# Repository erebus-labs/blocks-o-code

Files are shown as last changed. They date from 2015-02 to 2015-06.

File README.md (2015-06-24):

blocks-o-code
=============

#A Block of Code
+ *Title:* Physical manipulators for developing and implementing short programing routines 
+ *Project Short Name:* A Block of Code (ABC)
+ *Sponsors:* 
  + [Dr. Mike Borowczak](https://www.linkedin.com/in/mborowczak) @ [Erebus Labs](http://www.erebuslabs.com)
  + [Dr. Andrea Burrows] (http://uwyo.academia.edu/AndreaBurrows) @ [University of Wyoming] (http://www.uwyo.edu/seced/faculty-staff/andrea-burrows.html)
+ *Senior Design Team:* 
  + Jacob Mickiewicz 
  + Tyler Hart
  + Daniel Frister
  + Greg Stromire
  + Nathan Bryant
+ *PSU Academic Advisor:* [Roy Kravitz](http://www.pdx.edu/directory/name/roy_kravitz) 
+ *Targeted Users:* Infants to High School aged children, parents and their educators

##About A Block of Code

Blocks of Code are connectable “blocks” that mimic a simple-grammar programming language. 

The fundamental grammar contain 4 types of blocks:
+ Value Blocks
  + numbers (ints/doubles) – stringing these blocks together forms longer numbers [0,1,2,3,4,5]; [6,7,8,9,.]
  + variables
+ Operator Blocks
  + simple binary operators (*,/,-,+,%?): 
  + equivalence operators (<,>,==, !=,<=,>=)
+ Control Blocks (start and end)
  + if structures
  + while structures
  + explicit encapsulation ( )
+ Output Blocks

##Background

Algorithms, logical constructs and the foundations of programming are generally limited to computer-based instances. No physical manipulators exist that expose children to programming as they do for number and alphabet systems, mechanics, art, etc.  Build a prototype for building blocks that can be attached through internal magnets, these magnets perform two actions 
1. physical connection and 
2. logical circuit connections.

##Current Feature List
- [x] Open Source Hardware Design & Board (can use “closed source” components: ASICs, uC, etc.)
- [x] Must Have a Multi-Chip solution – e.g. no single SoC;
- [x] Fundamental grammar functioning; assignment; binary operators; 
- [x] Open Software Repository (github)
- [x] Multi-function blocks – e.g. 6 (or 4) binary operators on a single block; depending on connections/which side “faces up” operation changes 
- [x] Separate “power” blocks

##Wish List
- [ ] Hardware cost <$3 per unit (average cost for a set 20 = $60)
- [ ] Unexposed Connectors (e.g. Magnetic  + Inductive coupling between blocks?)
- [ ] Power: Ultra Low power operation
- [ ] Power
  - [ ] Built in power source / power pack
  - [ ] Built in power source w/inductance recharge
- [ ] Computer GUI/Phone App:
  - [ ] simulate a set of blocks (pre build) 
  - [ ] take a picture of a set of blocks and execute code (they don't even have to be REAL blocks - could be paper!)

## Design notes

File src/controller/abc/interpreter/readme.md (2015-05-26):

# A Block of Code Emulator
```
usage:
    abc                  Start interactive mode
    abc /path/to/file    Run file
    abc -h               Display this help
```

Alternatively, do a full install and use a hashbang on the first line of
your script:

```
#! /usr/local/bin/abc

<your code goes here>
```

Then make your script executable with `chmod +x /path/to/your/script`. It
will be interpreted just like any other script.

## Building
Building relies on `bison` (>3.0 for '%precendence' directive)  and `xxd`
AND `flex` (and of course `make` and `gcc`, along with gnu `libc`. If
you've ever used a Makefile on your machine, you probably already have
these.

Just run `make` to build, then `sudo make install` to install. The default
path is `/usr/local/bin/abc`

### OSX Specific
Default `bison` version = 2.5 < 3.0. This will require manual update, or
installation through favorite add on package management tool (port, brew,
etc). The following assumes the use of Brew, which installs to
`/usr/local/opt/bison/lib`

```
brew tap homebrew/dupes && brew install bison
```

## Syntax
#### Blocks
* ~~**Line Start** - has an LED indicating if the statements on the line produce
an error, could also provide power.~~

* **Variable** - a list of 8 named variables (`count`, `sum`, `a`, `b`, `c`,
`x`, `y`, and `z`), selectable by pressing a button on the block to cycle
through values, with an LED showing which is currently selected.

* **Number Selection** - a small LCD screen shows a value that can go from 0.0
to 9.9 decimal, then from 10 to 99 integer by rotating an adjacent knob.

* **Operator** - a list of 6 operators (`+`, `-`, `*`, `/`, `^`, and `%`) and
their 6 compound assignment counterparts (`+=`, `-=`, `*=`, `/=`, `^=`, and
`%=`) selectable by pressing a button on the block to cycle through values, with
an LED showing which is currently selected.

* **Integer Constant** - a constant integer block for common use numbers (`1`,
`2`, `5`, and `10`).

* **IF** - starts an if-statement, must be followed by a conditional statement,
some statements, and END IF.

* **END IF** - ends the statement list for an if-statement.

* **Condition** - a list of 6 comparison operators (`==`, `!=`, `>`, `<`, `≥`,
and `≤`), selectable by pressing a button on the block to cycle through values,
with an LED showing which is currently selected.

* **WHILE** - starts a while-statement, must be followed by a conditional
statement, some statements, and END WHILE.

* **END WHILE** - ends the statement list for an while-statement.

* **Actuators** - syntactically similar to functions: take parameters
(right-adjacent blocks) and perform a task. Shown in picture:

  * `say(number)` - ~~takes a number as a parameter, uses speech synthesis to
say the number through the on-block speaker.~~ Prints to stdout.

  * ~~`blink(integer)` - takes a positive integer as a parameter, blinks the
larger on-block LED that number of times~~

* ~~**Output** - larger LCD screen can show `stdout`-type print statements,
errors and hints, or other messages after pressing the `GO` button.~~

**Total Blocks**: 35 - could remove the 8 Line Start blocks to get to 27 total blocks.

#### Connection Indicators
Blocks have connection established LEDs indicating power and/or data connection.
Some only have left and right side connections available (operators, constants,
etc) while others have left, right, top, bottom connections available
(variables, control flow) which helps guide students to start lines with the
correct type of block. This prevents lines such as:

```
+ 5 * 9 = x
```
Also, while the following is valid in some programming languages:
```
3 + y
```
the resultant value is ignored, and this layout can help prevent such
unnecessary statements.

#### Terminators
There are no semicolons or terminating whitespace (but there are curly braces to
help with proper nesting). Statements can be determined by the block with the
right connector open (o).

#### Immediate Feedback
More verbose error checking for the software implementation is a TODO item - *Tylo*

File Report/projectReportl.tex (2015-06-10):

\documentclass[12pt,a4paper]{article} 
\usepackage[latin1]{inputenc}
\usepackage{pdfpages}
\usepackage{graphicx}
\usepackage{float}
\usepackage{amsmath} 
\usepackage{amsfonts} 
\usepackage{amssymb}
\usepackage{color}
\usepackage{multicol}
\usepackage{multirow}
\usepackage{makeidx} 
\usepackage[english]{babel} 
\usepackage[hidelinks]{hyperref} 
\usepackage{array}
\usepackage{blindtext}
\usepackage{setspace}
\usepackage{parskip}
\usepackage{pstricks}
\usepackage{textcomp}
\linespread{1.1}
\begin{document}
\definecolor{PSU}{RGB}{75,125,50}
\begin{titlepage}
\begin{center}

% leave tilde after graphic, it designates par format, needed for formating
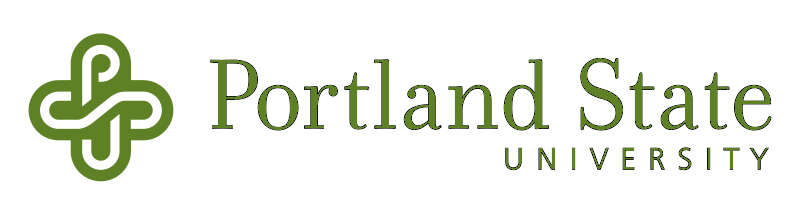
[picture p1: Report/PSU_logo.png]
~\\[.5cm]

\textsc{\LARGE \color{PSU} Maseeh College of Engineering}\\[1.5cm]

\textsc{\Large Project Summary \& Report}\\[0.5cm]

\vspace{1cm}
% Title

{ \huge \bfseries\color{PSU} A Block of Code\\[0.4cm] }
  \large Senior Capstone Project

% \hrule
\vspace{2.5cm}
% Team Members
 \begin{multicols}{2}

\begin{flushleft}
\noindent
 \large
\emph{\color{PSU}Team Members:}\\
Nathan \textsc{Bryant}\\
Daniel \textsc{Frister}\\
Tyler  \textsc{Hart}\\
Jacob   \textsc{Micikiewicz}\\
Greg    \textsc{Stromire}\\
\end{flushleft}

 \begin{flushleft}
  \large
 \emph{\color{PSU}Erebus Labs:} \\
 Dr. Mike  \textsc{Borowczak}\\
 \emph{\color{PSU}University of Wyoming}\\
 DR. Andrea \textsc{Burrows}\\
 \emph{\color{PSU}PSU Advisor:}\\
 Roy \textsc{Kravitz}
 \end{flushleft}

 \end{multicols}`
\vfill

% Bottom of the page
{\large \today}

\end{center}
\end{titlepage}
 \tableofcontents
 \vfill

\section{Abstract}
We prototyped a low-cost, tactile teaching aide capable of helping a wide range of K-12 students explore the concepts of computer programming. Using a set of physically manipulatable blocks, students can perform basic programming operations and interact with the programs they create. Verification of valid code structures provide immediate feedback for rapid learning and control of simple and fun outputs connected to the system guide students toward a goal for their projects. 

Each of our blocks is a 4-layer PCB, enclosed in an acrylic box, with an ATtiny461a microcontroller and 3 LEDs to indicate power, status, and errors. A 1M$\Omega$ potentiometer, with an attached acrylic wheel, is connected to the microcontroller\textquotesingle s ADC to act as a selector for a block\textquotesingle s particular function, or token. Each block communicates over a limited SPI bus to two adjacent blocks to determine topology, and communicates back to a main processor over a TWI global bus. Our main processor board is a BeagleBone Black with a common Debian distribution running a Python-based lexer, Bison-based parser, and C-based interpreter to run our simplified grammar. The results are supplied to an output pipeline to drive modular components such as an LCD screen or an RGB LED, as well as send feedback directly to the blocks via their onboard LEDs. 

The end product is a set of blocks that introduce computer programming to students for whom traditional teaching methods are ineffective, or would otherwise have no exposure, and encourages all students to pursue education in STEM.

\section{Introduction}
\subsection{Motivation}
Introducing students to programming and computer science is vital in our increasingly connected world. Yet the tools and educational methods to familiarize young minds to STEM subjects have not kept pace with the technologies themselves. The typical CS learning experience in front of a computer screen only engages a select few students with a compatible learning style, and often schools struggle to afford the necessary resources and computer labs. Our goal was to create an interactive learning tool that can engage a wider range of students for presenting computer science concepts.
\subsection{Proposal}
The package will be a set of twenty to thirty cubes at around two inches across on a side. The set will function as its own interface device, where the topological arrangement of the elements (blocks) will determine the program. The individual blocks must be identifiable as belonging to a specific programming-construct group, such as a simplified programming grammar. At a minimum these groups must include; numbers, variables, operators, and controls.

Additionally, where necessary, a block should be capable of indicating what value or function it has been assigned. Blocks should be easy to connect, allowing users to experiment with layouts, and also provide area-specific error feedback and thereby increasing understanding and limiting confusion.

Finally, the set should be open-source and sufficiently accessible, both by cost and teaching use, as to promote universal access and encourage development and expansion by the general public.

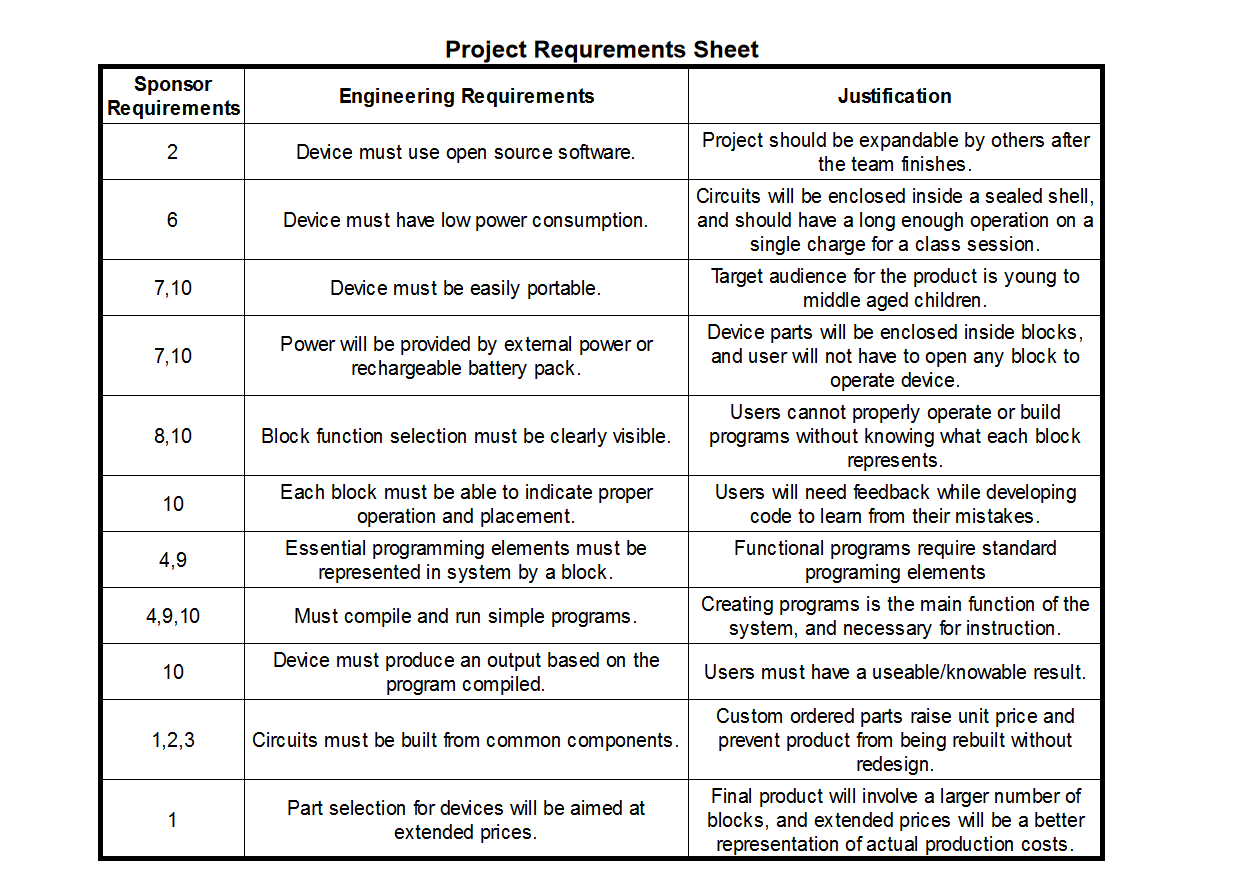
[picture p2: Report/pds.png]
\\
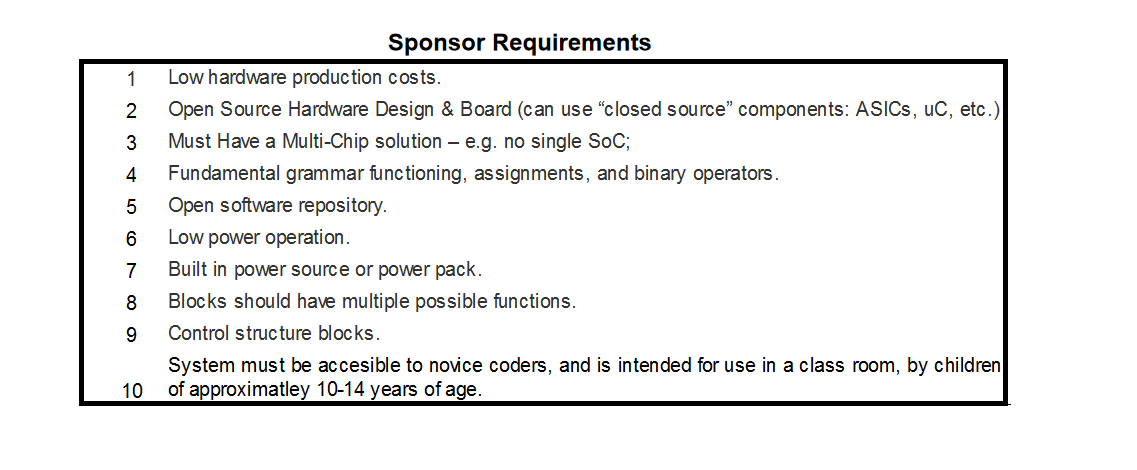
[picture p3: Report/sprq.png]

\section{Project Planning}
We identified three main elements for our system design: Physical Construction, Block Communication, and Program Interpretation. This enabled us to research and develop each subsystem in parallel with regular inter-group updates to stay unified on task. We also set several early milestones to ensure successful integration and to allow for multiple, iterative design revisions.

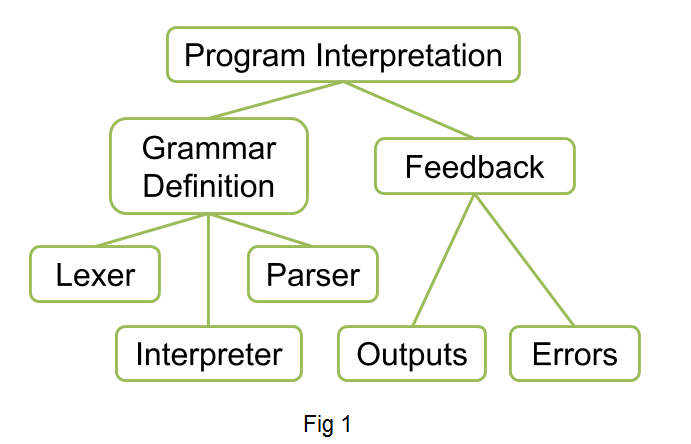
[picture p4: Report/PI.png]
\\
\newpage
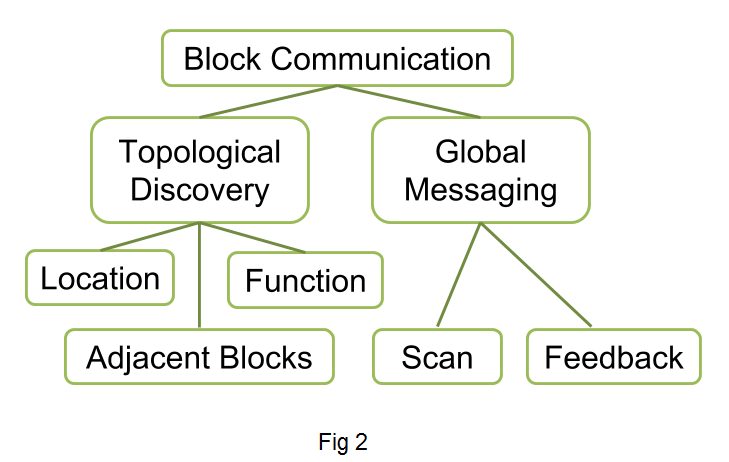
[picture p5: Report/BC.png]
\\

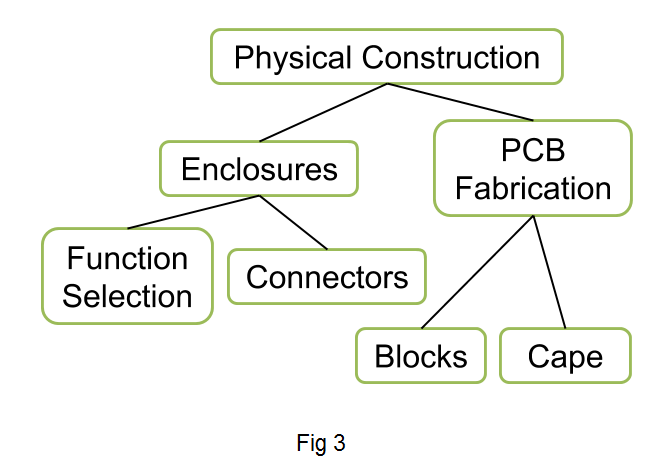
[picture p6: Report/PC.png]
\\

With these divisions the work was scheduled based on skill, interest and load leveling.

\includepdf[pages={1-}]{shed.pdf}
\section{Methods and Tools}
We utilized several methods and tools during all phases of the project, and some were used only for specific phases. We each used a mix of Windows, Macintosh, and Linux workstations throughout the project. We also used the AVR Toolchains (CrossPack, avr-gcc, avrdude) and the AVRISP MKII programmer in development, manufacturing, and testing. The BeagleBone Black was another major part of our full project cycle.

For our development phase, we utilized EagleCAD to design and layout prototype PCBs. We then moved to DesignSpark to allow us to develop 4-layer boards and reduce the surface area for a cheaper design. We employed an Arduino Uno and associated IDE to develop the TWI bus, initially with the smaller but compatible ATtiny85. We also used an Intronix Logicport 34-Channel Logic Analyzer to inspect communications, albeit much later in the process than necessary. We used a 3D printer to prototype a potential selector wheel.

During our manufacturing phase, we used the Portland State University Laboratory for Interconnected Devices to assemble both revisions of our prototype. We used their Torch T200N Reflow Oven to solder our second revision surface mount components. And we used their Full Spectrum Professional Series CO2 20x12 Laser to cut acrylic enclosures and selector wheels. We also used a handful of other Portland State tools such as soldering irons and a dremel. 

To test our final boards, we used a microscope to inspect solder connections and then a general purpose multimeter to verify conductivity and isolation. We then used an Arduino Uno\textquotesingle s regulated 3.3V output to supply power to a single and then a subset of blocks to confirm connectivity. We also wrote several scripts and test programs to explore the bounds and verify functionality of our set using an Arduino, a BeagleBone Black, and the blocks themselves.
\section{Implementation}
Our first development goal was a set of blocks that could identify their topology and return their token to a main processor. Though a \textquotesingle smart-mat\textquotesingle design was considered, we decided it would be too dimensionally restrictive. We chose AVR microcontrollers and DB-9 connectors for their ease and cost. We utilized a localized SPI communication to establish location and a global TWI bus to report the block\textquotesingle s assigned value. We then selected a Linux-based single board computer to harness existing language parsing and interpretation tools. The BeagleBone Black provided this at reduced power.

Our second set of development goals aimed to the increase block-set capability, provide portability, and expand the available output options:
\begin{itemize}
	\item User-selectable subset of functions rather than a single, hard-coded token
	\item BeagleBone Controller Cape for power distribution and control of a global reset
	\item Additional modes of output connected to the Controller Cape to support student engagement in learning programming concepts
	
\end{itemize}
Each block is controlled by an ATtiny461 microcontroller, connected to two neighbors on a local bus based on SPI, and connected to all other blocks and the BeagleBone Black on a global bus using TWI. Both of these busses, as well as power and ground, are brought onto the block via a standard DB-9 connector. The token selector wheel is mounted on a 1M$\Omega$ potentiometer which feeds into the ADC on the microcontroller.

The local bus is started from the BeagleBone and initiates a handshake with the block connected below it. When the handshake completes, a vector is passed indicating the x- and y-coordinates of the sending block. The receiving block increments the vector based on whether the sending block is signaling from the above or the left line of the receiving block, and then stores and sends the incremented vector to the next block. The received vector is then translated into the TWI address on the global bus. The BeagleBone Black is able to query each block which responds with information on its adjacent blocks, its wheel category, and its current ADC value. The BeagleBone Black lexer uses this response data to construct a topology of the current block arrangement. It then passes this information to a parser and interpreter to generate the appropriate output such as driving a LCD screen.
\subsection{Block}
    The primary function of each block is to report back to the main processor board its own user-selected function as well as its adjacent blocks. This allows the main processor to collect the tokens and topological information necessary for constructing the user-generated program. A block progresses linearly through a series of states as outlined in the state diagram, Fig 4, on the following page.
  \subsubsection{Adjacent Blocks}  
  First, the block will execute an initialization sequence that includes outputting to and reading from its adjacency lines. In typical usage, the blocks are built in a top-down orientation. A pair of slave-select pins, connected to the right and bottom connectors, are designated temporarily as inputs with their internal pull-up resistors enabled. Another pair of slave-select pins, connected to the left and top connectors, are designated temporarily as outputs and immediately pulled low. 
  
  For an example, consider the top block in Fig 5. If the block reads its adjacency pins and finds that its h\_out line (horizontal output) is HIGH, then it has no block connected to its right (again, in a top-down orientation). If it reads its v\_in is LOW, then a block is present below it. These values are stored and supplied to the main processor board in a global bus response (see TWI Commands).
  
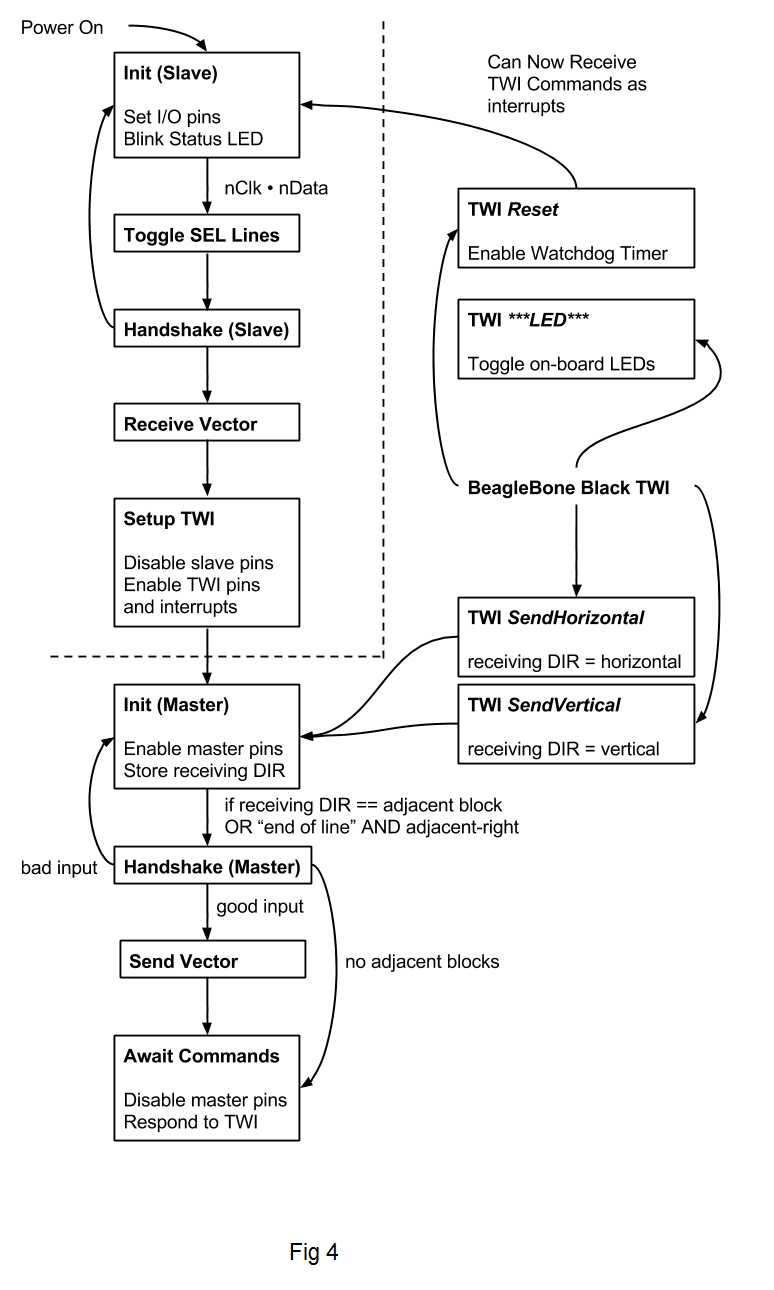
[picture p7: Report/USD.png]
    \\
    
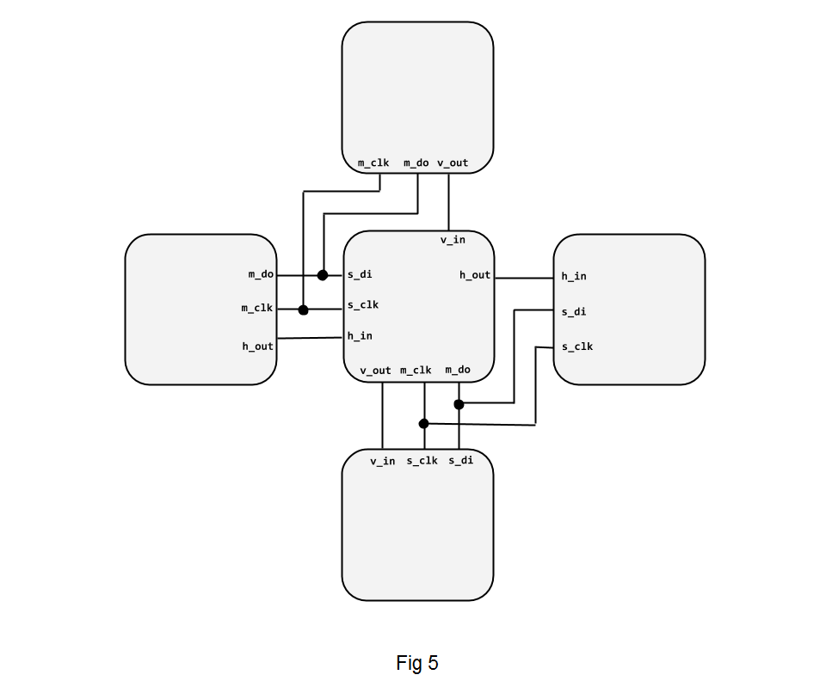
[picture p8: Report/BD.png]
 
 \subsubsection{Handshake}
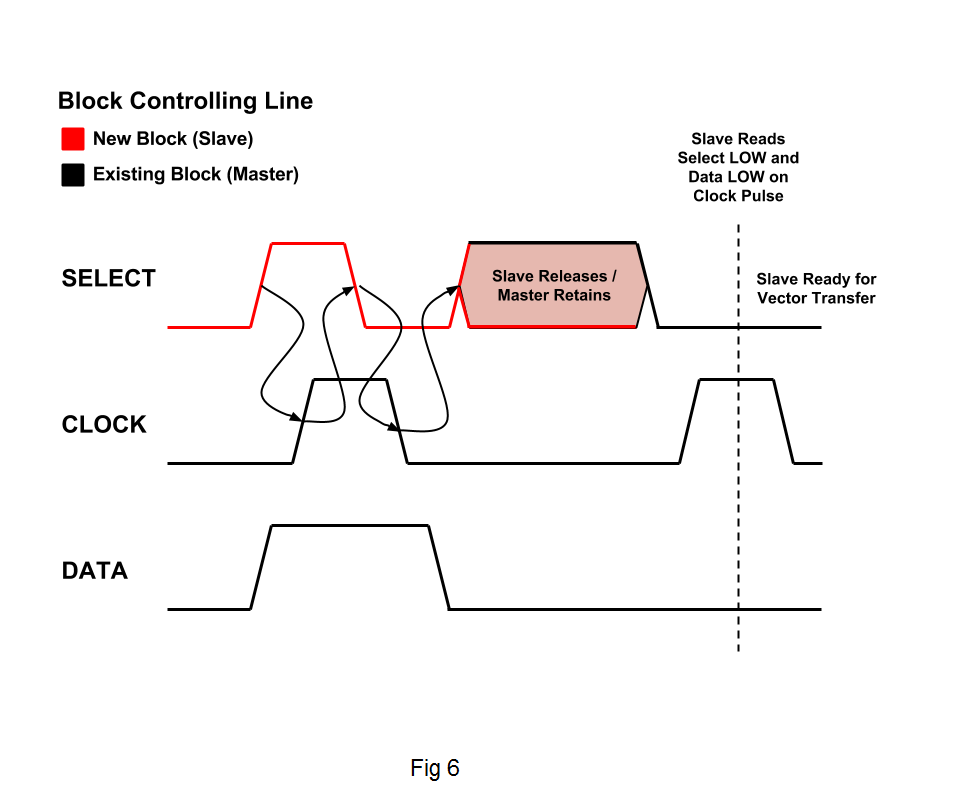
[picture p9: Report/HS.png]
 \newpage 
 After the block is powered on and has executed its initialization sequence, including determining adjacent blocks, it prepares for a custom handshake to initiate a SPI transmission. Shown above is this handshake, where the just-powered-on block is considered the slave, and another block or the BeagleBone Black is considered the master. 
 
 \begin{enumerate}
 	\item First, the block will wait for the shared clock and data lines to go LOW. This will signal the block to start toggling its own select lines (v\_in and h\_in). 
 	\item The master will then respond to the toggle that it sees (either horizontally or vertically) by bringing clock and data HIGH. 
 	\item This triggers the select line LOW again and the clock and data lines again follow. 
 	\item Next, the slave block brings its select line HIGH yet again but then releases control of it by switching the pin to an input and enable its internal pull-up resistor. 
 	\item The master waits a short delay after seeing that rising edge then it changes its corresponding select line from an input to an output and pulls the line LOW. 
 	\item A final clock pulse acts as a verification of the completed sequence before both blocks are prepared for a traditional SPI transmission.
 \end{enumerate}
 
 It is possible that an adjacent block could see the same clock and data lines go LOW and in fact complete almost the entire sequence. But the corresponding select line would not be held low on that final clock pulse and thus that block would recognize that the sequence was not meant for it, and reset its state. The same is true for any other sequence of edges that doesn't follow here -- it would be considered bad input and cause a reset to initial handshake state.
 \subsubsection{SPI Transmission}
 Once a block has completed its handshake, it is prepared to receive data over a three-wire SPI protocol. This means there is no MISO signal involved. After the data is received, the block is able to continue to send the data to adjacent blocks as necessary. It will continue the direction it was originally sent (e.g. if received from above, send below; if received from the left, send right). 

 It will also recognize when it is considered the \textquotesingle end of the line\textquotesingle  , which is considered the block with x-coordinate of 0 and no blocks connected below it. In this special case, it will then send to the right if there is a block present. 
 Finally, a block will send in the vertical or horizontal directions on command from the global TWI bus (see TWI Commands). 

 Below is a screen capture from a logic analyzer showing 3 different SPI transmissions (in this example, blocks are implemented in a bottom-up orientation). The first transmission is to the current block which is acting as a slave and receiving data. The handshake begins at about the -200ms mark and completes roughly at -135ms mark. The actual transfer is shortly after that. The second handshake begins immediately and two lines do in fact follow the sequence, but only one has its line low when a second clock pulse \textquotesingle confirms\textquotesingle  the exchange. Finally, a TWI command is issued at about the -10ms mark to complete that last SPI transmission.\\
 
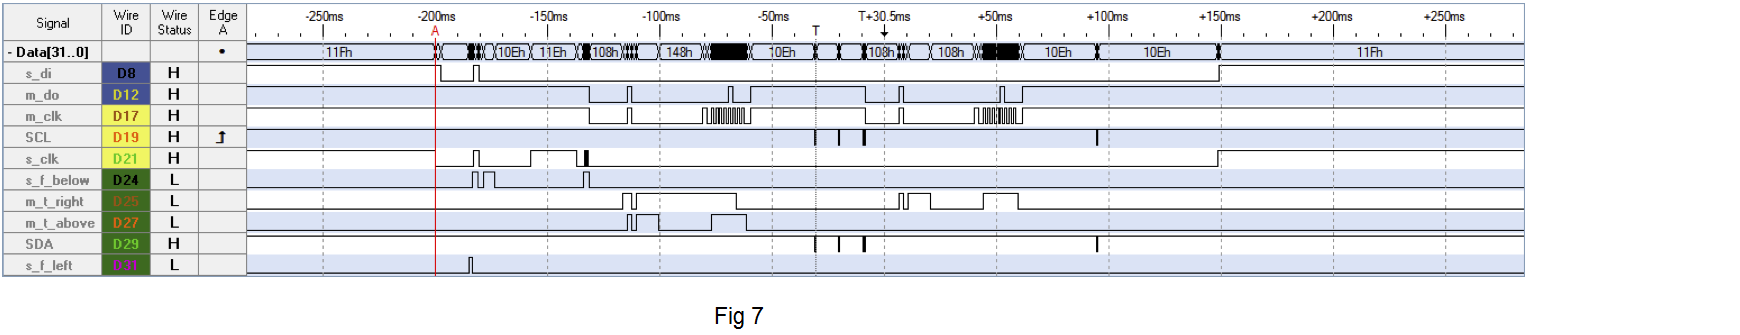
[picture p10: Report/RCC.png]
 
  The data transferred is an encoded vector indicated the sending-block\textquotesingle s coordinates in the xy-plane of the user-program\textquotesingle s topology: the first 3 bits are the x-coordinate, and the next 4 bits are the y-coordinate. The receiving block will add 1 to the x- or y-coordinate it received, depending on from which direction it was sent. If an overflow will occur (e.g. if the block receives a x-coordinate of 7 from the left, it would increment to 8 which would overflow beyond the allotted 3 bits), then the process is aborted and an error indicating LED will blink to indicate the error condition. Otherwise, this encoded and incremented vector becomes the address of this block for a Two-Wire Interface global bus.
  
  \subsubsection{TWI Commands}
  The TWI interface allows targeted commands to trigger a handful of actions. The BeagleBone Black issues a TWI read request indicating an address (block) and a register (command). These numbers act as virtual registers on the block and are captured to issue tasks in a work queue. Below is a table of all the implemented actions. 
  
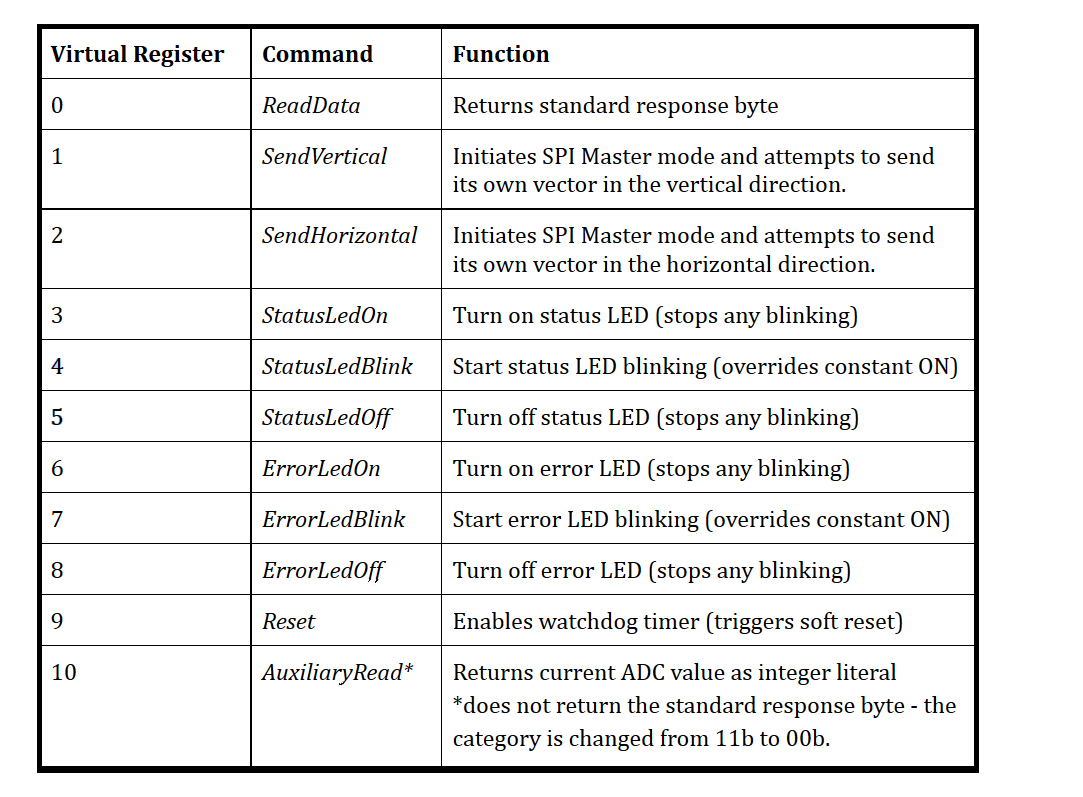
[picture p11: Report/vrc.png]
  
  Each command (except for number 10) returns a response byte that shows the current status of the addressed block. This byte is described below:
    
    
    \newpage
    The most significant two bits are flags indicating if the current block has adjacent blocks connected in the vertical and horizontal directions respectively. The next two bits identify the category (or wheel) that is used for this block. And finally, the remaining four bits are the most significant 4 bits from the ADC read from the potentiometer. This indicates the user-selected token and, combined with the category identifier, indicates the exact token to be used in the parser. 
    
    \subsection{Processor Board}
    \subsubsection{Lexer}
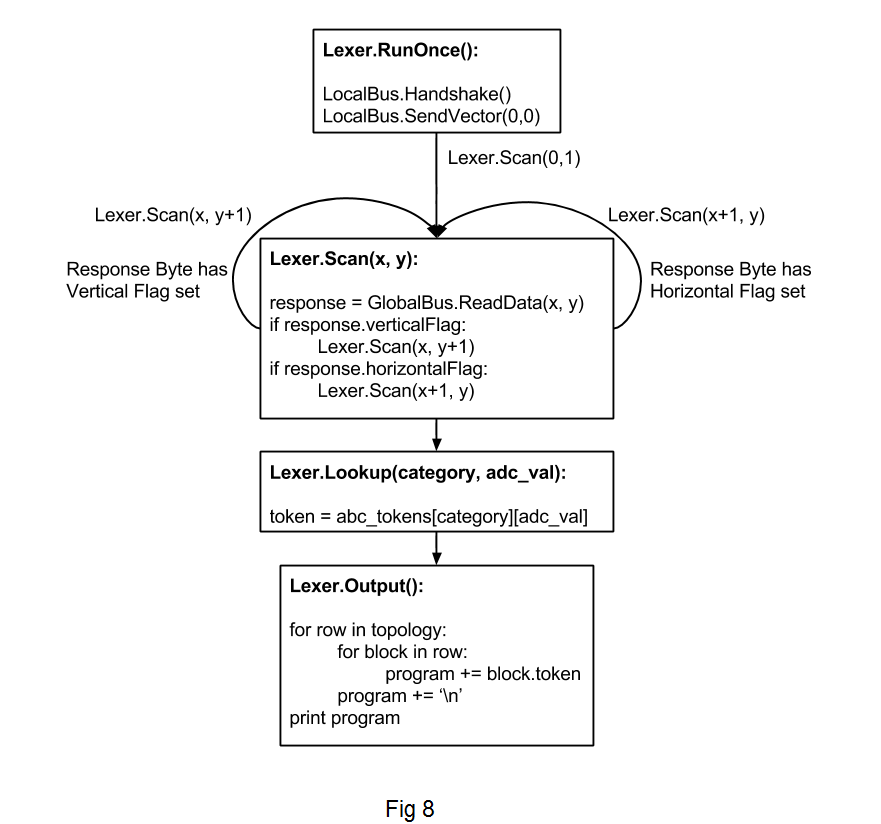
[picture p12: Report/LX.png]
    
    The lexer on the BeagleBone Black utilizes both the local SPI-based bus as well as the global TWI-based bus. The BeagleBone Black initiates a standard handshake, as described above, and sends its own coordinate of (0, 0) to the connected block. This starts a chain of sending vectors to the \textquotesingle end of the line.\textquotesingle   The lexer then uses the TWI to query the first block with a ReadData command, and recursively traverses the topology according to the vertical and horizontal adjacency flags in the response byte. 

    For each block response it receives with the vertical flag set, it queries the next vertical address until it receives a response without that flag set. It then sends a SendHorizontal command to the next block with a x-coordinate of zero and a horizontal adjacency flag set. The lexer queries that row until it gets to the end and then sends the next SendHorizontal command as necessary. This collects all the blocks (including their categories and ADC values). Each block\textquotesingle s ADC value and category is used as keys to a master token lookup table, shown in the table on the following page.     The lexer then prints a string constructed from the mapped tokens to stdout which is captured by the parser / interpreter.

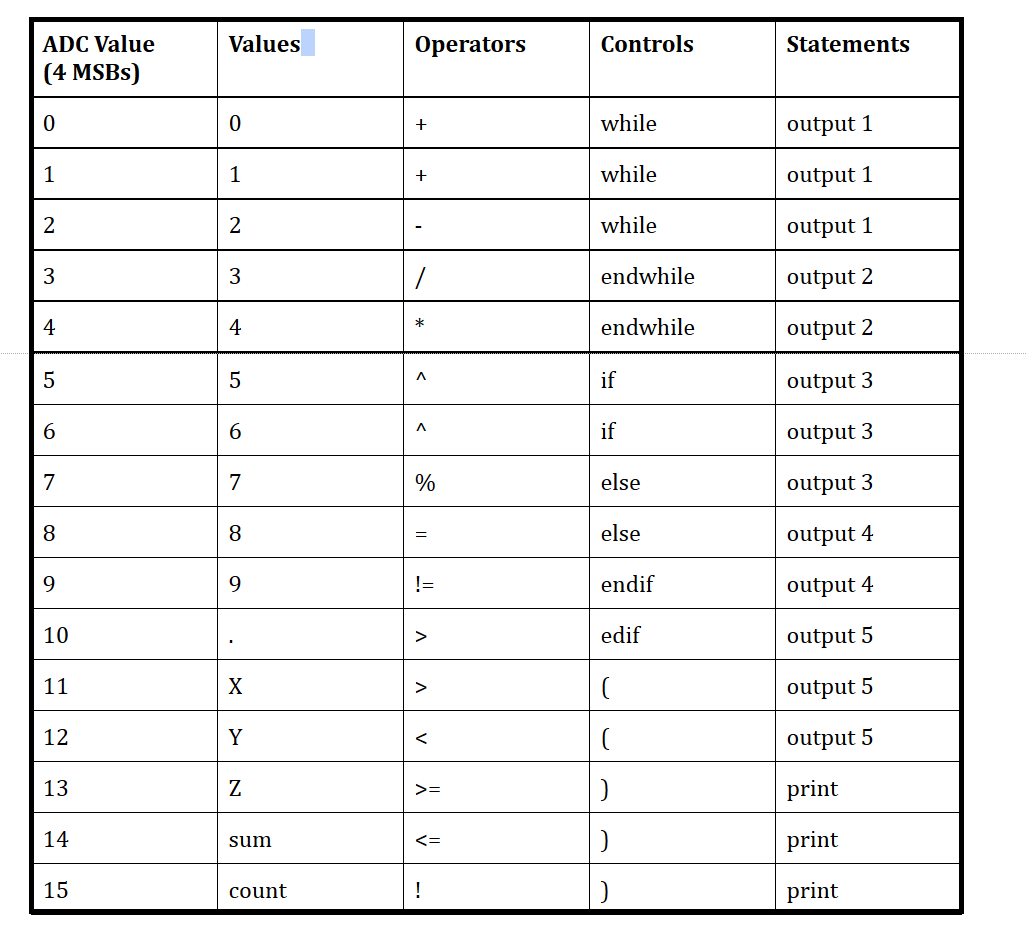
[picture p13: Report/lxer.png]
     
     \newpage
   \subsubsection{Parser}
   The parser is implemented using GNU Flex and Bison. Bison is used to allow rapid changes to grammar rules once physical manipulators are tested to give feedback to drive iterative redesign of the language. Flex is used to tokenize literals from the input stream and ease case-insensitivity of the language\textquotesingle s keywords.

   \textit{\textbf{Tokens}}
   
   Tokens patterns are expressed as regular expressions and are available in the appendix. Non-tokenized patterns that are in the source code are omitted for brevity. These patterns are used for ignoring certain patterns or implementing parser control patterns.
     
      \textit{\textbf{Grammar}}
      
      The Bison based parser builds an abstract syntax tree whose structure can be modeled with a 1-to-1 mapping with the grammar rules. The grammar rules are provided in the appendix.
      \subsubsection{Interpreter}
      The interpreter receives the root node from the parser, which is a STATEMENT\_LIST and descends it directly. The interpreter follows each node in the list and evaluates each node, discarding any return values and performing each node\textquotesingle s side effects.
      
      Each operand in the statement in the statement list is recursively evaluated as expressions, until a terminator is reached. Terminators are type NUM and VAR.
      \subsubsection{Output Pipeline}
      
       Outputs from the interpreter are put on stdout in the form: \begin{verbatim}
       #OUTPUT(CHANNEL, VAL)
       \end{verbatim} The orchestration script pipes the output of the interpreter through a pipeline of output modules.
       
       The output modules are written in Python and read from their stdin. They echo everything they read from their stdin to their stdout except for their corresponding \#OUTPUT control codes. When the output module reads an output control code, it performs an action.
       
       The following outputs modules were written. Of the output modules written, the LCD Text module and LCD RGB Backlight module were demonstrated.
       
      \textit{\textbf{LCD Text}}
      
      An LCD attached to the control board is updated with the value given to the corresponding output block when the output statement is executed.
      
      \textit{\textbf{LCD RGB Backlight}}
      
      The LCD attached to the control board has an RBG LED used as a backlight which is updated with the value given to the corresponding output block when the output statement is executed. The modulo 7 of the value given is truncated to an integer which indexes a color in the following list: [red, orange, yellow, green, blue, indigo, violet].
      
      \textit{\textbf{Piezo Buzzer}}
      
      A piezo buzzer attached to the control board is buzzed a number of times corresponding to the value given to the output block when the output statement is executed. The number of beeps is ceiling 5.
      
      \textit{\textbf{Relay}}
      
      A relay attached to the control board is closed for a number of time units corresponding to the value given to the output block when the output statement is executed. A time unit is about a half of a second and is ceiling 5.
      
      \textit{\textbf{ Stdout}}
      
      The value given to the output block when the output statement is executed is printed to stdout in an informative way. 
      
      \section{Experiments and Testing}
      Testing of the equipment is broken down into two sections. The first section is hardware tests related to the construction of the blocks and cape. For our hardware test plans we implemented four different test plans. The first hardware test is the connectivity of an individual block. After this is complete the second hardware test is connecting a set of blocks together without connecting power. Connectivity is checked across the global busses to ensure that end to end connections exist throughout the block configuration. The third and fourth hardware tests are connectivity checks on the programmer header and output breakout cape.
      
      The second set of tests were to ensure that the software was loaded correctly and functioning as intended. Software test number one is a simple power on test of an individual block to ensure that it goes to the awaiting address state while not connected to the controller. Following this test a block is connected individually to the controller board to verify that it receives its address and indicates this on the status LED. Once these two tests were complete the final software test is connecting a syntactically correct line of code to ensure the controller and outputs are functioning as intended. 
      
      The detailed test plans are attached at the end of the document. 
     
     \section{Results}
     52 blocks, 3 programming headers, and 2 capes were made. These can control 4 different outputs with a Turing-complete grammar. Multiple functions are available on each block using 4 different selector wheels. A complete block set includes: 30 blocks with selectable functions, a Controller Cape for BeagleBone Black which supplies power and reset line to networked blocks as well as provides 4 default output components, and a programmer breakout for block updates. It is an open source project, both hardware and software, so all relevant documents, designs, and source code is available in a repository for the public to fork and merge. 
     The project requirements were all met: \textit{see Appendix I for Project Requirements Checklist}
     
     \section{Conclusions}
     \subsection{Lessons Learned}
     Throughout the project there were many areas that could be improved, but two of the design methods stood out when reviewing the project. The first of these is the tasking of multiple individuals or teams to develop ideas in parallel. Starting from the concept generation phase, ideas were developed and evaluated by one individual with only some discussion at group meetings, and often older ideas would be reevaluated with each potential roadblock that appeared. This showed that our group would have benefited from developing multiple ideas until it was clear one would be used in the final revision.  The second design method that was apparent after many of the revisions was that we repeatedly expanded our hardware capabilities to meet new needs. It would have been more efficient for the design process had a more complex set of equipment been selected that allowed the design to be finalized, and at that point trim down the hardware to only contain features required.
     
     In addition to improving the team\textquotesingle s design process, our project would have run more smoothly if we had allocated equipment earlier rather than later. Testing equipment was requested after discovering it was required, and some time was lost that could have been saved with some planning.
     \subsection{Future Work}	
     Based on the original project goals and initial concept generation, we propose several additions and refinements that may help the project serve its purpose. The first is reducing the cost-per-block. As the intention is to provide a tool for classroom use, keeping the cost-per-set low will make the project more economically accessible. The largest expense per block is the four connectors and the PCB itself. For reducing connector cost a pin increase to fifteen combined with an increased volume per order will reduce the cost significantly due to the fifteen pin version of the DB connector being a much more common part. The size of the wheels and blocks are limited by the size of the circuit board inside currently, so reducing circuit board size is not an easy modification, but changing the number of boards ordered per batch without a rush on the shipment will lower this expense as well.
     
     The second area of improvement for the blocks is the physical strength of each block of code. During our testing of the BlockBoard v2.2 circuit the stress on one of our connectors broke the solder joint on a support post. While this was partly due to the stiffness of the brand new connectors, we took additional steps to add reinforcement to the blocks before the demonstration. To reduce stress on the connector posts and make the blocks themselves more rigid an expanding glue was added on the seam between the connector and the printed circuit board. To prevent this in future versions a right angle DB connector that more closely mates to the circuit board could be used, as with our DB male connectors a slight gap existed between the housing and the circuit board that allowed the connector to rock back and forth when the connection was made.
     
     The third future goal is to improve the functionality of the block sets. The first method of expanding the set\textquotesingle s capabilities is to introduce input blocks to accompany the function select wheel. These blocks could quantize environmental characteristics such as ambient light and temperature to demonstrate programming interaction with the physical world for a more engaging learning experience. The second method of expanding the block set would be to allow for user defined functions. The method of implementation would be to add a user(\#) function to the output wheel, and instructing the controller to assign the current configuration of code to that function when it is received. This would allow programs that are not constrained to a limited number of blocks or wheel types, but rather to the memory of the controller. 
     
  \section{Appendix I: Project Checklist} 
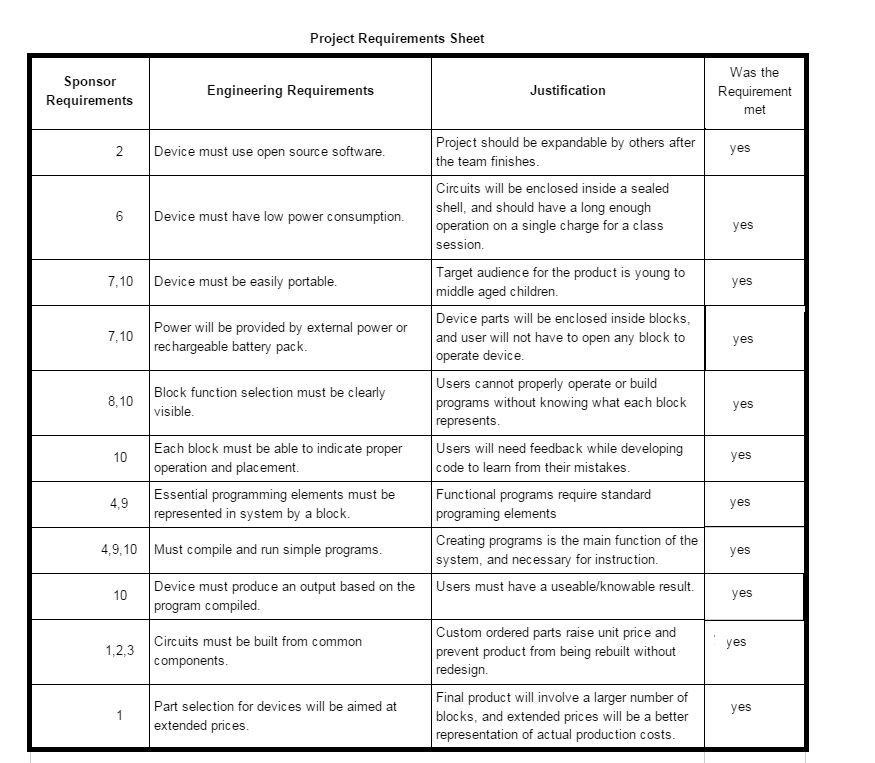
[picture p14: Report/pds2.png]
  
  \section{Appendix II: Token Patterns}
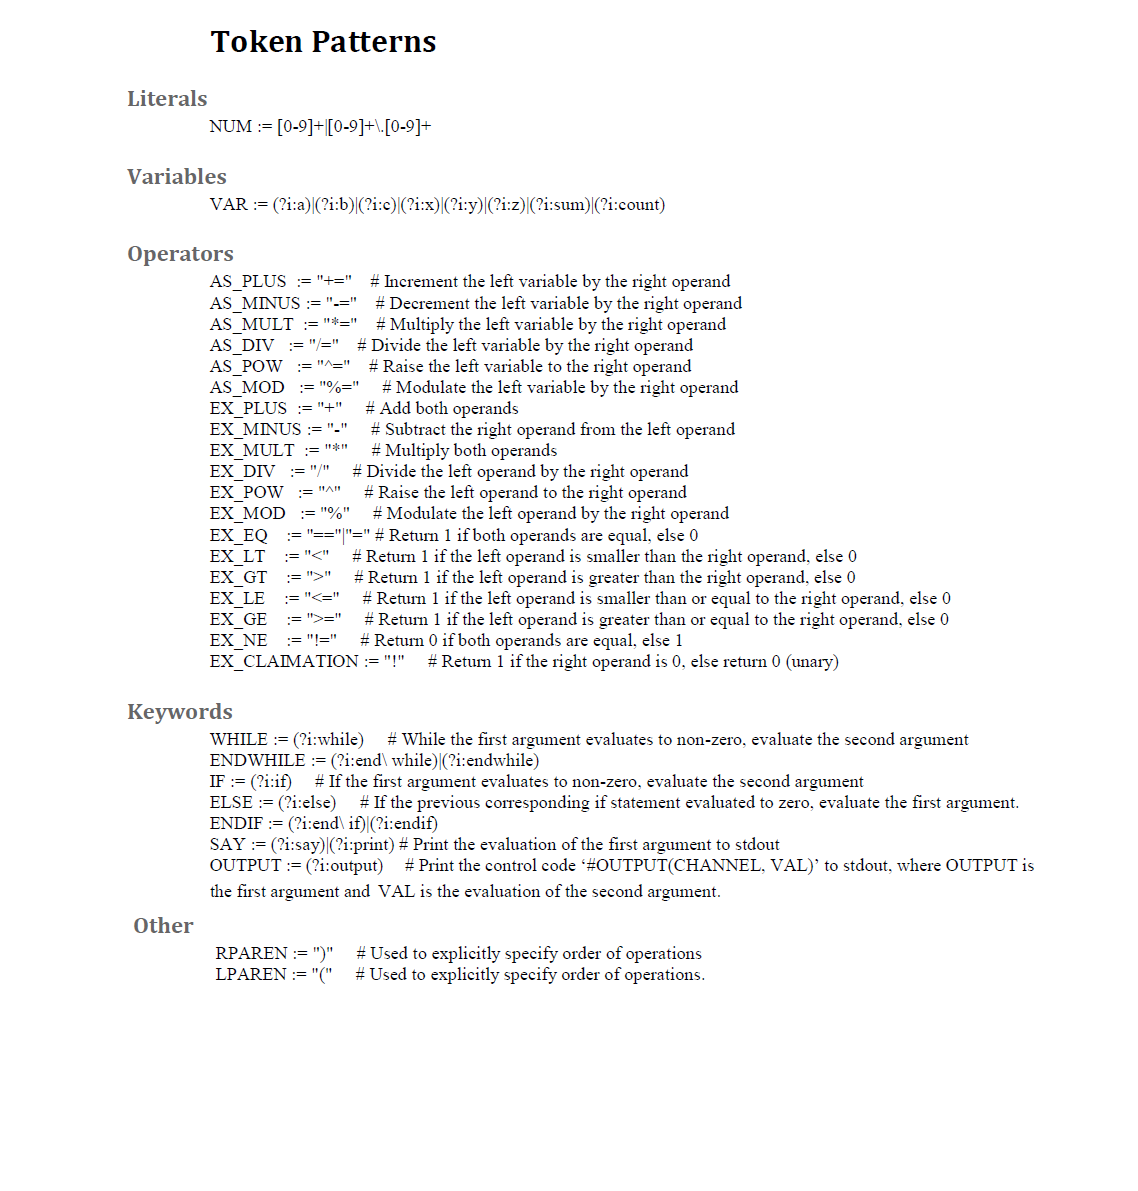
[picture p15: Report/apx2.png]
  
    \section{Appendix III Grammar Rules}
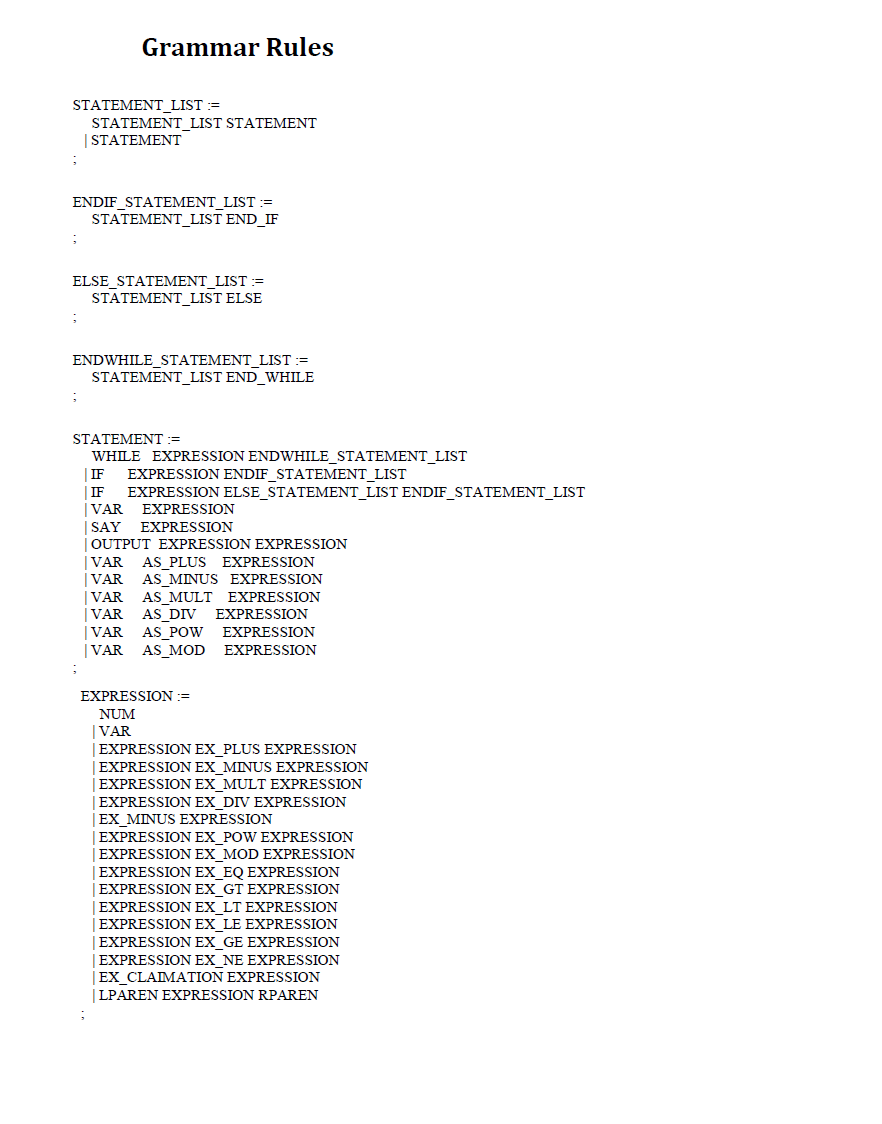
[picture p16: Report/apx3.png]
    
\section{Appendix IV: Test Plans}
\includepdf{HWtest1.pdf}
\includepdf{HWtest2.pdf}    
\includepdf{HWtest3.pdf}
\includepdf{SWtest1.pdf} 
\includepdf{SWtest2.pdf}  
\includepdf{SWtest3.pdf}  
\includepdf{SWtest4.pdf} 
\includepdf{SWtest5.pdf}       
\end{document}

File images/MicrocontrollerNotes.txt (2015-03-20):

Some notes on this diagram:
* Once a microcontroller has determined its address, it will enable its I2C port and attach itself to the shared bus. This allows the main processor SBC to regularly poll the bus for the correct devices.
* This diagram assumes that the main processor “block” is oriented at the bottom-left of the code blocks and the “program” will be built up from this origin, i.e. each block receives its position vector either from below or from the left. 
* This implementation allows us to utilize existing, supported, documented I2C drivers for both the microcontroller in a hardware-supported and interrupt-driven slave-mode and the SBC in master-mode.
* If the block is disconnected and reconnected it should return to the beginning state. This is now noted at the top by Reset.
* In a 2x2 example, the block at (1, 1) would get vect signals both from the left and from below. It could simply use the first one it receives and ignore the other, or it could use the second to confirm the correct position as they should generate the same coordinate value.
* Each microcontroller generates its own address from its position vector. A possible implementation is that the x-coordinate is the most significant 3 bits of the address, followed by the y-coordinate as the next 4 bits of the address, and the final bit (LSB) is the I2C R/W bit, per spec. For example, the block at position (2, 1) would have the address of: [010 0001 x]. This resolves to dimension limitations of 8 blocks long and 16 blocks tall, or a max 16 lines of code that are max 8 blocks wide. This is further limited by I2C reserved addresses. Other implementations could improve upon this.
* Once the block knows its function and its position, it is immediately available for I2C addressing from the SBC. Since the I2C communication will be interrupt-driven, the block can resume setting up after it services a message if it was received before it completed initialization. Possible commands could include:
   * Return this block's function code
   * Toggle this block's error LED
   * Reset this block
   * Etc.

Some pitfalls and mitigations for this implementation:

* Blocks may get stuck in different states. Reset triggers and watchdog timers can help alleviate some issues.
* The algorithm on its own does not determine end of line or completed search, the main processor block must poll regularly for block identities. This can lead to:
   * Stale function values
   * Wasted processing on both ends of the bus
Possible optimizations can be made by limiting poll to likely addresses (blocks starting at 0, etc)

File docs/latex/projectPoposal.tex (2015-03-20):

\input{start.tex}
\usepackage{pstricks}
\linespread{1.1}
\begin{document}
\definecolor{PSU}{RGB}{75,125,50}
\begin{titlepage}
\begin{center}

% leave tilde after graphic, it designates par format, needed for formating
~\\[.5cm]

\textsc{\LARGE \color{PSU} Maseeh College of Engineering}\\[1.5cm]

\textsc{\Large Project Proposal}\\[0.5cm]
\textsc{\Large Submission 1.0}\\[0.5cm]
\vspace{1cm}
% Title

{ \huge \bfseries\color{PSU} A Block of Code\\[0.4cm] }
  \large Senior Capstone Project

% \hrule
\vspace{2.5cm}
% Team Members
 \begin{multicols}{2}

\begin{flushleft}
\noindent
 \large
\emph{\color{PSU}Team Members:}\\
Nathan \textsc{Bryant}\\
Daniel \textsc{Frister}\\
Tyler  \textsc{Hart}\\
Jacob   \textsc{Micikiewicz}\\
Greg    \textsc{Stromire}\\
\end{flushleft}

 \begin{flushleft}
  \large
 \emph{\color{PSU}Erebus Labs:} \\
 Dr. Mike  \textsc{Borowczak}\\
 \emph{\color{PSU}University of Wyoming}\\
 DR. Andrea \textsc{Burrows}\\
 \emph{\color{PSU}PSU Advisor:}\\
 Roy \textsc{Kravitz}
 \end{flushleft}

 \end{multicols}`
\vfill

% Bottom of the page
{\large \today}

\end{center}
\end{titlepage}
 \tableofcontents
 \vfill

\section{Needs Statement}
Today's world is one of interconnected technologies, at the heart of which are devices like computers and micro-controllers. As the technological complexity of our world increases we will find our society increasingly reliant on the men and women who know how to operate and control these devices.

However as of today no universally accessible curriculum includes a focus on the knowledge and skills needed to program these machines. We have need of any system that can help children learn and understand these concepts. Additionally,  the long term effectiveness of any system will depend on both its ease of use and its accessibility across a large range of communities, especially those under financial duress.

\section{Objective}
The primary goal of this project is to create a low cost tactile teaching aid capable of helping a wide range of K-12 students learn the basics of computer programming. Our proposed teaching aid is a set of blocks that will allow students to  perform basic programming operations and assignments through the arrangement of the blocks. Verification of valid code structures will provide feedback for learning, and control of simple outputs connected to the system can give students a goal for their projects.
\newpage

\includepdf[pages={1}]{abcPDS.pdf}
\section{Background}

Currently there are limited methods of teaching  younger groups of students about computer programming, and those that do exist often rely heavily on access to computers. This project is meant to produce a learning aid that will function in a classroom setting, doing away with the need to have computers present for learning about programming.
The use of a visual-tactile system to teach new skills to children has a long and well established history dating at least as far back as Froebel, who believed that freedom to play and experiment, was essential to real learning.

 In terms of this project the system can be thought of as a, Froebel \textit{Spielgaben}, or a subject specific learning module. The purpose of which, is to allow students of any age to be introduced to coding, using a familiar process that promotes creativity. Allowing the module to be untethered, separate from a computer, will also allow the teaching of programming without the other distractions available on a PC, and give students that have trouble with abstraction a set of objects to focus on.

\section{Marketing Requirements}

The final package will be a set of between twenty to thirty blocks typically two or less inches across a side. The set will function as it's own interface device, where the topographical arrangement of elements (blocks) will determine the \textit{program}. The individual blocks must be identifiable as belonging to a specific programming construct-group. At a minimum these groups must include; numbers, variables, operators, and controls.

Additionally , if possible, a block should be capable of indicating what  value or function has been  assigned to it. Blocks should be easy to assemble,  allowing users to experiment with layouts, but provide area specific error feedback, thereby increasing understanding and limiting confusion.

Finally, the set should be open source and be sufficiently accessible, both by cost and teaching use, as to promote universal access and encourage development and expansion by others.

\section{Current Proposed Solutions }
  The current solutions we propose below are subject to change, as feasibility and effectiveness will become more clear as prototyping commences. Each level of description is limited to an overview of the specific proposed method. Each subsection is intended to create enough familiarity with the method described so that we can address associated \textit{Risk Management} in section 6.

\subsection{System Overview and User Interface}
 Our product will consist of identical \textit{blocks}, each with enough digital circuitry to accomplish the following;
  \begin{enumerate} 
  \item Electrically connect with each neighboring block,up to 4 blocks. \item Connect to a global buss, carrying system power and ground.
  \item Communicate over the global bus. 
  \item Obtain or store an objective value (its token ID) for the block
  \item Control a single LED.	 
  \end{enumerate}
   The block-to-block metal nets will form a mesh grid (local communication), while the  global bus will use an I2C(or similar) protocol. We will address this network as a \textit{matrix} for the rest of this document.
  \begin{figure}[H]
   \centering
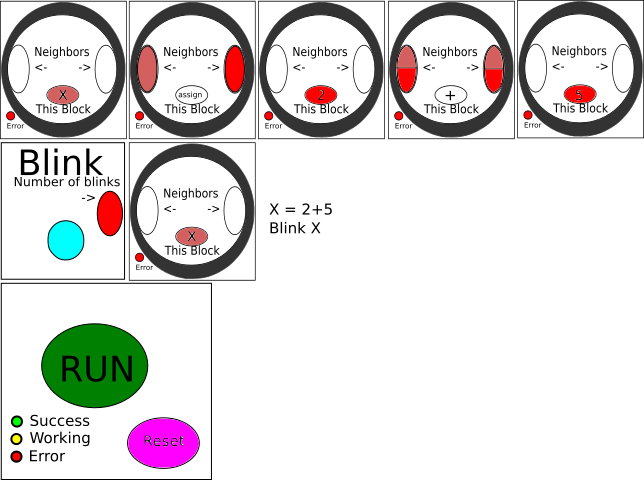
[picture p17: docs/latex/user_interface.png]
    
    \caption{Visual aid for section 5.1}
   \end{figure}

\vspace{.5cm}
The  \textit{\textbf{RUN}} block, or control block (see figure 1), has buttons to  force a reset or to attempt a run/ compile.  It also has LED indicators for relaying current status. It connects to the bottom most left most of the other blocks. \begin{verbatim}
<Note: the bottom is one possible configuration being considered> 
\end{verbatim}

Each programming block connects to its neighbors to form a program. The lines of  code are read from left to right, and lines are read one at a time from top to bottom. On each programming block a tunable wheel allows the user to select the meaning or \textit{value} of the block  in its \textbf{\textit{This Block}} window.  Users are given hints for which blocks ought to be placed to the left and right of the current block. Hints appear in the \textbf{\textit{Neighbors}} windows, and an LED will indicate error locality at the block whose sequence/ syntax is invalid when the program is run. 

Output blocks will have some way of acting on the world, such as a controllable light source, or a small speaker for sound. The interface to control  output is a separately connected  special \textit{output} block (not shown), which may be connected to the run/ control block.

  \subsection{Blocks And Communication: Software}
    Each block stores its own associated data. Each block stores a \textit{position vector}, which represents where on the matrix the block is located, and stores a \textit{unique ID}, which allows the block to be uniquely addressed on the global bus. Upon initialization, the position vector of each block is unknown.

    \subsubsection{Determining Location}
      The process for each block to identify its position vector is as follows:
      \begin{enumerate}
        \item First the positions of each block in column 1 are discovered:
        \begin{enumerate}
          \item The processing block passes a \begin{verbatim}<0,0>\end{verbatim} vector to its northern neighbor via the local mesh grid.
          \item Until the end of the column is reached, whenever a block receives a vector from its southern neighbor, each block increments the y component of its position vector, emits a message on the global bus containing \begin{verbatim}[position vector, unique ID]\end{verbatim}then passes its position vector to its northern neighbor.\\
          $**note$; \textit{the unique ID is generated and assigned by I2C }
          \item The last block on the column increments the y component of its position vector, then emits a message on the global bus containing \begin{verbatim}[position vector, unique ID, END_OF_DIMENSION]\end{verbatim}
        \end{enumerate}
        
      \item The processing block collects this info in its own local copy of the matrix.
      \item To identify each block in each row:
        \begin{enumerate}
          \item The processing block iterates over each Column 1 entry in its local-cache. Using the emitted Unique IDs for each entry, the processing block sends a \begin{verbatim}BEGIN_RASTER\end{verbatim}message to each Column 1 block via the global bus.
          \item When each Column 1 block receives a \begin{verbatim}BEGIN_RASTER\end{verbatim}message on the global bus, it passes its Position Vector to its eastern neighbor via the local bus.
          \item Until the end of the line is reached, whenever a block receives a vector from its western neighbor, each block increments the x component of its position vector, emits a message on the global bus containing \begin{verbatim}[position vector, unique ID]\end{verbatim}then passes its position vector to its eastern neighbor.
          \item The last block on the line increments the x component of its position vector, then emits a message on the global bus containing \begin{verbatim}[position vector, unique ID, END_OF_DIMENSION]\end{verbatim}
        \end{enumerate}
      \item Using the messages passed on the global bus, the processing block is able to fill in its local-cache with all of the Unique IDs of the blocks in the network.
      \end{enumerate}
       \begin{figure}[H]
         \centering
          
          \caption{Flow chart for sections 5.2 through 5.3}
         \end{figure}
  \subsection{Language, Parsing, Processing}
    After filling in its local-cache, the processing block can interpret the language in a traditional manner using a Lexer, Parser, and AST-Interpreter. This all happens in software.
    \subsubsection{Lexing}
      The processor is coded with an alterable lookup table containing the token associated with each Unique ID. The lexer does a raster scan on the processors local-cache matrix, and for each Unique ID it encounters, looks up the lexical value of the ID in the lookup table. The lexer hands this token, the value found (\textit{see section 5.1 item 1 and section 5.4}) to the Parser.
    \subsubsection{Parsing}
      The parser is a traditional LR parser that constructs an abstract syntax tree from the lexical tokens handed to it by the lexer. It passes the root of the abstract syntax tree to the interpreter.
    \subsubsection{Interpretation}
      The interpreter descends the abstract syntax tree \textit{\textbf{(AST)}}, performing the actions associated with each node.
 \begin{figure}[H]
   \centering
 
    \caption{Flow chart for 5.3.3}
   \end{figure}
\subsection{ Visual Feedback}
Currently the scheme for allowing the user to set the  block token (see 5.3.1) to be handed to the parser involves a system of selectable visual cues on the top face of the block. A potentiometer will be attached to a coded wheel that sits under the top face of the block, with a radius such that just the edge of the wheel may be manipulated by the user through a cut out on the side face of the block (see figure 4 below).

 \begin{figure}[H]
   \centering
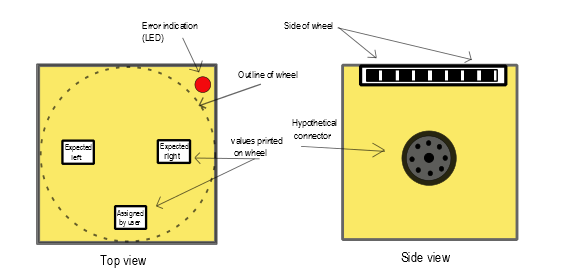
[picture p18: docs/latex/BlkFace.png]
 
    \caption{Wheel Encoder Diagrams for section 5.4}
   \end{figure}

\subsubsection{I/O}
User interface by rotating the wheel to select the desired value (token), this corresponds to a number processed via Grey Code or ADC which is then sent to the lexer for lookup.

When the interpreter has finished compiling the program image, if any errors exist, the control unit identifies which unique ID holds the token that caused it and sends out on the bus;
\begin{verbatim}
[unique ID]
FLASH_LED
\end{verbatim}

\subsection{Micro-controller}

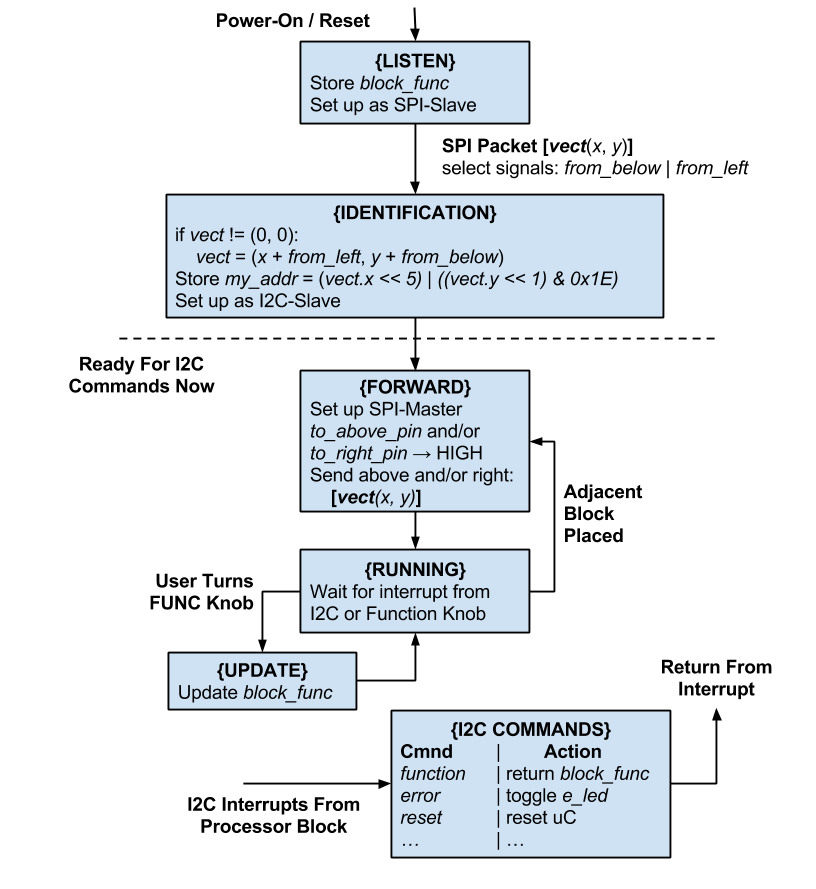
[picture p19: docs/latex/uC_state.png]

Once a micro-controller has determined its address, it will enable its I2C port and attach itself to the shared bus. This allows the main processor SBC to regularly poll the bus for the correct devices.
\begin{verbatim}
<Note: I2C is one possible protocol being considered>
\end{verbatim}
The diagram on the previous page assumes that the main processor \textbf{block} is oriented at the bottom-left of the code blocks and the \textbf{program} will be built up from this origin, i.e. each block receives its position vector either from below or from the left. 

This implementation allows us to utilize existing, supported, documented I2C drivers for both the micro controller in a hardware-supported and interrupt-driven slave-mode and the SBC in master-mode.

If the block is disconnected and reconnected it should return to the beginning state. This is now noted at the top by Reset.

In a 2x2 example, the block at (1, 1) would get vector signals both from the left and from below. It could simply use the first one it receives and ignore the other, or it could use the second to confirm the correct position as they should generate the same coordinate value.

Each micro-controller generates its own address from its position vector. A possible implementation is that the x-coordinate is the most significant 3 bits of the address, followed by the y-coordinate as the next 4 bits of the address, and the final bit (LSB) is the I2C R/W bit, per spec. For example, the block at position (2, 1) would have the address of: [010 0001 x]. This resolves to dimension limitations of 8 blocks long and 16 blocks tall, or a max 16 lines of code that are max 8 blocks wide. This is further limited by I2C reserved addresses. Other implementations could improve upon this.

Once the block knows its function and its position, it is immediately available for I2C addressing from the SBC. Since the I2C communication will be interrupt-driven, the block can resume setting up after it services a message if it was received before it completed initialization. Possible commands could include:
\begin{verbatim}
* Return this block's function code
* Toggle this block's error LED
* Reset this block
* Etc.
\end{verbatim}
   
\subsection{Physical Connections}
Blocks will be interlocked using small outward pegs with corresponding recessed cavities. These protrusions on the blocks will contain the electrical connectors, and serve as a physical guide to ensure the pin connections line up during product use. A combination of varying the connector types, the protrusion shapes, and magnets can be used to hold blocks firmly together and  will ensure that only the correct face of one block can be mated to a second block.\\
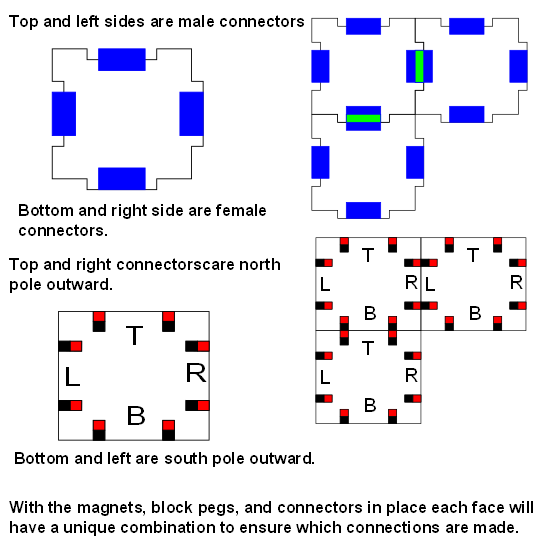
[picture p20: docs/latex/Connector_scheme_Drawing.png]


  \section{Risk Management}
  Identifying potential risks associated with our current proposed solutions, can help by allowing a certain amount of mitigating action to be built in to the design process. This section follows the same layout as section 5, with 6.1 being directly related to 5.1 and so on.
  \subsection{User Interface}
  In any scheme designed to be easy to use there is the danger of being easy only for the designers. What we think of as intuitive is not certain to be easy to understand for students or teachers. 
  The more complex our manuals or instructions are, the clearer it can be how to use the blocks.
  
   There is however,  a limit to how much time a  user is willing invest in reading instruction before they can use the blocks effectively . If there is not enough or too much user targeted documentation, learning to use the blocks could be frustrating.
  \begin{enumerate}
   \item \textit{Mitigation:} Both risks can be reduced by testing, and seeking feedback, which invites a trade off of time and resources spent on testing versus spent on designs and implementations. 
  \end{enumerate} 

  \subsection{Software}
    Possible pitfalls for the current proposed solution are discussed in this section, and likely mitigation techniques are discussed for each pitfall.
    \begin{enumerate}

      \item Varying path lengths on each bus may result in bit drift and/or clock skew.
      \begin{enumerate}
        \item \textit{Mitigation:} Throughput on buses is not likely to be a significant factor in system performance (whereas interpreter performance is), so slower baud rates are a cheap solution.
      \end{enumerate}

%   WE DO NOT CURRENTLY ADDRESS 2 DIMENSIONAL SCANNING IN OUR PAPER, WE ONLY INTRODUCE RASTER SCANNING TECHNIQUE
%      \item Propagation of position vectoring commands along two dimensions could result in long wait times for global bus arbitration, resulting in timeouts.
%      \begin{enumerate}
%        \item
%      \end{enumerate}

      \item A user can write an infinite loop
      \begin{enumerate}
        \item \textit{Mitigation:}User programs will run in their own process which will be killed whenever blocks are rearranged (then the new program will start in a new process).
      \end{enumerate}

      \item Manufacturing uncertainties: Connectors do not align; enclosures are not square. Magnetic interference.
      \begin{enumerate}
        \item \textit{Mitigation:} Expose connectors for proof-of-concept revisions to demonstrate functionality.
      \end{enumerate}

      \item Communication algorithm was inherently flawed.
      \begin{enumerate}
        \item \textit{Mitigation:} We plan to release our first revision at the halfway mark before "product launch". Reimplementing the Location-Vectoring algorithm using a tray as a fixed-grid reader of Unique IDs would be trivial from a design perspective.
      \end{enumerate}

    \end{enumerate}
   \stepcounter{subsection}
   \subsection{Visual Feedback}
   In general there is a proportional relationship between the level of detail relayed to the user and complexity. The current proposal involves several moving pieces which each represent a risk of mechanical failure. Additionally there is a hardware to software interface at each point that posses additional risks. By contrast limiting the feedback system runs the risk of making the program controls too difficult.  
  \begin{enumerate}
    \item \textit{Mitigation:} Use of an ID \textit{ stub} in software will help simplify testing and allow for bugs to be narrowed to either HW or SW.
      \item \textit{Mitigation:} We will remain willing to limit the number of selectable states to reduce complexity as needed.
        \item \textit{Mitigation:} First run/ prototypes may also have to use a simple dial without the encoded wheel as proof of concept.
  \end{enumerate} 
  \vfill
   \subsection{Micro-controller}
   
   Blocks may get stuck in different states. 
   \begin{enumerate}
     \item \textit{Mitigation:} Reset triggers and watchdog timers can help alleviate some issues.
   \end{enumerate} 
   Additionally the algorithm on its own does not determine end of line or completed search, the main processor block must poll regularly for block identities. This can lead to:
      \begin{verbatim}
       * Stale function values
       * Wasted processing on both ends of the bus
      \end{verbatim}
     \begin{enumerate}
      \item[2.] \textit{Mitigation:} Possible optimizations can be made by limiting poll to likely addresses (blocks starting at 0, etc)
     \end{enumerate}
  
    \subsection{Physical Connections}
    The interlocking of the blocks adds the possibility that blocks can only be inserted easily on faces that have no adjacent blocks already connected. This would mean that if the interlocking sections of blocks are tight tolerance, rows will have to be constructed prior to being connected to other rows.
    
    Additionally adding a magnetic connection to hold the blocks together makes assembly of the block more difficult. Having unique locations for each connector/interlock pair means that an incorrectly oriented magnetic internal to the device could prevent a good connection.
    \begin{enumerate}
     \item \textit{Mitigation:} Determining the tolerance between blocks will aid in the selection of an appropriate connector.
      \item \textit{Mitigation:} Use male/ female type connectors only for first pass, avoiding magnets. 
    \end{enumerate} 

\subsection{General Cautions and Considerations}
\subsubsection{Fetching Block Tokens}
When the token is selected on a block by the user(\textit{see 5.3 and 5.4}) it must be fetched by the lexer. Several solutions exist and are proposed below. The solution chosen is dependent on metrics obtained during prototyping. The following factors will be weighed when determining which block-fetch technique will be used:
\begin{enumerate}
    \item \textit{Required communication transactions.} Some techniques include the block token in messages already required by the location-finding algorithm, while some introduce additional messages.
    \item \textit{Token-Fetch-to-Parse Latency.} The amount of time it takes from reading the user-selected token to passing the token to the lexer is variable from technique-to-technique. This latency is a component of the overall system opacity time, eg. the time when user-changes to selected block tokens don't effect program execution. Opacity time should be reduced where possible.
    \item \textit{Determinism.} Some techniques use parallel execution which could lead to certain token-fetches to arrive at indeterminate times. This can make debugging during testing phases more difficult.
    \item \textit{Complexity.} The complexity of the algorithm chosen and the complexity of implementing the algorithm are to be considered. Algorithmic complexity makes later expansion more difficult, while implementation complexity increases development time.
\end{enumerate}

The following block-token-fetching techniques will be considered, and their consideration of the above factors are included:
\begin{enumerate}
    \item \textit{Reading and sending block-tokens during location-scanning time.} Least amount of communication, most token-fetch-to-parse latency, deterministic, least complexity.
    \item \textit{Fetch during lex time.} Adds a message transaction for each block, minimum token-fetch-to-parse latency, deterministic, slightly more complex.
    \item \textit{Regular polling in asynchronus thread from lexing.} Increases the amount of messages by indeterminate amount, indeterminate token-fetch-to-parse latency, non-deterministic, complex implementation but least complex algorithmically.
\end{enumerate}
\subsubsection{Open Sourcing }
To stay on track with developing an open source platform, we want to reduce actions that might lead to complications.
  
  \begin{enumerate}
 \item \textit{Mitigation:} avoid dependence on non-generic components
\item \textit{Mitigation:} avoid, where possible, proprietary technologies.
\item \textit{Mitigation:}always check licensing
  \end{enumerate}
 
\end{document}{

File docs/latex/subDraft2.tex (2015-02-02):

\input{start.tex}
\linespread{1.1}
\begin{document} 
\definecolor{PSU}{RGB}{75,125,50} 
\begin{titlepage} 
\begin{center} 
 
% leave tilde after graphic, it designates par format, needed for formating 
~\\[.5cm] 
 
\textsc{\LARGE \color{PSU} Maseeh College of Engineering}\\[1.5cm] 
 
\textsc{\Large Prject Proposal}\\[0.5cm]
\textsc{\Large Submission Draft \#2}\\[0.5cm]
\vspace{1cm} 
% Title 
 
{ \huge \bfseries\color{PSU} A Block of Code\\[0.4cm] } 
  \large Senior Capstone Project
 
% \hrule  
\vspace{2.5cm} 
% Team Members 
 \begin{multicols}{2}
    
\begin{flushleft}
\noindent 
 \large 
\emph{\color{PSU}Team Members:}\\ 
Nathan \textsc{Bryant}\\ 
Daniel \textsc{Frister}\\
Tyler  \textsc{Hart}\\
Jacob   \textsc{Micikiewicz}\\
Greg    \textsc{Stromire}\\
\end{flushleft} 

 \begin{flushleft}
  \large 
 \emph{\color{PSU}Erebus Labs:} \\ 
 Dr. Mike  \textsc{Borowczak}\\ 
 \emph{\color{PSU}University of Wyoming}\\
 DR. Andrea \textsc{Burrows}\\ 
 \emph{\color{PSU}PSU Advisor:}\\ 
 Roy \textsc{Kravitz} 
 \end{flushleft}

 \end{multicols}` 
\vfill 
 
% Bottom of the page 
{\large \today} 
 
\end{center} 
\end{titlepage} 
 \tableofcontents

\section{Needs Statement}
The skills involved in programming encompass a large cross disciplinary curriculum. Learning to write code is easy, however imparting the knowledge and intuition necessary to be  skilled programmer is no mean feat. Under the current educational system economics weigh heavily on a schools ability to provide their student opportunities that are not officially budgeted. Worse still the economic divide is growing to encompass access to technology. There needs to be a low cost method of teaching advanced coding skills in school were access to a computer may be limited at best.  
\section{Objective}
Creating a tactile learning tool to instruct primary school students in the basics of computer programming is the primary goal of this venture. This tool will allow students to arrange blocks to perform basic operations and assignments. Verification of valid code structures will provide feedback for learning, and control of simple outputs connected to the system can give students a goal for their project.

\section{Background}

Currently there are is a limited selection of methods to teach younger groups of students about computer programming, and those that do exist rely on the use of software. This project is aimed to produce a learning aid that will function in a setting where there are not enough computers available for student to use. Basic functionality of the system should not require the presence of a computer.
The use of a visual-tactile system to teach new skills to children has a long and well established history. In terms of this project the system can be thought of as a, \textit{Spielgaben}, a subject specific learning module. The purpose of which is to allow students of any age to be introduced to the subject using a familiar process that promotes creativity. Allowing the module to be untethered, separate from a computer, will also allow the teaching of programming without the other distractions available on a PC, and give students that have trouble with abstraction a set of objects to focus on.

\section{Marketing Requirements}
The final package will be a set of between twenty to thirty blocks typically about two inches along the longest edge. The set will consist of a central processor block, a small number of dedicated output blocks, and the function and operation blocks used to implement the code. Power will be distributed through the network of connected blocks starting at a battery located near/with the processor, and all of the power and data connections for the system will be through contact pads on the edges of each block. These contact pads will be held in place during use by a coupling mechanism which holds adjacent blocks together. Error notifications will be available to indicate faults in the code at the individual block.

\section{Risk Management}
\subsection{Defining Risks}
 An assessment of project specific risks addressed by potential detriments, breaks risks down by project phase, and then by weight under each phase.

 \hspace{.35cm} \textbf{Risk types:}
 \begin{enumerate}
 \item \textbf{Scope}; risks of scope are those that caused the project to be delayed, too complex, or trivial. Frequently these are cause by poorly defined project specifications, attempting to do much, or becoming unnecessarily focused on specific details.
 \item \textbf{Conceptual}; risks belonging here are the products of some failure in understanding a problem or it's intended solution. One example could be  attempting to predict position by triangulation but forgetting to consider velocity. 
 \item \textbf{Physical}; risks of this type include problems that manifest physically, most commonly refereed to as \textit{bugs}(software bugs are included here. )
 \item \textbf{Incalculable}; risks of this nature include random and unforeseeable events. Shipment delays, inclement weather, and distributor component substitution are all examples of such risks.
 \end{enumerate}
 \subsection{Mitigating Risk}
\end{document}

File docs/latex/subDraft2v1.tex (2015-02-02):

\input{start.tex}
\linespread{1.1}
\begin{document} 
\definecolor{PSU}{RGB}{75,125,50} 
\begin{titlepage} 
\begin{center} 
 
% leave tilde after graphic, it designates par format, needed for formating 
~\\[.5cm] 
 
\textsc{\LARGE \color{PSU} Maseeh College of Engineering}\\[1.5cm] 
 
\textsc{\Large Prject Proposal}\\[0.5cm]
\textsc{\Large Submission Draft \#2.1}\\[0.5cm]
\vspace{1cm} 
% Title 
 
{ \huge \bfseries\color{PSU} A Block of Code\\[0.4cm] } 
  \large Senior Capstone Project
 
% \hrule  
\vspace{2.5cm} 
% Team Members 
 \begin{multicols}{2}
    
\begin{flushleft}
\noindent 
 \large 
\emph{\color{PSU}Team Members:}\\ 
Nathan \textsc{Bryant}\\ 
Daniel \textsc{Frister}\\
Tyler  \textsc{Hart}\\
Jacob   \textsc{Micikiewicz}\\
Greg    \textsc{Stromire}\\
\end{flushleft} 

 \begin{flushleft}
  \large 
 \emph{\color{PSU}Erebus Labs:} \\ 
 Dr. Mike  \textsc{Borowczak}\\ 
 \emph{\color{PSU}University of Wyoming}\\
 DR. Andrea \textsc{Burrows}\\ 
 \emph{\color{PSU}PSU Advisor:}\\ 
 Roy \textsc{Kravitz} 
 \end{flushleft}

 \end{multicols}` 
\vfill 
 
% Bottom of the page 
{\large \today} 
 
\end{center} 
\end{titlepage} 
 \tableofcontents

\section{Needs Statement}
Todays world is one of interconnected technologies, at the heart of which are devices like computers and micro-controllers. As the technological complexity of our world increases we will find our society more and more reliant on the men and women who know how to operate and control these devices.\\

However as of today no universally accessible curriculum includes a focus on the knowledge and skills needed to program these machines. We have need of any system that can help children learn and understand these concepts. Additionally  the long term effectiveness of any system will depend on both it's ease of use and it's accessibility across a large range communities, especially those under financial duress.
\newpage

\section{Objective}
Creating low cost tactile learning tool to instruct primary school students in the basics of computer programming is the primary goal of this venture. This tool will allow students to arrange blocks to perform basic operations and assignments. Verification of valid code structures will provide feedback for learning, and control of simple outputs connected to the system can give students a goal for their project.

\section{Background}

Currently there are limited methods of teaching  younger groups of students about computer programming, and those that do exist often rely heavily on access to computers. This project is aimed to produce a learning aid that will function in a classroom setting, doing away with the need have computers present for learning. 
The use of a visual-tactile system to teach new skills to children has a long and well established history dating at least as far back as Froebel.\\

 In terms of this project the system can be thought of as a, Froebel \textit{Spielgaben}, a subject specific learning module. The purpose of which is to allow students of any age to be introduced to the subject using a familiar process that promotes creativity. Allowing the module to be untethered, separate from a computer, will also allow the teaching of programming without the other distractions available on a PC, and give students that have trouble with abstraction a set of objects to focus on.

\section{Marketing Requirements}

The final package will be a set of between twenty to thirty blocks typically about two inches along the longest edge. The set will function as it's own interface device, where the topographical arrangement of elements (blocks) will determine the \textit{program}. The individual blocks must be identifiable as belonging to a specific programming construct-group. At a minimum these groups must include; numbers, variables, operators, and controls.\\

Additionally it should be included, if possible, on each block, what the current assigned value or function the block has been assigned to. Blocks should be easy to assemble,  allowing users to experiment with layouts, but provide area specific error feedback and thereby increasing understanding and limiting confusion. \\

Finally the set should open source and be sufficiently accessible, both by cost and teaching use, as to promote universal access and encourage development and expansion by others.

\section{Risk Management}
Identifying potential risks  at the beginning of a project can help by allowing a certain amount of mitigating action to be built in to the design process.
\subsection{Defining Risks} 
 
 \hspace{.35cm} \textbf{Risk types:}
 \begin{enumerate}
 \item \textbf{Scope}; risks of scope are those that caused the project to be delayed, too complex, or trivial. Frequently these are cause by poorly defined project specifications, attempting to do much, or becoming unnecessarily focused on specific details.
 \item \textbf{Conceptual}; risks belonging here are the products of some failure in understanding a problem or it's intended solution. One example could be  attempting to predict position by triangulation but forgetting to consider velocity. 
 \item \textbf{Physical}; risks of this type include problems that manifest physically, most commonly refereed to as \textit{bugs}(software bugs are included here. )
 \item \textbf{Incalculable}; risks of this nature include random and unforeseeable events. Shipment delays, inclement weather, and distributor component substitution are all examples of such risks.
 \end{enumerate}
 \subsection{Mitigating Risk}
  \hspace{.35cm} \textbf{Action by type:}
  \begin{enumerate}
  \item \textbf{Scope}; 
  \begin{enumerate}
  \item Over reaching and scope creep; 
  
  Controlling the scope size can usually implemented by instituting system of interdepartmental checks, and by setting project goals by stages. The later infers making the scope such that it satisfies only the minimum project specifications, while the former in this case infer double checks are done between team and advisor, or other available expert resources.
  
  In both cases the scope can be added to, but by building a semi-bureaucratic requirement into the process, the chances of adding unrealizable goals to the project have been reduced.
  \item Built in obsolescence;
  
  In contrast to point (a) is the risk defining the project so precisely as to reduce the final product's usability. Incorporating a mandatory review of tasks and goals at milestones can help. As in the above process, by conceiving each stage of the  project between milestones as a singular smaller project, the chances of including new and relevant additions to scope.
   \end{enumerate}
  \item \textbf{Conceptual};
  \begin{enumerate}
  \item Improperly defined problems; 
  
  The methods of limiting these types of risk are very closely related to those of controlling scope. By ensuring clarity of scope it then becomes easier to dissect the problem as it pertains to project.
  
  After dissection it is up to each team member to voice any concerns or confusions. To which as a group, providing an open, non-judgmental forum is imperative.
  \item Fallacious solution sets; 
  
  This type of risk usually, but not always, stems from having improperly defined problems, in which case have been addressed already. For the cases not covered, a solid system of review and collaboration combined with weekly meetings will reduce the likelihood of improperly framed proposed solutions being implemented.
  
  \end{enumerate} 
  \item \textbf{Physical};
  \begin{enumerate}
  \item Mechanical; 
  
  Mechanical failure can be difficult to foresee, however by always checking proposed designs for possible simplifications can help mitigate potential pitfalls. General mechanical design considerations should always consider; least number of [connections, moving parts, seams, joints]
  \item Electrical:
  
  As with mechanical, where checks should be ...
  \item Code based;
  
  Running out of time before class  feel free to comment on what should be here
  \end{enumerate}
  \item \textbf{Incalculable}; 
  \begin{enumerate}
  \item Components;
  
  While the entire section precludes prediction, there are certain actions that can limit damage done in event of component based problems. Problems may include, random device failure, shipping delays, distributor substitutions, and more.
  \begin{enumerate}
  \item avoid dependence on non generic components
  \item avoid, where possible, proprietary technologies.
  \item always check licensing 
  \item never order minimums
  \end{enumerate}
  \item Events;
  
  The most effective way to mitigate damages done by events like unforeseen weather or closure of services needed, is to have a flexible, organic schedule (see next).
  \item Scheduling;
  
  Designing a system of scheduling that allows for the most efficient use of available resources can greatly reduce strain on project time-lines. For this project we have implemented a generic \textit{by ticket} system, which allows team members to \textit{bid} on project tasks as dictated by their own constraints. This combined with ensuring that no individual task is longer than the time between meetings (1-week) will help ensure work flow. 
  \end{enumerate}
  \end{enumerate}
\end{document}

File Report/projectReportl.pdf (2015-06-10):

Maseeh College of Engineering

Project Summary & Report

# A Block of Code

### Senior Capstone Project

### Team Members: Nathan Bryant Daniel Frister Tyler Hart

Jacob Micikiewicz

Greg Stromire

### Erebus Labs: Dr. Mike Borowczak University of Wyoming DR. Andrea Burrows PSU Advisor:

Roy Kravitz

‘

### June 10, 2015

## Contents

1 Abstract | 2
2 Introduction | 2
3 Project Planning | 5
4 Methods and Tools | 11
5 Implementation | 12
6 Experiments and Testing | 24
7 Results | 24
8 Conclusions | 25
9 Appendix I: Project Checklist | 27
10 Appendix II: Token Patterns | 28
11 Appendix III Grammar Rules | 29
12 Appendix IV: Test Plans | 30

1

## 1 Abstract

We prototyped a low-cost, tactile teaching aide capable of helping a wide range of K-12 students explore the concepts of computer programming. Using a set of physically manipulatable blocks, students can perform basic programming operations and interact with the programs they create. Verification of valid code structures provide immediate feedback for rapid learning and control of simple and fun outputs connected to the system guide students toward a goal for their projects.

Each of our blocks is a 4-layer PCB, enclosed in an acrylic box, with an ATtiny461a microcontroller and 3 LEDs to indicate power, status, and errors. A 1MΩ potentiometer, with an attached acrylic wheel, is connected to the microcontroller's ADC to act as a selector for a block's particular function,

or token. Each block communicates over a limited SPI bus to two adjacent blocks to determine topology, and communicates back to a main processor over a TWI global bus. Our main processor board is a BeagleBone Black with a common Debian distribution running a Python-based lexer, Bisonbased parser, and C-based interpreter to run our simplified grammar. The results are supplied to an output pipeline to drive modular components such as an LCD screen or an RGB LED, as well as send feedback directly to the blocks via their onboard LEDs.

The end product is a set of blocks that introduce computer programming to students for whom traditional teaching methods are ineffective, or would otherwise have no exposure, and encourages all students to pursue education in STEM.

## 2 Introduction

### 2.1 Motivation

Introducing students to programming and computer science is vital in our increasingly connected world. Yet the tools and educational methods to familiarize young minds to STEM subjects have not kept pace with the technologies themselves. The typical CS learning experience in front of a

2

computer screen only engages a select few students with a compatible learning style, and often schools struggle to afford the necessary resources and computer labs. Our goal was to create an interactive learning tool that can engage a wider range of students for presenting computer science concepts.

### 2.2 Proposal

The package will be a set of twenty to thirty cubes at around two inches across on a side. The set will function as its own interface device, where the topological arrangement of the elements (blocks) will determine the program. The individual blocks must be identifiable as belonging to a specific programming-construct group, such as a simplified programming grammar. At a minimum these groups must include; numbers, variables, operators, and controls.

Additionally, where necessary, a block should be capable of indicating what value or function it has been assigned. Blocks should be easy to connect, allowing users to experiment with layouts, and also provide area-specific error feedback and thereby increasing understanding and limiting confusion.

Finally, the set should be open-source and sufficiently accessible, both by cost and teaching use, as to promote universal access and encourage development and expansion by the general public.

3

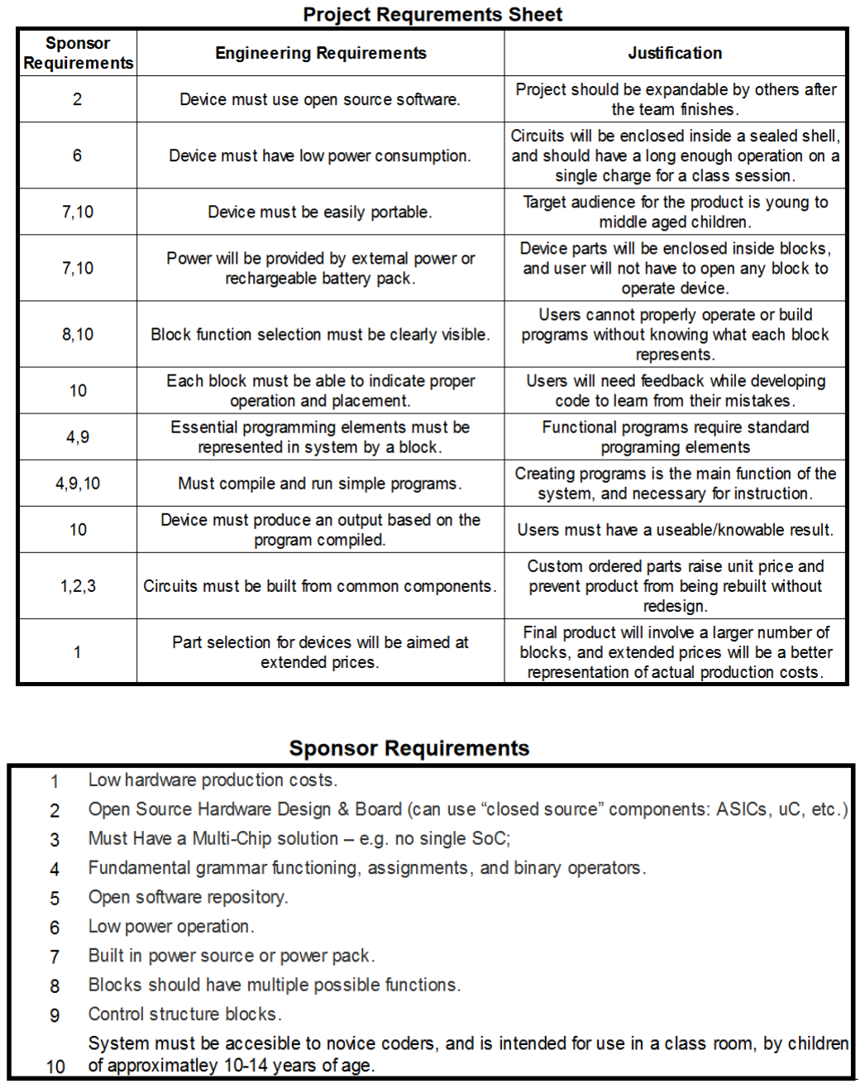
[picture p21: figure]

4

## 3 Project Planning

We identified three main elements for our system design: Physical Construction, Block Communication, and Program Interpretation. This enabled us to research and develop each subsystem in parallel with regular inter-group updates to stay unified on task. We also set several early milestones to ensure successful integration and to allow for multiple, iterative design revisions.

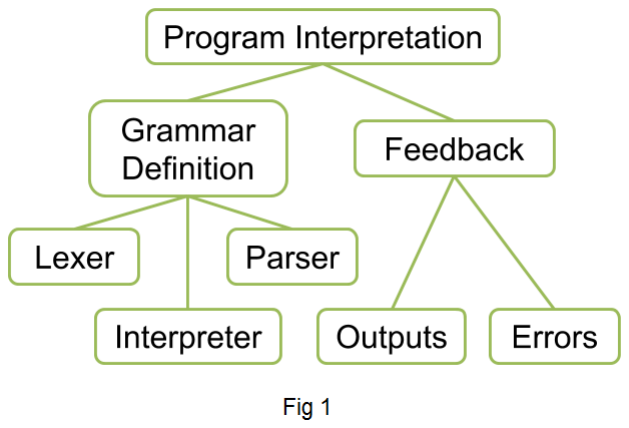
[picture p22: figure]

5

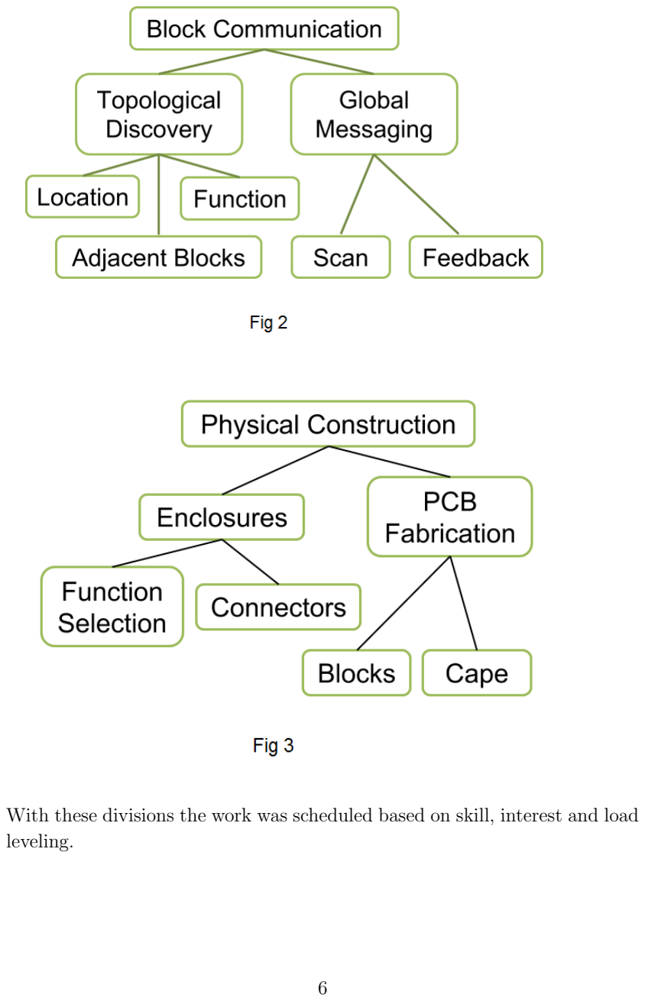
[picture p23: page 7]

With these divisions the work was scheduled based on skill, interest and load leveling.

6

ID | Task Name | Duration Start | | Finish | Predecessors
1 | A Block of Code | 211 daysFri 11/14/14 | | Fri 6/12/15 | | 11/14 | Nathan,Daniel,Greg,Jacob,Tyler | Nathan,Daniel,Greg,Jacob,Tyler | 2/3 2/9
2 | Capstones Assigned | 0 days | Fri 11/14/14 | Fri 11/14/14
3 | Complete Rev 1 | 125 daysWed 11/26/14 | | Mon 3/30/15
4 | Generate Concepts | 54 days | Wed 11/26/14 | Sun 1/18/15 | 2
5 | Meet with Advisor | 1 day | Wed 11/26/14 | Wed 11/26/14 | 2
6 | Document Ideas for 5 Design Areas | 18 days | Tue 12/23/14 | Fri 1/9/15 | 5
7 | Meet with Sponsors | 1 day | Fri 1/9/15 | Fri 1/9/15
8 | Decide on Design Direction | 9 days | Sat 1/10/15 | Sun 1/18/15 | 7
9 | Propose Project | 21 days | Mon 1/19/15 | Mon 2/9/15 | 8
10 | Create Proposal Draft | 5 days | Mon 1/19/15 | Fri 1/23/15
11 | Create Project Schedule Draft5 days | | Mon 1/19/15 | Fri 1/23/15
12 | Review Proposal with team | 4 days | Sat 1/24/15 | Tue 1/27/15 | 10
13 | Review Project Schedule with team | 4 days | Sat 1/24/15 | Tue 1/27/15 | 11
14 | Revise Proposal | 3 days | Wed 1/28/15 | Fri 1/30/15 | 12
15 | Revise Project Schedule | 3 days | Wed 1/28/15 | Fri 1/30/15 | 13
16 | Present Drafts to Advisor for Feedback | 0 days | Fri 1/30/15 | Fri 1/30/15 | 14,15
17 | Revise Drafts for Submission4 days | | Sat 1/31/15 | Tue 2/3/15 | 16
18 | Submit Docs to Sponsors | 0 days | Tue 2/3/15 | Tue 2/3/15 | 17
19 | Feedback from Sponsors | 0 days | Mon 2/9/15 | Mon 2/9/15 | 18
20 | Prototype 5 Design Areas | 28 days | Sat 1/31/15 | Fri 2/27/15
21 | Prototype Power | 28 days | Sat 1/31/15 | Fri 2/27/15
22 | Research Methods | 8 days | Sat 1/31/15 | Sat 2/7/15 | 16
23 | Research Best Practices | 8 days | Sun 2/8/15 | Sun 2/15/15 | 22
24 | Order Parts | 0 days | Sat 2/7/15 | Sat 2/7/15 | 22
25 | Receive Parts | 0 days | Sun 2/15/15 | Sun 2/15/15 | 23,24
26 | Assemble Proof of Concept6 days | | Mon 2/16/15 | Sat 2/21/15 | 25
27 | Test Proof of Concept | 6 days | Sun 2/22/15 | Fri 2/27/15 | 26
28 | Prototype Communication | 28 days | Sat 1/31/15 | Fri 2/27/15
29 | Research Methods | 8 days | Sat 1/31/15 | Sat 2/7/15 | 16

Nathan,Daniel,Greg,Jacob,Tyler

Nathan,Daniel,Greg,Jacob,Tyler

Daniel
Greg
Daniel,Greg,Jacob,Nathan,Tyle Daniel,Greg,Jacob,Nathan,Tyle

Daniel,Nathan
Greg
1/30

2/7
2/15
T | W | T | F | S | S | M | T | W | T | F | S | S | M | T | W
Nov 16, '14 | Dec 7, '14 | Dec 28, '14 | Jan 18, '15 | Feb 8, '15 | Mar 1, '15

Page 1

ID | Task Name | Duration Start | | Finish | Predecessors
30 | Research Best Practices | 8 days | Sun 2/8/15 | Sun 2/15/15 | 29
31 | Order Parts | 0 days | Sat 2/7/15 | Sat 2/7/15 | 29
32 | Receive Parts | 0 days | Sun 2/15/15 | Sun 2/15/15 | 30,31
33 | Assemble Proof of Concept6 days | | Mon 2/16/15 | Sat 2/21/15 | 32
34 | Test Proof of Concept | 6 days | Sun 2/22/15 | Fri 2/27/15 | 33
35 | Prototype Processing | 28 days | Sat 1/31/15 | Fri 2/27/15
36 | Research Methods | 8 days | Sat 1/31/15 | Sat 2/7/15 | 16
37 | Research Best Practices | 8 days | Sun 2/8/15 | Sun 2/15/15 | 36
38 | Order Parts | 0 days | Sat 2/7/15 | Sat 2/7/15 | 36
39 | Receive Parts | 0 days | Sun 2/15/15 | Sun 2/15/15 | 37,38
40 | Assemble Proof of Concept 6 days | | Mon 2/16/15 | Sat 2/21/15 | 39
41 | Test Proof of Concept | 6 days | Sun 2/22/15 | Fri 2/27/15 | 40
42 | Prototype Form Factor | 28 days | Sat 1/31/15 | Fri 2/27/15
43 | Research Methods | 8 days | Sat 1/31/15 | Sat 2/7/15 | 16
44 | Research Best Practices | 8 days | Sun 2/8/15 | Sun 2/15/15 | 43
45 | Order Parts | 0 days | Sat 2/7/15 | Sat 2/7/15 | 43
46 | Receive Parts | 0 days | Sun 2/15/15 | Sun 2/15/15 | 44,45
47 | Assemble Proof of Concept 6 days | | Mon 2/16/15 | Sat 2/21/15 | 46
48 | Test Proof of Concept | 6 days | Sun 2/22/15 | Fri 2/27/15 | 47
49 | Prototype UI/IO | 28 days | Sat 1/31/15 | Fri 2/27/15
50 | Research Methods | 8 days | Sat 1/31/15 | Sat 2/7/15 | 16
51 | Research Best Practices | 8 days | Sun 2/8/15 | Sun 2/15/15 | 50
52 | Order Parts | 0 days | Sat 2/7/15 | Sat 2/7/15 | 50
53 | Receive Parts | 0 days | Sun 2/15/15 | Sun 2/15/15 | 51,52
54 | Assemble Proof of Concept 6 days | | Mon 2/16/15 | Sat 2/21/15 | 53
55 | Test Proof of Concept | 6 days | Sun 2/22/15 | Fri 2/27/15 | 54
56 | Integrate Modular Prototypes for Full System
57 | Test Full System | 5 days | Sun 3/8/15 | Thu 3/12/15 | 56
58 | Record Video of Prototyped System Demonstration | 1 day | Fri 3/13/15 | Fri 3/13/15 | 57
8 days | Sat 2/28/15 | Sat 3/7/15 | 20,28,35,42,49

2/7
2/15

2/7
2/15

2/7
2/15

2/7
2/15

Daniel,Greg,Jacob,N

Daniel,Gr
Greg
M | W | F | S | T | T | S | M | W | F | S | T | T | S | M | W | F | S
Feb 8, '15 | Feb 15, '15 | Feb 22, '15 | Mar 1, '15 | Mar 8, '15 | Mar 15

Page 2

ID | Task Name | Duration Start | | Finish | Predecessors
59 | Present Demonstration to Advisor and Sponsors for | 0 days | Fri 3/13/15 | Fri 3/13/15 | 58
60 | [Break for Finals] | 9 days | Sat 3/14/15 | Sun 3/22/15 | 59
61 | Revise Designs based on Feedback 4 days | | Mon 3/23/15 | Thu 3/26/15 | 60
62 | Test Revisions | 4 days | Fri 3/27/15 | Mon 3/30/15 | 61
63 | Rev 1 Complete | 0 days | Mon 3/30/15 | Mon 3/30/15 | 62
64 | Complete Rev 2 | 69 days | Tue 3/31/15 | Sun 6/7/15 | 63
65 | Brainstorm Additional Features5 days | | Tue 3/31/15 | Sat 4/4/15 | 63
66 | Prototype Additional Features | 6 days | Sun 4/5/15 | Fri 4/10/15 | 65
67 | Complete Board Designs | 37 days | Sat 4/11/15 | Sun 5/17/15
68 | Complete ERC Error-Free Schematics | 16 days | Sat 4/11/15 | Sun 4/26/15
69 | Research and Select Parts 4 days | | Sat 4/11/15 | Tue 4/14/15 | 66
70 | Design Schematics | 4 days | Wed 4/15/15 | Sat 4/18/15 | 69
71 | Review Schematics Internal to Group | 4 days | Sun 4/19/15 | Wed 4/22/15 | 70
72 | Send Schematics to Third Party for Review | 4 days | Sun 4/19/15 | Wed 4/22/15 | 70
73 | Revise Schematic | 4 days | Thu 4/23/15 | Sun 4/26/15 | 71,72
74 | Complete DRC Error-Free Layout 12 days | | Mon 4/27/15 | Fri 5/8/15
75 | Layout Boards | 4 days | Mon 4/27/15 | Thu 4/30/15 | 68
76 | Review Layouts Internally to Group | 4 days | Fri 5/1/15 | Mon 5/4/15 | 75
77 | Send Layouts to Third Party for Review | 4 days | Fri 5/1/15 | Mon 5/4/15 | 75
78 | Revise Layouts | 4 days | Tue 5/5/15 | Fri 5/8/15 | 76,77
79 | Print Small Run of Boards in PSU LID | 2 days | Sat 5/9/15 | Sun 5/10/15 | 78
80 | Assemble Small-Run Boards | 2 days | Mon 5/11/15 | Tue 5/12/15 | 79
81 | Test Small-Run Boards | 2 days | Wed 5/13/15 | Thu 5/14/15 | 80
82 | Print and Assemble Remaining Boards | 3 days | Fri 5/15/15 | Sun 5/17/15 | 81
83 | Complete Code | 37 days | Sat 4/11/15 | Sun 5/17/15 | 66
84 | Code Block Identification | 6 days | Sat 4/11/15 | Thu 4/16/15

Page 3

3/13

Daniel,Greg,Jacob,Nathan,Tyler Daniel,Greg,Jacob,Nathan,Tyler Daniel,Greg,Jacob,Nathan,Tyler
3/30

Daniel,Greg,Jacob,Nathan,T Daniel,Greg,Jac

F | S | T | T | S | M | W | F | S | T | T | S | M | W | F | S | T | T
Mar 15, '15 | Mar 22, '15 | Mar 29, '15 | Apr 5, '15 | Apr 12, '15

ID | Task Name | Duration Start | | Finish | Predecessors
85 | Code Program Execution | 6 days | Fri 4/17/15 | Wed 4/22/15 | 84
86 | Code Error Detection | 6 days | Thu 4/23/15 | Tue 4/28/15 | 85
87 | Code Block Communication | 6 days | Wed 4/29/15 | Mon 5/4/15 | 86
88 | Test Full Code System | 7 days | Tue 5/5/15 | Mon 5/11/15 | 87
89 | Revise System Components | 6 days | Tue 5/12/15 | Sun 5/17/15 | 88
90 | Complete Enclosures | 9 days | Sat 5/9/15 | Sun 5/17/15
91 | Design Enclosures | 2 days | Sat 5/9/15 | Sun 5/10/15 | 66,74
92 | Print and Assemble Small-Run of Enclosures | 2 days | Mon 5/11/15 | Tue 5/12/15 | 91
93 | Revise Enclosure Design | 2 days | Wed 5/13/15 | Thu 5/14/15 | 92
94 | Print and Assemble Remaining Enclosures | 3 days | Fri 5/15/15 | Sun 5/17/15 | 93
95 | Consider Specialized Output Block Designs | 4 days | Wed 5/13/15 | Sat 5/16/15 | 92
96 | Integrate Modular Prototypes for Full System
97 | Test Full System | 5 days | Mon 5/25/15 | Fri 5/29/15 | 96
98 | Record Video of Prototyped System Demonstration | 1 day | Sat 5/30/15 | Sat 5/30/15 | 97
99 | Present Demonstration to Advisor and Sponsors for | 0 days | Sat 5/30/15 | Sat 5/30/15 | 98
100 | Revise Designs based on Tests and Feedback | 4 days | Sun 5/31/15 | Wed 6/3/15 | 98
101 | Test Revisions | 4 days | Thu 6/4/15 | Sun 6/7/15 | 100
102 | Rev 2 Complete | 0 days | Sun 6/7/15 | Sun 6/7/15 | 101
103 | Create Presentation | 14 days | Sat 5/30/15 | Fri 6/12/15
104 | Design Poster | 4 days | Sat 5/30/15 | Tue 6/2/15 | 97
105 | Send Poster off for Print | 1 day | Wed 6/3/15 | Wed 6/3/15 | 104
106 | Create Presentation Slides | 4 days | Sat 5/30/15 | Tue 6/2/15 | 97
107 | Write "Curriculum" | 4 days | Sun 5/31/15 | Wed 6/3/15 | 98
108 | Present | 5 days | Mon 6/8/15 | Fri 6/12/15 | 102
7 days | Mon 5/18/15 | Sun 5/24/15 | 67,83,90
T | S | M | W | F | S | T | T | S | M | W | F | S | T | T | S | M | W
Apr 19, '15 | Apr 26, '15 | May 3, '15 | May 10, '15 | May 17, '15

Page 4

## 4 Methods and Tools

We utilized several methods and tools during all phases of the project, and some were used only for specific phases. We each used a mix of Windows, Macintosh, and Linux workstations throughout the project. We also used the AVR Toolchains (CrossPack, avr-gcc, avrdude) and the AVRISP MKII programmer in development, manufacturing, and testing. The BeagleBone Black was another major part of our full project cycle.

For our development phase, we utilized EagleCAD to design and layout prototype PCBs. We then moved to DesignSpark to allow us to develop 4-layer boards and reduce the surface area for a cheaper design. We employed an Arduino Uno and associated IDE to develop the TWI bus, initially with the smaller but compatible ATtiny85. We also used an Intronix Logicport 34-Channel Logic Analyzer to inspect communications, albeit much later in the process than necessary. We used a 3D printer to prototype a potential selector wheel.

During our manufacturing phase, we used the Portland State University Laboratory for Interconnected Devices to assemble both revisions of our prototype. We used their Torch T200N Reflow Oven to solder our second revision surface mount components. And we used their Full Spectrum Professional Series CO2 20x12 Laser to cut acrylic enclosures and selector wheels. We also used a handful of other Portland State tools such as soldering irons and a dremel.

To test our final boards, we used a microscope to inspect solder connections and then a general purpose multimeter to verify conductivity and isolation. We then used an Arduino Uno's regulated 3.3V output to supply power

to a single and then a subset of blocks to confirm connectivity. We also wrote several scripts and test programs to explore the bounds and verify functionality of our set using an Arduino, a BeagleBone Black, and the blocks themselves.

11

## 5 Implementation

Our first development goal was a set of blocks that could identify their topology and return their token to a main processor. Though a 'smart-mat'design

was considered, we decided it would be too dimensionally restrictive. We chose AVR microcontrollers and DB-9 connectors for their ease and cost. We utilized a localized SPI communication to establish location and a global TWI bus to report the block's assigned value. We then selected a Linux-based

single board computer to harness existing language parsing and interpretation tools. The BeagleBone Black provided this at reduced power.

Our second set of development goals aimed to the increase block-set capability, provide portability, and expand the available output options:

- User-selectable subset of functions rather than a single, hard-coded

token

- BeagleBone Controller Cape for power distribution and control of a

global reset

- Additional modes of output connected to the Controller Cape to sup-

port student engagement in learning programming concepts

Each block is controlled by an ATtiny461 microcontroller, connected to two neighbors on a local bus based on SPI, and connected to all other blocks and the BeagleBone Black on a global bus using TWI. Both of these busses, as well as power and ground, are brought onto the block via a standard DB-9 connector. The token selector wheel is mounted on a 1MΩ potentiometer which feeds into the ADC on the microcontroller.

The local bus is started from the BeagleBone and initiates a handshake with the block connected below it. When the handshake completes, a vector is passed indicating the x- and y-coordinates of the sending block. The receiving block increments the vector based on whether the sending block is signaling from the above or the left line of the receiving block, and then stores and sends the incremented vector to the next block. The received vector is then translated into the TWI address on the global bus. The BeagleBone Black is able to query each block which responds with information on its adjacent blocks, its wheel category, and its current ADC value. The BeagleBone Black lexer uses this response data to construct a topology of the current block

12 arrangement. It then passes this information to a parser and interpreter to generate the appropriate output such as driving a LCD screen.

### 5.1 Block

The primary function of each block is to report back to the main processor board its own user-selected function as well as its adjacent blocks. This allows the main processor to collect the tokens and topological information necessary for constructing the user-generated program. A block progresses linearly through a series of states as outlined in the state diagram, Fig 4, on the following page.

### 5.1.1 Adjacent Blocks

First, the block will execute an initialization sequence that includes outputting to and reading from its adjacency lines. In typical usage, the blocks are built in a top-down orientation. A pair of slave-select pins, connected to the right and bottom connectors, are designated temporarily as inputs with their internal pull-up resistors enabled. Another pair of slave-select pins, connected to the left and top connectors, are designated temporarily as outputs and immediately pulled low.

For an example, consider the top block in Fig 5. If the block reads its adjacency pins and finds that its h out line (horizontal output) is HIGH, then it has no block connected to its right (again, in a top-down orientation). If it reads its v in is LOW, then a block is present below it. These values are stored and supplied to the main processor board in a global bus response (see TWI Commands).

13


14

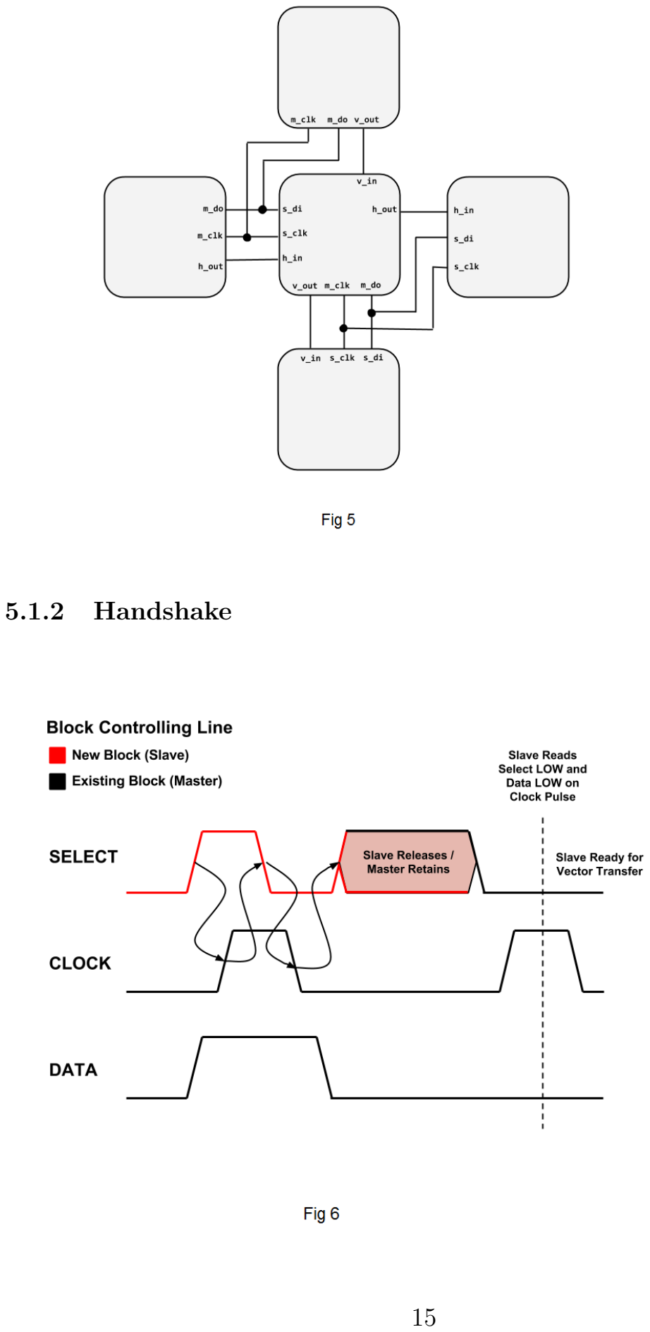
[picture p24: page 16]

### 5.1.2 Handshake

15

After the block is powered on and has executed its initialization sequence, including determining adjacent blocks, it prepares for a custom handshake to initiate a SPI transmission. Shown above is this handshake, where the just-powered-on block is considered the slave, and another block or the BeagleBone Black is considered the master.

1. First, the block will wait for the shared clock and data lines to go LOW. This will signal the block to start toggling its own select lines (v in and h in).
2. The master will then respond to the toggle that it sees (either horizontally or vertically) by bringing clock and data HIGH.
3. This triggers the select line LOW again and the clock and data lines again follow.
4. Next, the slave block brings its select line HIGH yet again but then releases control of it by switching the pin to an input and enable its internal pull-up resistor.
5. The master waits a short delay after seeing that rising edge then it changes its corresponding select line from an input to an output and pulls the line LOW.
6. A final clock pulse acts as a verification of the completed sequence before both blocks are prepared for a traditional SPI transmission.

It is possible that an adjacent block could see the same clock and data lines go LOW and in fact complete almost the entire sequence. But the corresponding select line would not be held low on that final clock pulse and thus that block would recognize that the sequence was not meant for it, and reset its state. The same is true for any other sequence of edges that doesn’t follow here – it would be considered bad input and cause a reset to initial handshake state.

### 5.1.3 SPI Transmission

Once a block has completed its handshake, it is prepared to receive data over a three-wire SPI protocol. This means there is no MISO signal involved. After the data is received, the block is able to continue to send the data to adjacent blocks as necessary. It will continue the direction it was originally

16 sent (e.g. if received from above, send below; if received from the left, send right).

It will also recognize when it is considered the 'end of the line', which is

considered the block with x-coordinate of 0 and no blocks connected below it. In this special case, it will then send to the right if there is a block present. Finally, a block will send in the vertical or horizontal directions on command from the global TWI bus (see TWI Commands).

Below is a screen capture from a logic analyzer showing 3 different SPI transmissions (in this example, blocks are implemented in a bottom-up orientation). The first transmission is to the current block which is acting as a slave and receiving data. The handshake begins at about the -200ms mark and completes roughly at -135ms mark. The actual transfer is shortly after that. The second handshake begins immediately and two lines do in fact follow the sequence, but only one has its line low when a second clock pulse 'confirms'the exchange. Finally, a TWI command is issued at about the -10ms

mark to complete that last SPI transmission.


The data transferred is an encoded vector indicated the sending-block's coordinates in the xy-plane of the user-program's topology: the first 3 bits are the

x-coordinate, and the next 4 bits are the y-coordinate. The receiving block will add 1 to the x- or y-coordinate it received, depending on from which direction it was sent. If an overflow will occur (e.g. if the block receives a x-coordinate of 7 from the left, it would increment to 8 which would overflow beyond the allotted 3 bits), then the process is aborted and an error indicating LED will blink to indicate the error condition. Otherwise, this encoded and incremented vector becomes the address of this block for a Two-Wire Interface global bus.

17


### 5.1.4 TWI Commands

The TWI interface allows targeted commands to trigger a handful of actions. The BeagleBone Black issues a TWI read request indicating an address (block) and a register (command). These numbers act as virtual registers on the block and are captured to issue tasks in a work queue. Below is a table of all the implemented actions.

Each command (except for number 10) returns a response byte that shows the current status of the addressed block. This byte is described below:

18

The most significant two bits are flags indicating if the current block has adjacent blocks connected in the vertical and horizontal directions respectively. The next two bits identify the category (or wheel) that is used for this block. And finally, the remaining four bits are the most significant 4 bits from the ADC read from the potentiometer. This indicates the user-selected token and, combined with the category identifier, indicates the exact token to be used in the parser.

### 5.2 Processor Board

### 5.2.1 Lexer


The lexer on
the BeagleBone Black utilizes both the local SPI-based bus as well as the global TWI-based bus. The BeagleBone Black initiates a standard handshake, as described above, and sends its own coordinate of (0, 0) to the connected block. This starts a chain of sending vectors to the 'end of the line.'The lexer then uses the TWI to query the first block with a ReadData

19 command, and recursively traverses the topology according to the vertical and horizontal adjacency flags in the response byte.

For each block response it receives with the vertical flag set, it queries the next vertical address until it receives a response without that flag set. It then sends a SendHorizontal command to the next block with a x-coordinate of zero and a horizontal adjacency flag set. The lexer queries that row until it gets to the end and then sends the next SendHorizontal command as necessary. This collects all the blocks (including their categories and ADC values). Each block's ADC value and category is used as keys to a master

token lookup table, shown in the table on the following page. The lexer then prints a string constructed from the mapped tokens to stdout which is captured by the parser / interpreter.

20


21

### 5.2.2 Parser

The parser is implemented using GNU Flex and Bison. Bison is used to allow rapid changes to grammar rules once physical manipulators are tested to give feedback to drive iterative redesign of the language. Flex is used to tokenize literals from the input stream and ease case-insensitivity of the language's

keywords.

Tokens

Tokens patterns are expressed as regular expressions and are available in the appendix. Non-tokenized patterns that are in the source code are omitted for brevity. These patterns are used for ignoring certain patterns or implementing parser control patterns.

Grammar

The Bison based parser builds an abstract syntax tree whose structure can be modeled with a 1-to-1 mapping with the grammar rules. The grammar rules are provided in the appendix.

### 5.2.3 Interpreter

The interpreter receives the root node from the parser, which is a STATE-MENT LIST and descends it directly. The interpreter follows each node in the list and evaluates each node, discarding any return values and performing each node's side effects.

Each operand in the statement in the statement list is recursively evaluated as expressions, until a terminator is reached. Terminators are type NUM and VAR.

### 5.2.4 Output Pipeline

Outputs from the interpreter are put on stdout in the form:

#OUTPUT(CHANNEL, VAL)

22

The orchestration script pipes the output of the interpreter through a pipeline of output modules.

The output modules are written in Python and read from their stdin. They echo everything they read from their stdin to their stdout except for their corresponding #OUTPUT control codes. When the output module reads an output control code, it performs an action.

The following outputs modules were written. Of the output modules written, the LCD Text module and LCD RGB Backlight module were demonstrated.

LCD Text

An LCD attached to the control board is updated with the value given to the corresponding output block when the output statement is executed.

LCD RGB Backlight

The LCD attached to the control board has an RBG LED used as a backlight which is updated with the value given to the corresponding output block when the output statement is executed. The modulo 7 of the value given is truncated to an integer which indexes a color in the following list: [red, orange, yellow, green, blue, indigo, violet].

Piezo Buzzer

A piezo buzzer attached to the control board is buzzed a number of times corresponding to the value given to the output block when the output statement is executed. The number of beeps is ceiling 5.

Relay

A relay attached to the control board is closed for a number of time units corresponding to the value given to the output block when the output statement is executed. A time unit is about a half of a second and is ceiling 5.

Stdout

The value given to the output block when the output statement is executed is printed to stdout in an informative way.

23
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

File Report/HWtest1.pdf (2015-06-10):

Test Case Name: | Block of Code Connector Check | Test ID: | ABC-Hardware-01
Description: | Verify electrical connectivity of all processor pins and connectors. | Type: | Black box
Name of Tester: | Daniel Frister and Greg Stromire | Date: | 5/28/2015
Harware Ver: | BlockBoard v2.2 | Time: | 2:00 PM
Setup: | A fully populated individual Block with no external connections. A digital multimeter will be required.
Ste | Action | Expected Result | Pass | Fail | Comments
1 | Measure from processor pin 1 to each connector pin 9. | Electrical connection present. | Pass
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

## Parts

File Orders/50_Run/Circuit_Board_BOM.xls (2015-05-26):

Part: | Cost/Part | Per Board | Cost/Board | Note | Part Number | Source
ATTINY461A SOIC Package | 1.27 | 1 | 1.27 | 50 Unit Price Break | ATTINY461A-SU | http://www.mouser.com/ProductDetail/Atmel/ATTINY461A-SU/
DB9 Connector (Female) | 1.17 | 2 | 2.34 | 100 Unit Price Break | 1734354-1 | http://www.mouser.com/ProductDetail/TE-Connectivity/1734354-1/
DB9 Connector (Male) | 1.18 | 2 | 2.36 | 100 Unit Price Break | 1-1634580-2 | http://www.mouser.com/ProductDetail/TE-Connectivity/1-1634580-2/
10kOhm Resistor 0603 Package | 0.08 | 1 | 0.08 | 10 Unit Price Break | ERJ-PA3J103V | http://www.mouser.com/ProductDetail/Panasonic/ERJ-PA3J103V/
Capacitor 0.01u 0603 Package | 0.11 | 1 | 0.11 | 10 Unit Price Break | C0603C103K9RACTU | http://www.mouser.com/ProductDetail/Kemet/C0603C103K9RACTU/
3mm LED, 2mA, Red | 0.08 | 1 | 0.08 | 10 Unit Price Break | WP710A10LID | http://www.mouser.com/ProductDetail/Kingbright/WP710A10LID/
3mm LED, 2mA, Green | 0.08 | 1 | 0.08 | 25 Unit Price Break | WP710A10LGD | http://www.mouser.com/ProductDetail/Kingbright/WP710A10LGD/
820 Ohm Resistor 0603 Package | 0.09 | 3 | 0.27 | 100 Unit Price Break | CRCW0603820RFKEAHP | http://www.mouser.com/ProductDetail/Vishay-Dale/CRCW0603820RFKEAHP/
3mm LED, 2mA, Yellow | 0.09 | 1 | 0.09 | 10 Unit Price Break | WP710A10LYD | http://www.mouser.com/ProductDetail/Kingbright/WP710A10LYD/
1MOhm Linear Potentiometer | 0.58 | 1 | 0.58 | 50 Unit Price Break | P160KN-0QD15B1MEG | http://www.mouser.com/ProductDetail/TT-Electronics/P160KN-0QD15B1MEG/
 |  | Board Cost: | 7.26
 |  | Board Quantity: | 50
 |  | Total Cost: | 363
PCB Supplier |  |  |  | http://quickturnpcb.co.kr/

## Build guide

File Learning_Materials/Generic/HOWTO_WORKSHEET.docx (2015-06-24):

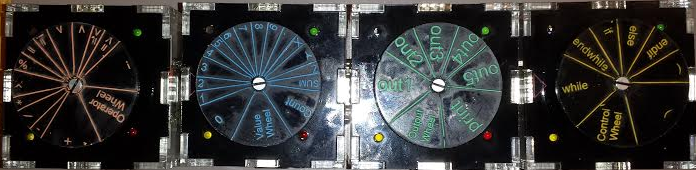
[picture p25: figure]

You may be asking yourself –

1. Who are they for?
2. What can they do?
3. How do you “use” them?
4. Why would I/anyone even use them?

1. So first – the blocks are targeted towards elementary to middle school aged children, their teachers & their parents. But hey, you’re a big kid right? So let’s dig in.

2. The blocks are physical manipulators that allow a user to associate a tangible physical object to an abstract concept – specifically computer programming. The blocks, when connected and “dialed in,” create a functional block of code which is then executed.

3. Use of the blocks can vary (flip to see the worksheet) but in a nutshell consider creating sub-50-character programs to reinforce a concept or validate a formula.

4. Why? Did you play with Legos? When is the first time you saw a computer program? What about an algorithm? This exposes children to a world earlier – and uses something tangible – not abstract to do it.

Your have the following blocks available to you

15 Value Blocks | 15 Operator Blocks | 15 Control Blocks | 7 Output Blocks

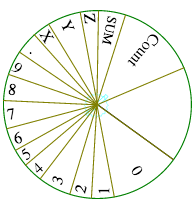
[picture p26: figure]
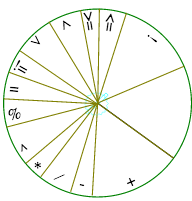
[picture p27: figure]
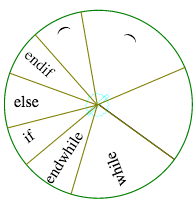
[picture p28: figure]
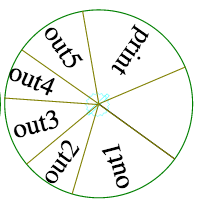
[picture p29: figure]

- a variable {x, y, z, Sum, Count}, or - a value from 1-9 | - = is equality checking NOT assignment | - if, else & endif - while & endwhile - ( & ) | - Sends output to specific channel
Sky Blue | Peach | Dandelion | Sea Green

Ultra Quick Start:

Assign the variable x the value of 6:

x | 6

Assign the variable y the value of 3.4:

y | 3 | . | 4

Check if y is equal to x and assign the value to z

z | ( | y | = | x | )

If z is false print y/x

If | ( | ! | z | )
Print | y | / | x

Endif

Exercise #1: Write a program that prints a temperature given in Fahrenheit into Celsius.

How many blocks does it take you?

Exercise #2: Write a program that computes Fibonacci numbers less than 25.

How many blocks does it take you? <50? <25?

Exercise #3: Create a program from scratch using as many blocks as you can.

What does your program do?

----------------------------------------------------------------------------------------- A Block of Code – Worksheet / Paper Demo Friday, June 5th 2015 More Available online @ www.erebuslabs.com/elaunch

Blocks of Code…

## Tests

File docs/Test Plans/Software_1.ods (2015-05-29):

Test Writer: Daniel Frister
Test Case Name: |  | Block of Code Power On Check |  |  | Test ID: | ABC-Software-01
Description: |  | Verify individual block power on to idle state. |  |  | Type: | Black box
Tester Information:
Name of Tester: |  |  |  |  | Date:
Harware Ver: |  | BlockBoard v2.2 |  |  | Time:
Setup: |  | A fully populated individual Block with no external connections. A DC power supply will be required.
Step | Action | Expected Result | Pass | Fail | Comments
1 | Connect 3.3Vdc to Pin 7 on bottom connector. | No result.
2 | Connect GND to Pin 7 on bottom connector. | Power LED (Red) turns on.
3 | Wait ~2 seconds. | Error LED (Yellow) blinks twice, Status LED (Green) starts blinking until power is removed.
Overall test result

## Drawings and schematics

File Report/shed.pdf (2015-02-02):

## Nathan,Daniel,Greg,Jacob,Tyler

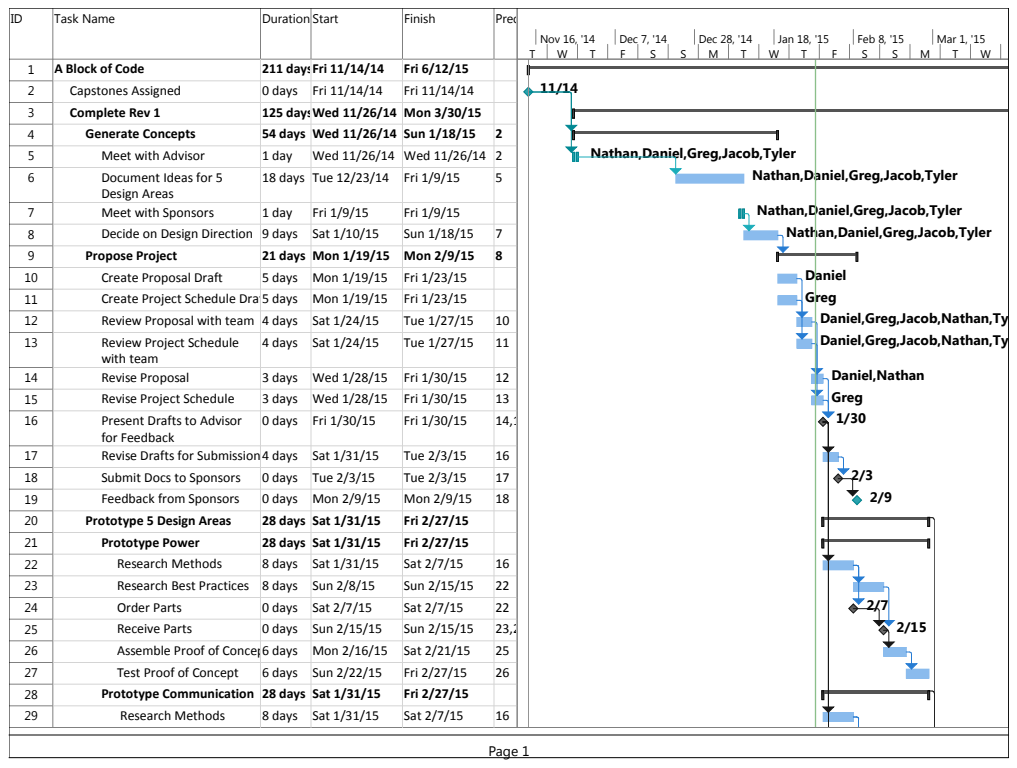
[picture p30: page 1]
Daniel,Nathan Greg 1/30; Nov 16, '14; Dec 7, '14; Dec 28, '14; Jan 18, '15; Feb 8, '15; Mar 1, '15

ID | Task Name | Duration Start | | Finish | Predecessors

1 | A Block of Code | 211 daysFri 11/14/14 | | Fri 6/12/15 | | 11/14 | Nathan,Daniel,Greg,Jacob,Tyler
2 | Capstones Assigned | 0 days | Fri 11/14/14 | Fri 11/14/14
3 | Complete Rev 1 | 125 daysWed 11/26/14 | | Mon 3/30/15
4 | Generate Concepts | 54 days | Wed 11/26/14 | Sun 1/18/15 | 2
5 | Meet with Advisor | 1 day | Wed 11/26/14 | Wed 11/26/14 | 2
6 | Document Ideas for 5 Design Areas | 18 days | Tue 12/23/14 | Fri 1/9/15 | 5

7 | Meet with Sponsors | 1 day | Fri 1/9/15 | Fri 1/9/15
8 | Decide on Design Direction | 9 days | Sat 1/10/15 | Sun 1/18/15 | 7
9 | Propose Project | 21 days | Mon 1/19/15 | Mon 2/9/15 | 8
10 | Create Proposal Draft | 5 days | Mon 1/19/15 | Fri 1/23/15
11 | Create Project Schedule Draft5 days | | Mon 1/19/15 | Fri 1/23/15
12 | Review Proposal with team | 4 days | Sat 1/24/15 | Tue 1/27/15 | 10
13 | Review Project Schedule with team | 4 days | Sat 1/24/15 | Tue 1/27/15 | 11

Nathan,Daniel,Greg,Jacob,Tyler

Daniel
Greg
Daniel,Greg,Jacob,Nathan,Tyle

14 | Revise Proposal | 3 days | Wed 1/28/15 | Fri 1/30/15 | 12
15 | Revise Project Schedule | 3 days | Wed 1/28/15 | Fri 1/30/15 | 13
16 | Present Drafts to Advisor for Feedback | 0 days | Fri 1/30/15 | Fri 1/30/15 | 14,15

17 | Revise Drafts for Submission4 days | | Sat 1/31/15 | Tue 2/3/15 | 16
18 | Submit Docs to Sponsors | 0 days | Tue 2/3/15 | Tue 2/3/15 | 17
19 | Feedback from Sponsors | 0 days | Mon 2/9/15 | Mon 2/9/15 | 18
20 | Prototype 5 Design Areas | 28 days | Sat 1/31/15 | Fri 2/27/15
21 | Prototype Power | 28 days | Sat 1/31/15 | Fri 2/27/15
22 | Research Methods | 8 days | Sat 1/31/15 | Sat 2/7/15 | 16
23 | Research Best Practices | 8 days | Sun 2/8/15 | Sun 2/15/15 | 22
24 | Order Parts | 0 days | Sat 2/7/15 | Sat 2/7/15 | 22
25 | Receive Parts | 0 days | Sun 2/15/15 | Sun 2/15/15 | 23,24
26 | Assemble Proof of Concept6 days | | Mon 2/16/15 | Sat 2/21/15 | 25
27 | Test Proof of Concept | 6 days | Sun 2/22/15 | Fri 2/27/15 | 26
28 | Prototype Communication | 28 days | Sat 1/31/15 | Fri 2/27/15
29 | Research Methods | 8 days | Sat 1/31/15 | Sat 2/7/15 | 16

2/7
2/15

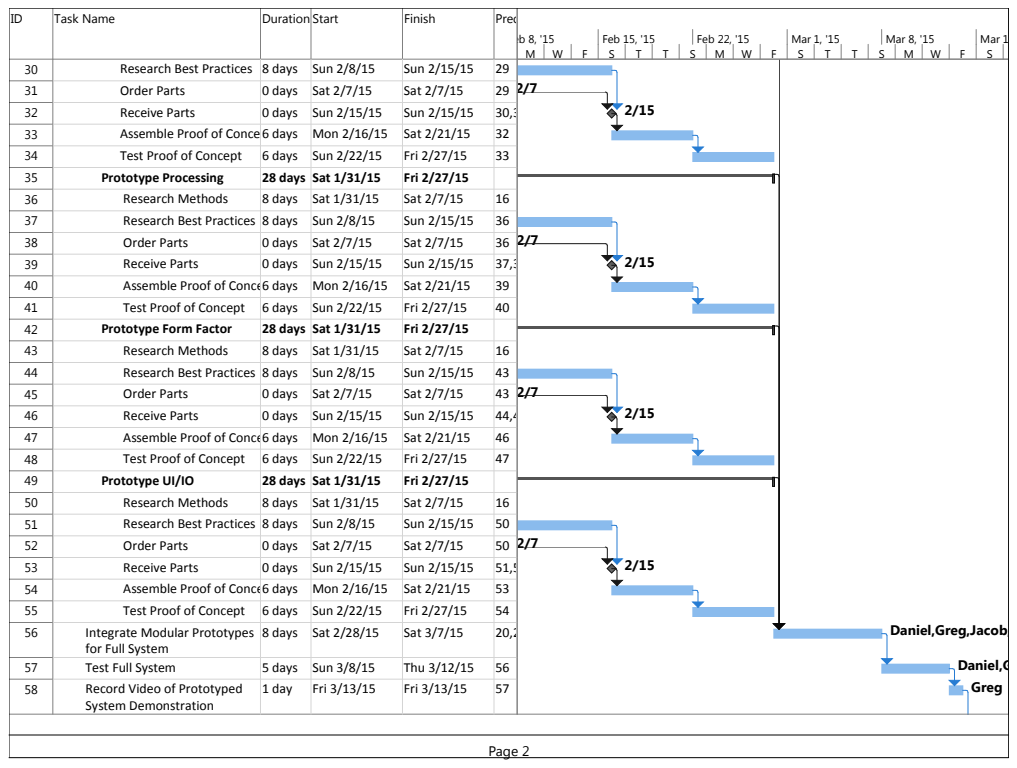
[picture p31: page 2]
8 days; Sat 2/28/15; Sat 3/7/15; Daniel,Gr Greg; Feb 8, '15; Feb 15, '15; Feb 22, '15; Mar 1, '15; Mar 8, '15; Mar 15

30 | Research Best Practices | 8 days | Sun 2/8/15 | Sun 2/15/15 | 29
31 | Order Parts | 0 days | Sat 2/7/15 | Sat 2/7/15 | 29
32 | Receive Parts | 0 days | Sun 2/15/15 | Sun 2/15/15 | 30,31
33 | Assemble Proof of Concept6 days | | Mon 2/16/15 | Sat 2/21/15 | 32
34 | Test Proof of Concept | 6 days | Sun 2/22/15 | Fri 2/27/15 | 33
35 | Prototype Processing | 28 days | Sat 1/31/15 | Fri 2/27/15
36 | Research Methods | 8 days | Sat 1/31/15 | Sat 2/7/15 | 16
37 | Research Best Practices | 8 days | Sun 2/8/15 | Sun 2/15/15 | 36
38 | Order Parts | 0 days | Sat 2/7/15 | Sat 2/7/15 | 36
39 | Receive Parts | 0 days | Sun 2/15/15 | Sun 2/15/15 | 37,38
40 | Assemble Proof of Concept 6 days | | Mon 2/16/15 | Sat 2/21/15 | 39
41 | Test Proof of Concept | 6 days | Sun 2/22/15 | Fri 2/27/15 | 40
42 | Prototype Form Factor | 28 days | Sat 1/31/15 | Fri 2/27/15
43 | Research Methods | 8 days | Sat 1/31/15 | Sat 2/7/15 | 16
44 | Research Best Practices | 8 days | Sun 2/8/15 | Sun 2/15/15 | 43
45 | Order Parts | 0 days | Sat 2/7/15 | Sat 2/7/15 | 43
46 | Receive Parts | 0 days | Sun 2/15/15 | Sun 2/15/15 | 44,45
47 | Assemble Proof of Concept 6 days | | Mon 2/16/15 | Sat 2/21/15 | 46
48 | Test Proof of Concept | 6 days | Sun 2/22/15 | Fri 2/27/15 | 47
49 | Prototype UI/IO | 28 days | Sat 1/31/15 | Fri 2/27/15
50 | Research Methods | 8 days | Sat 1/31/15 | Sat 2/7/15 | 16
51 | Research Best Practices | 8 days | Sun 2/8/15 | Sun 2/15/15 | 50
52 | Order Parts | 0 days | Sat 2/7/15 | Sat 2/7/15 | 50
53 | Receive Parts | 0 days | Sun 2/15/15 | Sun 2/15/15 | 51,52
54 | Assemble Proof of Concept 6 days | | Mon 2/16/15 | Sat 2/21/15 | 53
55 | Test Proof of Concept | 6 days | Sun 2/22/15 | Fri 2/27/15 | 54
56 | Integrate Modular Prototypes for Full System

Daniel,Greg,Jacob,N

57 | Test Full System | 5 days | Sun 3/8/15 | Thu 3/12/15 | 56
58 | Record Video of Prototyped System Demonstration | 1 day | Fri 3/13/15 | Fri 3/13/15 | 57
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

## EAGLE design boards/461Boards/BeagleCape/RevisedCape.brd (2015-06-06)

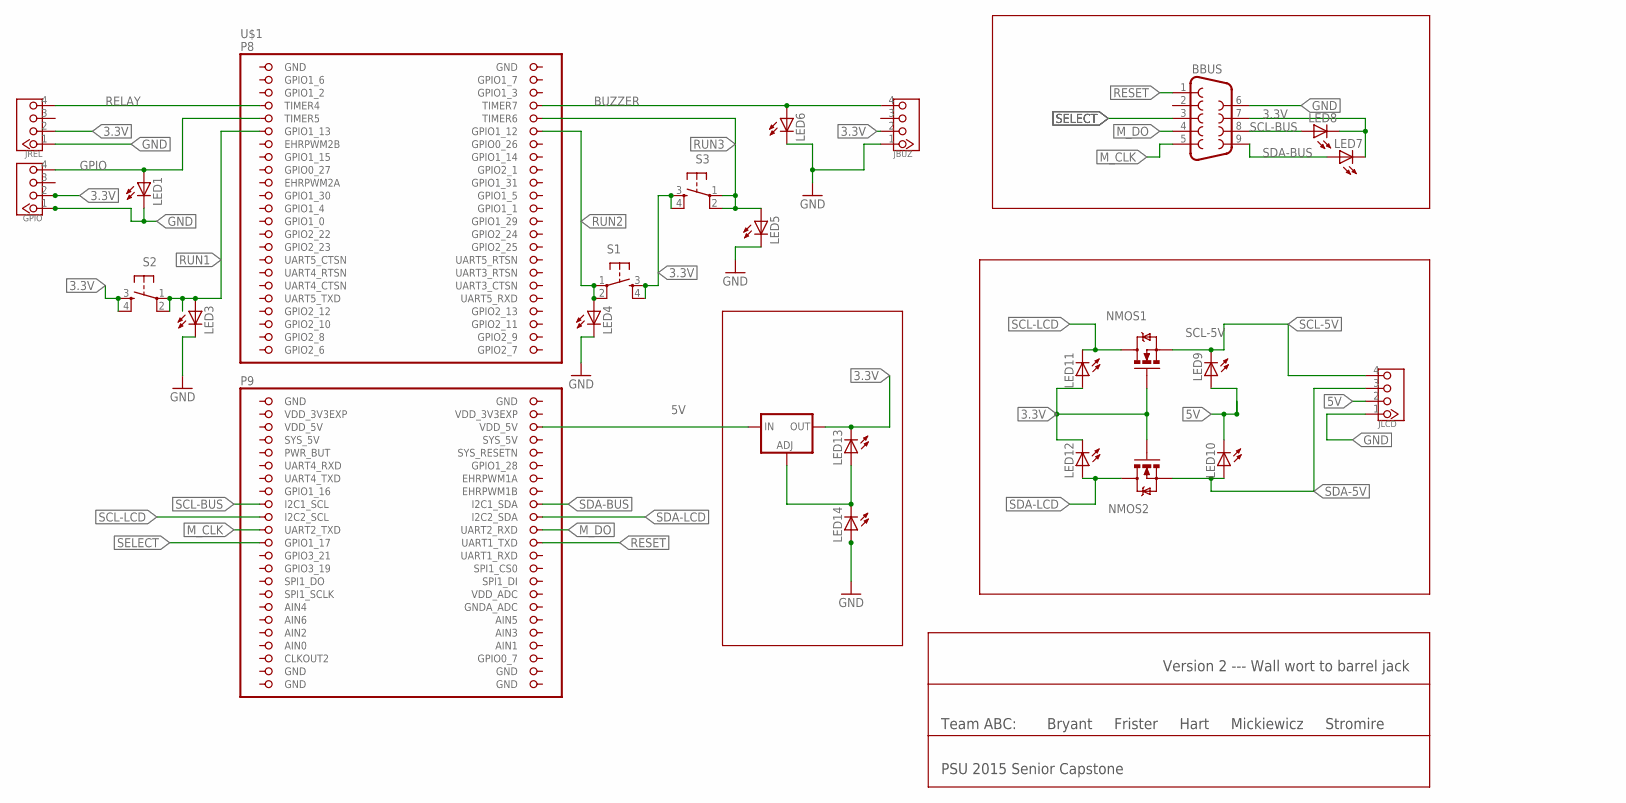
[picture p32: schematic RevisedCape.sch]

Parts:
3.3VREG: V_REG_317SINK; TO220-ADJ
BBUS: F09H
GPIO: TWIG-4P-2.0-2.0; 4P-2.0
JBUZ: TWIG-4P-2.0-2.0; 4P-2.0
JLCD: TWIG-4P-2.0-2.0; 4P-2.0
JREL: TWIG-4P-2.0-2.0; 4P-2.0
LED1, LED3, LED4, LED5, LED6, LED7, LED8, LED9, LED10, LED11, LED12, LED13, LED14: LED3MM
NMOS1, NMOS2: MOSFET-NCHANNEL2N7000; TO-92
S1, S2, S3: TAC_SWITCHPTH; TACTILE-PTH
U$1: BEAGLEBONE_OUTLINE; BEAGLEBONE_SHIELD

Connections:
3.3V: 3.3VREG.OUT, BBUS.7, GPIO.2, JBUZ.2, JREL.2, LED7.K (C), LED8.K (C), LED11.A, LED12.K (C), LED13.K (C), NMOS1.2 (G), NMOS2.2 (G), S1.3, S1.4, S2.3, S2.4, S3.3, S3.4
5V: 3.3VREG.IN, JLCD.2, LED9.A, LED10.K (C), U$1.52 (VDD_5V)
AIN0: U$1.85 (AIN0)
BUZZER: JBUZ.4, LED6.A, U$1.8 (TIMER7)
GND: BBUS.6, GPIO.1, JBUZ.1, JLCD.1, JREL.1, LED1.K (C), LED3.K (C), LED4.K (C), LED5.K (C), LED6.K (C), LED14.A, U$1.1 (GND), U$1.2 (GND), U$1.47 (GND), U$1.48 (GND), U$1.89 (GND), U$1.90 (GND), U$1.91 (GND), U$1.92 (GND)
GPIO: GPIO.4, LED1.A, U$1.9 (TIMER5)
M_CLK: BBUS.5, U$1.67 (UART2_TXD)
M_DO: BBUS.4, U$1.68 (UART2_RXD)
REGADJ: 3.3VREG.ADJ, LED13.A, LED14.K (C)
RELAY: JREL.4, U$1.7 (TIMER4)
RESET: BBUS.1, U$1.70 (UART1_TXD)
RUN1: LED3.A, S2.1, S2.2, U$1.11 (GPIO1_13)
RUN2: LED4.A, S1.1, S1.2, U$1.12 (GPIO1_12)
RUN3: LED5.A, S3.1, S3.2, U$1.10 (TIMER6)
SCL-5V: JLCD.4, LED9.K (C), NMOS1.1 (S)
SCL-BUS: BBUS.8, LED8.A, U$1.63 (I2C1_SCL)
SCL-LCD: LED11.K (C), NMOS1.3 (D), U$1.65 (I2C2_SCL)
SDA-5V: JLCD.3, LED10.A, NMOS2.1 (S)
SDA-BUS: BBUS.9, LED7.A, U$1.64 (I2C1_SDA)
SDA-LCD: LED12.A, NMOS2.3 (D), U$1.66 (I2C2_SDA)
SELECT: BBUS.3, U$1.69 (GPIO1_17)
SYS_5V: U$1.53 (SYS_5V)
VDD_3V3EXP: U$1.49 (VDD_3V3EXP), U$1.50 (VDD_3V3EXP)
VDD_5V: U$1.51 (VDD_5V)

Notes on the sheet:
Team ABC: Bryant Frister Hart Mickiewicz Stromire
PSU 2015 Senior Capstone
Version 2 --- Wall wort to barrel jack

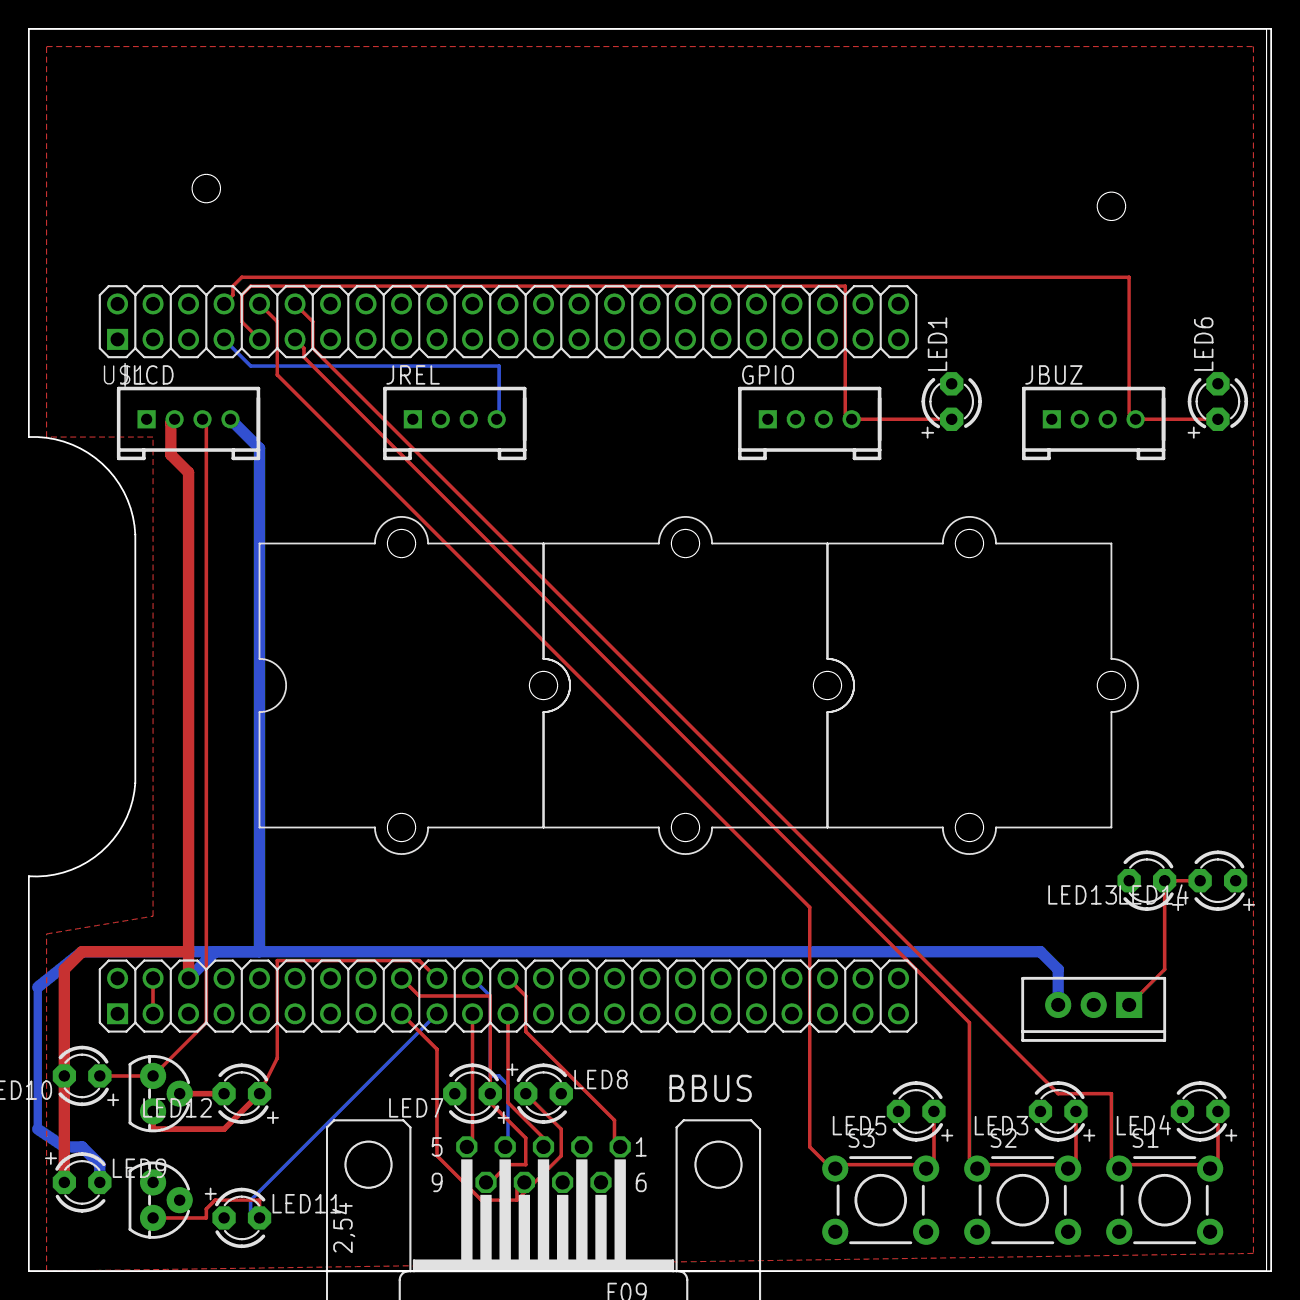
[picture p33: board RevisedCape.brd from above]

Board: 2 copper layers, 88.9 x 88.9 mm, 28 parts (0 on the bottom side), 21 nets.

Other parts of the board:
U$2, U$3, U$4: SEEED

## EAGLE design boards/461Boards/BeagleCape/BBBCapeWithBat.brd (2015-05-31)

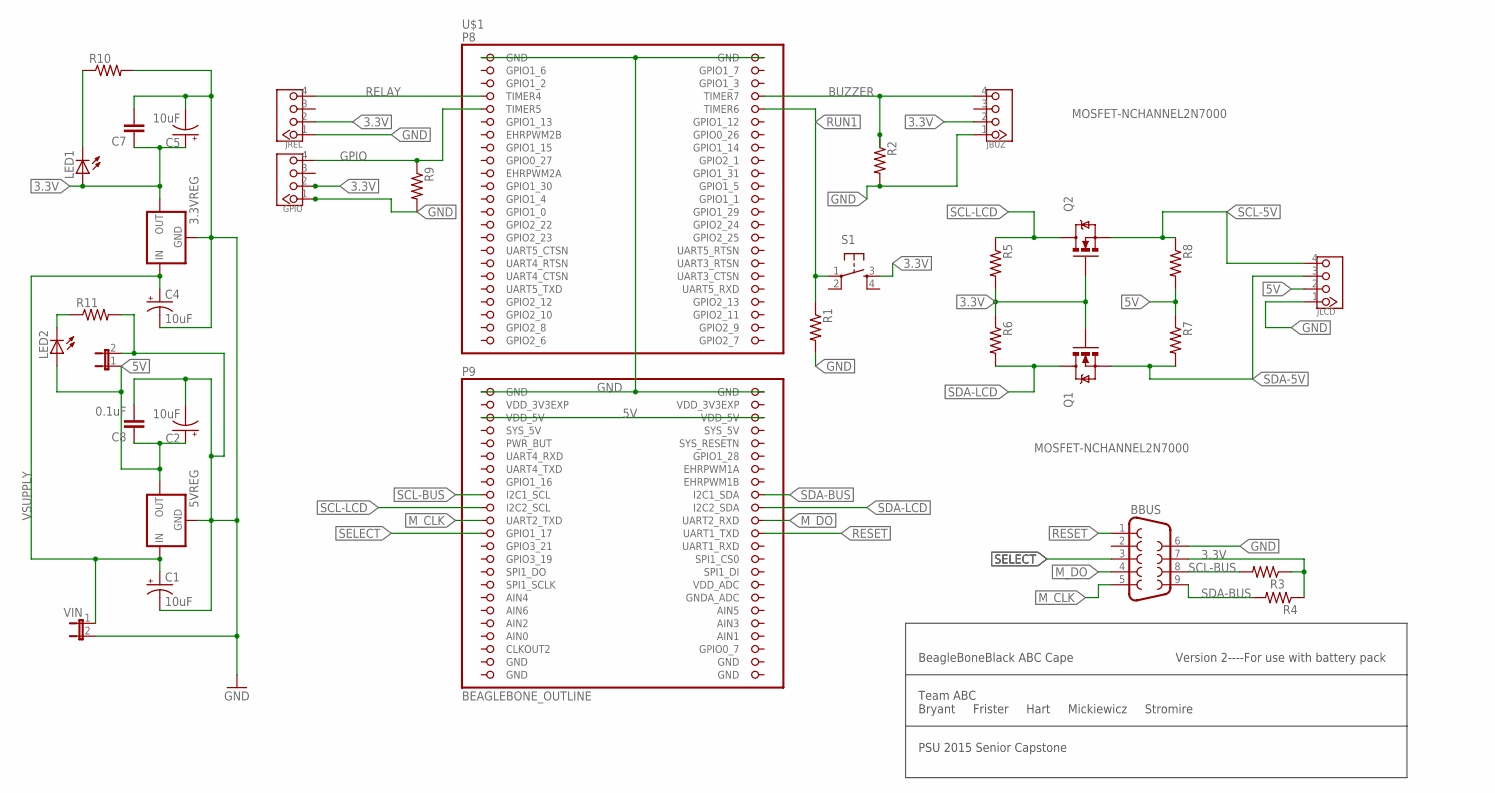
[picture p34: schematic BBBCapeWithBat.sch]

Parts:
3.3VREG, 5VREG: 78XXS
5VOUT: JUMPER-2PTH; 1X02
BBUS: F09H
C1, C2, C4, C5: 10uF; CPOL-RADIAL-10UF-25V
C7: CAPPTH2; CAP-PTH-SMALL2
C8: 0.1uF; CAP-PTH-SMALL2
GPIO: TWIG-4P-2.0-2.0; 4P-2.0
JBUZ: TWIG-4P-2.0-2.0; 4P-2.0
JLCD: TWIG-4P-2.0-2.0; 4P-2.0
JREL: TWIG-4P-2.0-2.0; 4P-2.0
LED1, LED2: LED3MM
Q1, Q2: MOSFET-NCHANNEL2N7000; TO-92
R1, R2, R3, R4, R5, R6, R7, R8, R9, R10, R11: R-US_0204/2V; 0204V
S1: TAC_SWITCHPTH; TACTILE-PTH
U$1: BEAGLEBONE_OUTLINE; BEAGLEBONE_SHIELD
VIN: JUMPER-2PTH; 1X02

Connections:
3.3V: 3.3VREG.OUT, BBUS.7, C5.1 (+), C7.1, GPIO.2, JBUZ.2, JREL.2, LED1.A, Q1.2 (G), Q2.2 (G), R3.1, R4.1, R5.2, R6.1, S1.3
5V: 5VOUT.1, 5VREG.OUT, C2.1 (+), C8.1, JLCD.2, LED2.A, R7.1, R8.2, U$1.51 (VDD_5V), U$1.52 (VDD_5V)
AIN0: U$1.85 (AIN0)
BUZZER: JBUZ.4, R2.1, U$1.8 (TIMER7)
GND: 3.3VREG.GND, 5VOUT.2, 5VREG.GND, BBUS.6, C1.2 (-), C2.2 (-), C4.2 (-), C5.2 (-), C7.2, C8.2, GPIO.1, JBUZ.1, JLCD.1, JREL.1, R1.2, R2.2, R9.2, R10.2, R11.2, U$1.1 (GND), U$1.2 (GND), U$1.47 (GND), U$1.48 (GND), U$1.89 (GND), U$1.90 (GND), U$1.91 (GND), U$1.92 (GND), VIN.2
GPIO: GPIO.4, R9.1, U$1.9 (TIMER5)
M_CLK: BBUS.5, U$1.67 (UART2_TXD)
M_DO: BBUS.4, U$1.68 (UART2_RXD)
unnamed: LED2.K (C), R11.1
unnamed: LED1.K (C), R10.1
RELAY: JREL.4, U$1.7 (TIMER4)
RESET: BBUS.1, U$1.70 (UART1_TXD)
RUN1: R1.1, S1.1, U$1.10 (TIMER6)
SCL-5V: JLCD.4, Q2.1 (S), R8.1
SCL-BUS: BBUS.8, R3.2, U$1.63 (I2C1_SCL)
SCL-LCD: Q2.3 (D), R5.1, U$1.65 (I2C2_SCL)
SDA-5V: JLCD.3, Q1.1 (S), R7.2
SDA-BUS: BBUS.9, R4.2, U$1.64 (I2C1_SDA)
SDA-LCD: Q1.3 (D), R6.2, U$1.66 (I2C2_SDA)
SELECT: BBUS.3, U$1.69 (GPIO1_17)
SYS_5V: U$1.53 (SYS_5V)
VDD_3V3EXP: U$1.49 (VDD_3V3EXP), U$1.50 (VDD_3V3EXP)
VSUPPLY: 3.3VREG.IN, 5VREG.IN, C1.1 (+), C4.1 (+), VIN.1

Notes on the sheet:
BeagleBoneBlack ABC Cape
Team ABC Bryant Frister Hart Mickiewicz Stromire
PSU 2015 Senior Capstone
Version 2----For use with battery pack

Board: 2 copper layers, 32 parts (0 on the bottom side), 21 nets, no tracks yet.

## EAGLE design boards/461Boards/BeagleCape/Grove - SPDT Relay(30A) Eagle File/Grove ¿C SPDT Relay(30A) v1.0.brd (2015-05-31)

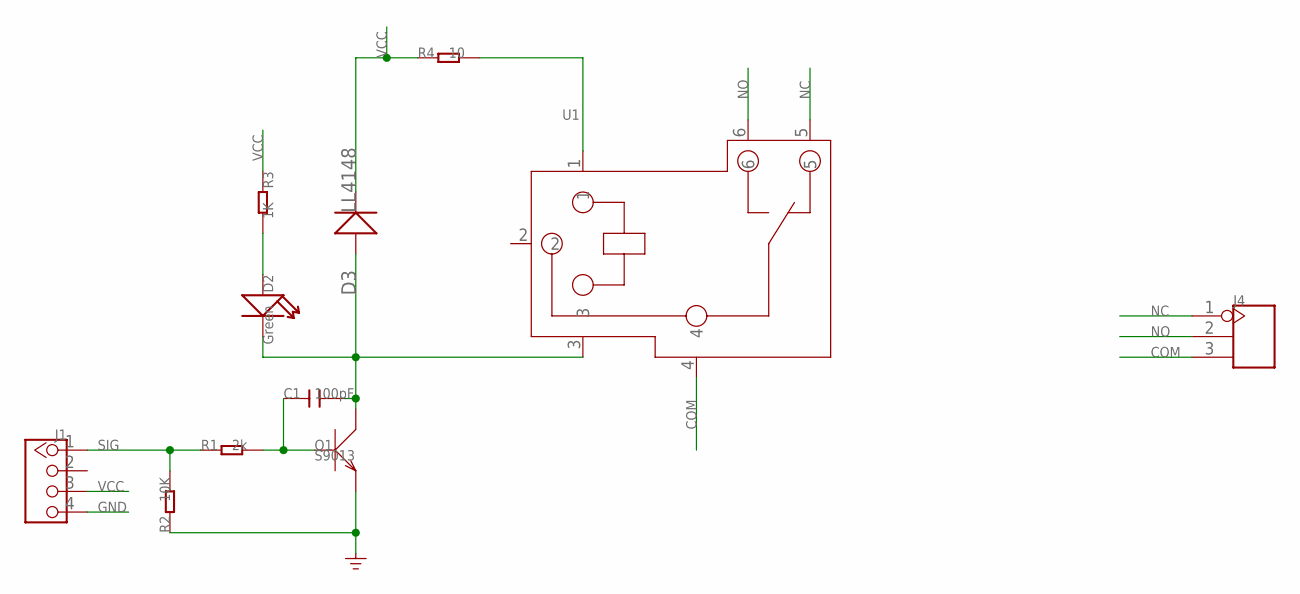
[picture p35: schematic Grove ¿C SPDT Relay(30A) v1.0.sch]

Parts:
C1: 100pF; C0603
D2: Green; LED-0603
D3: LL4148; DO-35-SMD
J1: TWIG-4P-2.0-2.0; 4P-2.0
J4: SCREW-TERMINAL-3P'5.08'; 3P-5.08
Q1: S9013; SOT23
R1: 2k; R0603
R2: 10K; R0603
R3: 1K; R0603
R4: 10; R0603
U1: RELAY-SLA-05VDC-SL-C; 6P-19.8H

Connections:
COM: J4.3, U1.4
GND: J1.4, Q1.2 (E), R2.1
unnamed: C1.1, Q1.1 (B), R1.2
unnamed: D2.+, R3.2
unnamed: C1.2, D2.-, D3.A (+), Q1.3 (C), U1.3
unnamed: R4.2, U1.1
NC: J4.1, U1.5
NO: J4.2, U1.6
SIG: J1.1, R1.1, R2.2
VCC: D3.C (-), J1.3, R3.1, R4.1

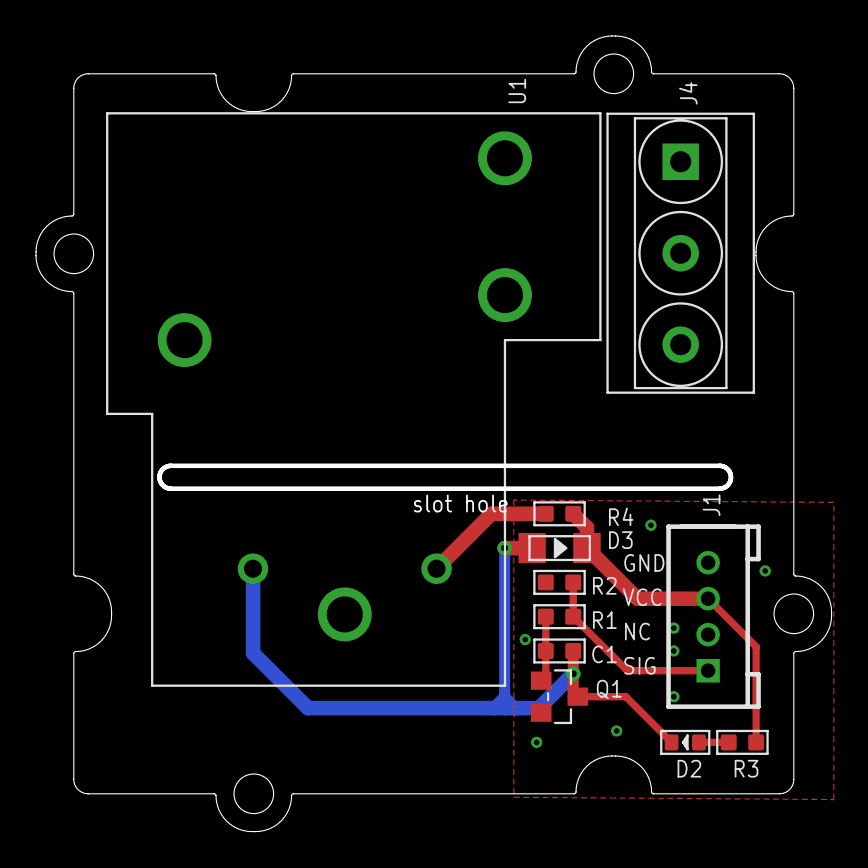
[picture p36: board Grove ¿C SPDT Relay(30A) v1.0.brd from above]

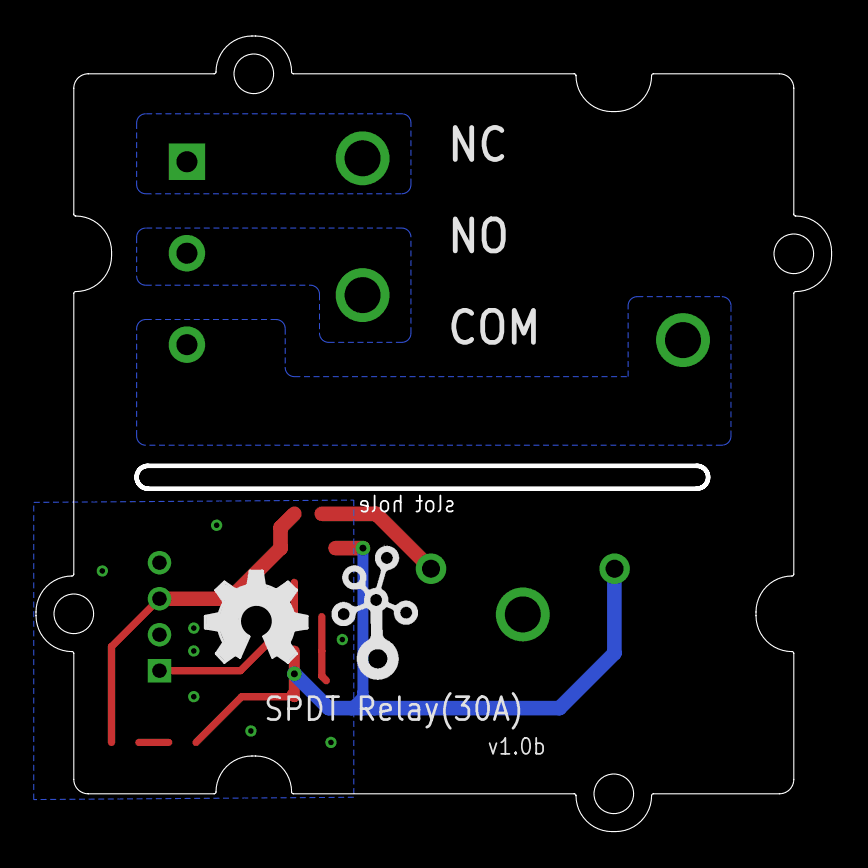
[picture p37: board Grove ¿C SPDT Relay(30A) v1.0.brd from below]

Board: 2 copper layers, 44.2 x 44.2 mm, 14 parts (2 on the bottom side), 10 nets.

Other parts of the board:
U$3: 2X2U-DIM-W/-DRILL
U$4: OSHW_FILLX200_NOTEXT
U$5: TWIGLOGO

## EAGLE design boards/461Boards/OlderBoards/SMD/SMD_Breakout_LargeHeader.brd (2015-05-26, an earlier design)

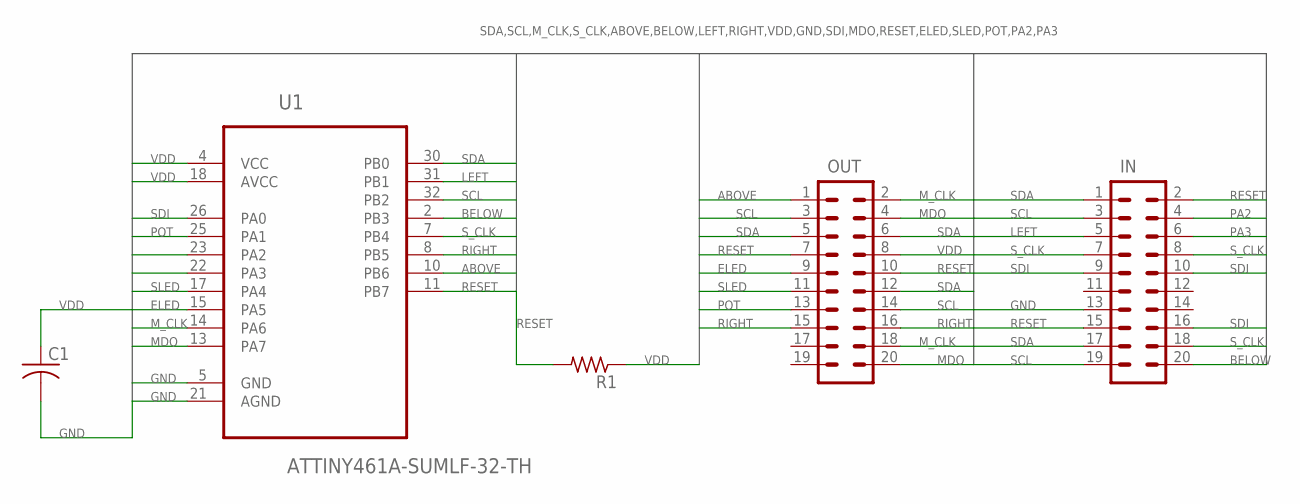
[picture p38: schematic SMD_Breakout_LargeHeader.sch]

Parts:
C1: C-USC0603; C0603
IN: M10X2; 2X10
OUT: M10X2; 2X10
R1: R-US_R0603; R0603
U1: ATTINY461A-SUMLF-32-TH; MLF32-TH

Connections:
ABOVE: OUT.1, U1.10 (PB6)
BELOW: IN.20, U1.2 (PB3)
ELED: OUT.9, U1.15 (PA5)
GND: C1.2, IN.13, U1.5 (GND), U1.21 (AGND)
LEFT: IN.5, U1.31 (PB1)
MDO: OUT.4, OUT.20, U1.13 (PA7)
M_CLK: OUT.2, OUT.18, U1.14 (PA6)
PA2: IN.4, U1.23 (PA2)
PA3: IN.6, U1.22 (PA3)
POT: OUT.13, U1.25 (PA1)
RESET: IN.2, IN.15, OUT.7, OUT.10, R1.2, U1.11 (PB7)
RIGHT: OUT.15, OUT.16, U1.8 (PB5)
SCL: IN.3, IN.19, OUT.3, OUT.14, U1.32 (PB2)
SDA: IN.1, IN.17, OUT.5, OUT.6, OUT.12, U1.30 (PB0)
SDI: IN.9, IN.10, IN.16, U1.26 (PA0)
SLED: OUT.11, U1.17 (PA4)
S_CLK: IN.7, IN.8, IN.18, U1.7 (PB4)
VDD: C1.1, OUT.8, R1.1, U1.4 (VCC), U1.18 (AVCC)

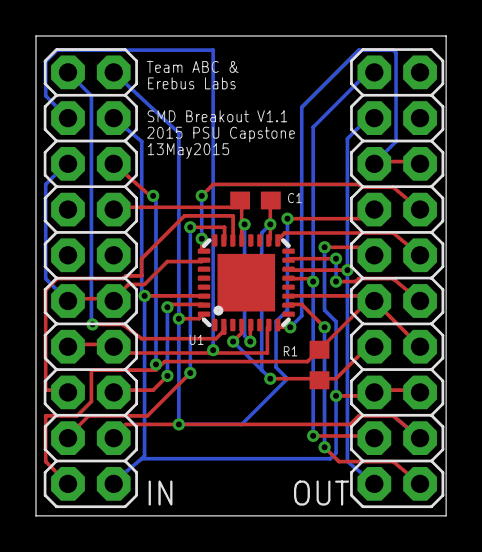
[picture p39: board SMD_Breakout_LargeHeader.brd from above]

Board: 2 copper layers, 22.8 x 26.7 mm, 5 parts (0 on the bottom side), 18 nets.

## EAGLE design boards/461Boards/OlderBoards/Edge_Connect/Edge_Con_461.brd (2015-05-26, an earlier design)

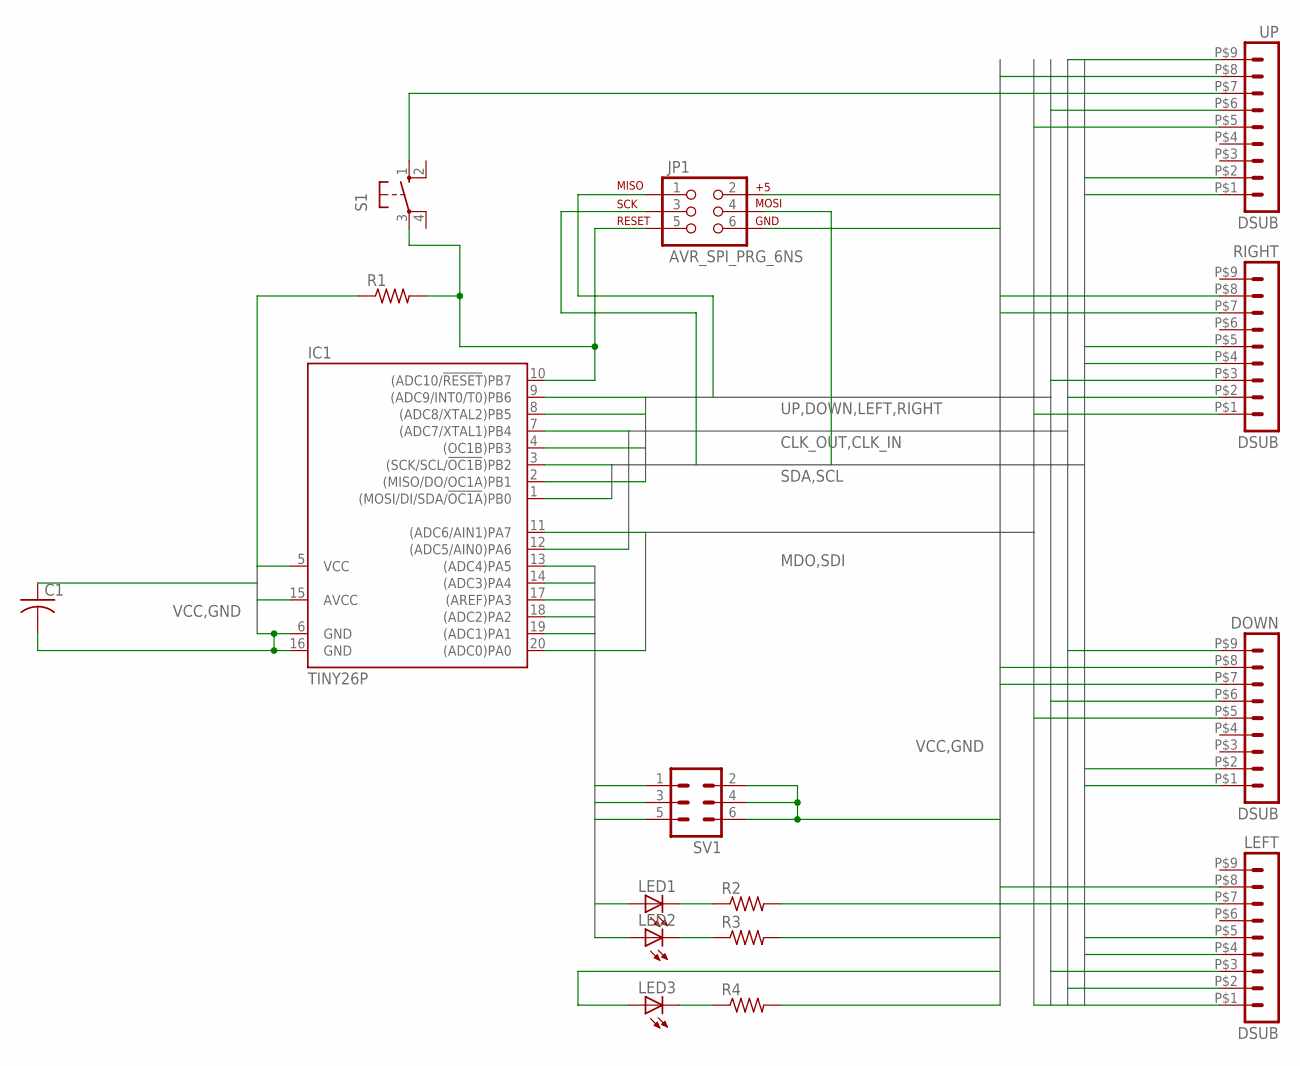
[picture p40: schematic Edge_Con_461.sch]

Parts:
C1: C-US025-025X050; C025-025X050
DOWN: DSUB; FOUR
IC1: TINY26P; DIL20
JP1: AVR_SPI_PRG_6NS; 2X3-NS
LED1, LED2, LED3: LED3MM
LEFT: DSUB; FOUR
R1, R2, R3, R4: R-US_0204/5; 0204/5
RIGHT: DSUB; FOUR
S1: 10-XX; B3F-10XX
SV1: MA03-2
UP: DSUB; FOUR

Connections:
13: IC1.13 ((ADC4)PA5), LED1.A
14: IC1.14 ((ADC3)PA4), LED2.A
17: IC1.17 ((AREF)PA3), SV1.5
18: IC1.18 ((ADC2)PA2), SV1.3
19: IC1.19 ((ADC1)PA1), SV1.1
CLK_IN: DOWN.P$9 (9), IC1.7 ((ADC7/XTAL1)PB4), LEFT.P$2 (2)
CLK_OUT: IC1.12 ((ADC5/AIN0)PA6), RIGHT.P$2 (2), UP.P$9 (9)
DOWN: DOWN.P$6 (6), IC1.4 ((OC1B)PB3)
GND: C1.2, DOWN.P$7 (7), IC1.6 (GND), IC1.16 (GND), JP1.6, LEFT.P$7 (7), R2.2, R3.2, R4.2, RIGHT.P$7 (7), S1.1 (S), SV1.2, SV1.4, SV1.6, UP.P$7 (7)
LEFT: IC1.2 ((MISO/DO/OC1A)PB1), JP1.1, LEFT.P$3 (3)
MDO: IC1.11 ((ADC6/AIN1)PA7), RIGHT.P$1 (1), UP.P$5 (5)
unnamed: IC1.10 ((ADC10/!RESET!)PB7), JP1.5, R1.2, S1.3
unnamed: LED3.K (C), R4.1
unnamed: LED1.K (C), R2.1
unnamed: LED2.K (C), R3.1
RIGHT: IC1.8 ((ADC8/XTAL2)PB5), RIGHT.P$3 (3)
SCL: DOWN.P$2 (2), IC1.3 ((SCK/SCL/!OC1B!)PB2), JP1.3, LEFT.P$5 (5), RIGHT.P$5 (5), UP.P$2 (2)
SDA: DOWN.P$1 (1), IC1.1 ((MOSI/DI/SDA/!OC1A!)PB0), JP1.4, LEFT.P$4 (4), RIGHT.P$4 (4), UP.P$1 (1)
SDI: DOWN.P$5 (5), IC1.20 ((ADC0)PA0), LEFT.P$1 (1)
UP: IC1.9 ((ADC9/INT0/T0)PB6), UP.P$6 (6)
VCC: C1.1, DOWN.P$8 (8), IC1.5 (VCC), IC1.15 (AVCC), JP1.2, LED3.A, LEFT.P$8 (8), R1.1, RIGHT.P$8 (8), UP.P$8 (8)

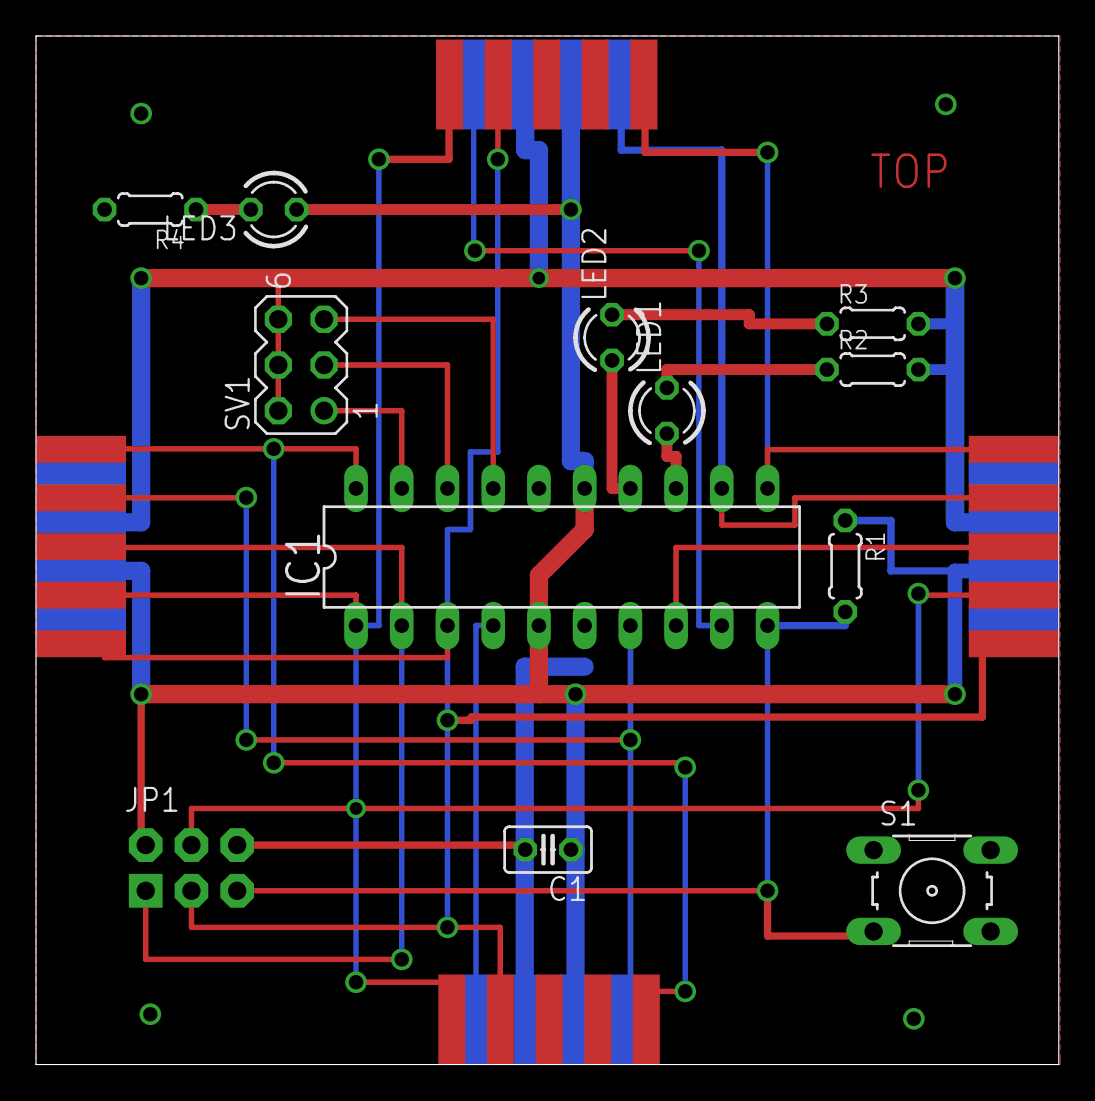
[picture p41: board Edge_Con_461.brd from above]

Board: 2 copper layers, 56.8 x 57.1 mm, 16 parts (0 on the bottom side), 21 nets.

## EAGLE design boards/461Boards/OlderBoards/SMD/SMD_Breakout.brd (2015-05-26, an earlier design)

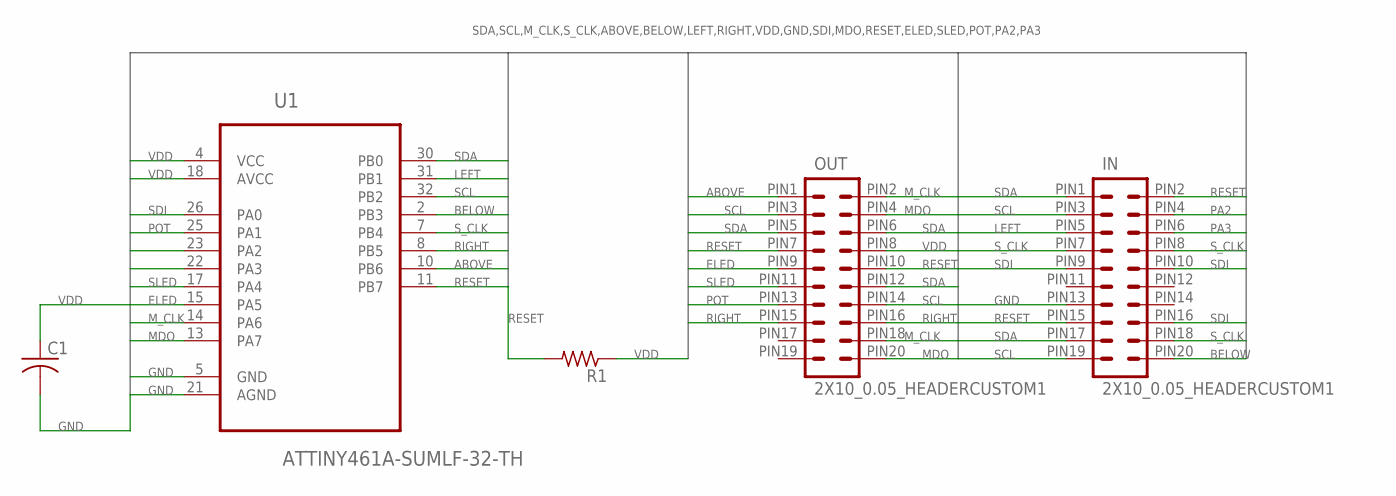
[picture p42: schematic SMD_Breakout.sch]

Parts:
C1: C-USC0603; C0603
IN: 2X10_0.05_HEADERCUSTOM1; 2X10_CUSTOM
OUT: 2X10_0.05_HEADERCUSTOM1; 2X10_CUSTOM
R1: R-US_R0603; R0603
U1: ATTINY461A-SUMLF-32-TH; MLF32-TH

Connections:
ABOVE: OUT.PIN1 (1), U1.10 (PB6)
BELOW: IN.PIN20 (20), U1.2 (PB3)
ELED: OUT.PIN9 (9), U1.15 (PA5)
GND: C1.2, IN.PIN13 (13), U1.5 (GND), U1.21 (AGND)
LEFT: IN.PIN5 (5), U1.31 (PB1)
MDO: OUT.PIN4 (4), OUT.PIN20 (20), U1.13 (PA7)
M_CLK: OUT.PIN2 (2), OUT.PIN18 (18), U1.14 (PA6)
PA2: IN.PIN4 (4), U1.23 (PA2)
PA3: IN.PIN6 (6), U1.22 (PA3)
POT: OUT.PIN13 (13), U1.25 (PA1)
RESET: IN.PIN2 (2), IN.PIN15 (15), OUT.PIN7 (7), OUT.PIN10 (10), R1.2, U1.11 (PB7)
RIGHT: OUT.PIN15 (15), OUT.PIN16 (16), U1.8 (PB5)
SCL: IN.PIN3 (3), IN.PIN19 (19), OUT.PIN3 (3), OUT.PIN14 (14), U1.32 (PB2)
SDA: IN.PIN1 (1), IN.PIN17 (17), OUT.PIN5 (5), OUT.PIN6 (6), OUT.PIN12 (12), U1.30 (PB0)
SDI: IN.PIN9 (9), IN.PIN10 (10), IN.PIN16 (16), U1.26 (PA0)
SLED: OUT.PIN11 (11), U1.17 (PA4)
S_CLK: IN.PIN7 (7), IN.PIN8 (8), IN.PIN18 (18), U1.7 (PB4)
VDD: C1.1, OUT.PIN8 (8), R1.1, U1.4 (VCC), U1.18 (AVCC)

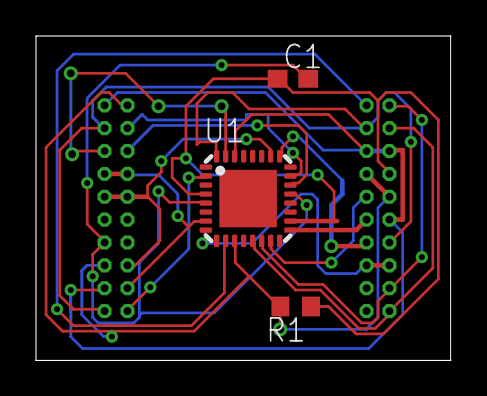
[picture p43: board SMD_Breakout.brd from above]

Board: 2 copper layers, 23.0 x 18.0 mm, 5 parts (0 on the bottom side), 18 nets.

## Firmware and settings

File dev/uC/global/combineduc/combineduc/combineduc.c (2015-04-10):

//
// Daisy Chain utility for the A Block of Code Project
// Greg Stromire
//

#include <stdio.h>
#include <avr/io.h>
#include <avr/interrupt.h>
#include <util/delay.h>
//#include <inttypes.h>
#include "i2c_slave.h"

#define TESTING 1

/**
 *	Microcontroller selection
 */
//#define MCU_2313
#define MCU_461

/**
 *	Using the ATtiny2313 model microcontrollers
 */
#ifdef MCU_2313

// Testing LED (Debug)
#if TESTING
#define STATUS_LED		PD6
#define STATUS_PORT		PORTD
#define TOGGLE_STATUS	(STATUS_PORT ^= _BV(STATUS_LED))
#endif

// Error LED
#define ERROR_LED		PD5
#define ERROR_PORT		PORTD
#define TOGGLE_ERROR	(ERROR_PORT ^= _BV(ERROR_LED))

// SPI Slave Pins
#define SPI_S_DI_REG	PINA
#define SPI_S_DI		PINA0
#define SPI_S_PIN_REG	PINB
#define SPI_S_CLK		PINB2
#define SS_F_BELOW		PINB1
#define SS_F_LEFT		PINB0
#define SPI_S_DDR		DDRB
#define SPI_S_CLK_DIR	DDB2
#define SPI_F_B_DIR		DDB1
#define SPI_F_L_DIR		DDB0
#define SPI_S_DI_DDR	DDRA
#define SPI_S_DI_DIR	DDRA0
#define SPI_S_PORT		PORTB
#define SPI_S_INT_PORT	PCIE
#define SPI_S_CLK_PCINT	PCINT2
#define SPI_F_B_PCINT	PCINT1
#define SPI_F_L_PCINT	PCINT0
//#define SPI_S_DO		PORTA0
//#define SPI_S_DO_DDR	DDRA
//#define SPI_S_DO_DIR	DDRA0

// SPI Master Pins
#define SPI_M_DO_REG	PORTA
#define SPI_M_DO		PORTA1
#define SPI_M_PIN_REG	PINB
#define SPI_M_CLK		PINB6
#define SS_T_ABOVE		PINB4
#define SS_T_RIGHT		PINB3
#define SPI_M_DDR		DDRB
#define SPI_M_CLK_DIR	DDB6
#define SPI_T_A_DIR		DDB4
#define SPI_T_R_DIR		DDB3
#define SPI_M_DO_DDR	DDRA
#define SPI_M_DO_DIR	DDRA1
#define SPI_M_PORT		PORTB
#define SPI_M_INT_PORT	PCIE
#define SPI_T_A_PCINT	PCINT4
#define SPI_T_R_PCINT	PCINT3
//#define SPI_S_DI		PORTA0
//#define SPI_S_DI_DDR	DDRA
//#define SPI_S_DI_DIR	DDRA0


//#define SPI_M_DI	PINA0

/**
 *	Using the ATtiny461 model microcontrollers
 */
//#elif MCU_461

#endif

#ifdef MCU_461

// Testing LED (Debug)
#if TESTING
#define STATUS_LED		PA0
#define STATUS_PORT		PORTA
#define TOGGLE_STATUS	(STATUS_PORT ^= _BV(STATUS_LED))
#endif

// Error LED
#define ERROR_LED		PA3
#define ERROR_PORT		PORTA
#define TOGGLE_ERROR	(ERROR_PORT ^= _BV(ERROR_LED))

// SPI Slave Pins
#define SPI_S_DI_REG	PINA
#define SPI_S_DI		PINA6
#define SPI_S_PIN_REG	PINB
#define SPI_S_CLK		PINB4
#define SS_F_BELOW		PINB3
#define SS_F_LEFT		PINB1
#define SPI_S_DDR		DDRB
#define SPI_S_CLK_DIR	DDB4
#define SPI_F_B_DIR		DDB3
#define SPI_F_L_DIR		DDB1
#define SPI_S_DI_DDR	DDRA
#define SPI_S_DI_DIR	DDA6
#define SPI_S_PORT		PORTB
#define SPI_S_INT_PORT	PCIE0
#define SPI_CLK_INT_PRT	PCIE1
#define SPI_S_CLK_PCINT	PCINT12
#define SPI_F_B_PCINT	PCINT11
#define SPI_F_L_PCINT	PCINT9
#define SPI_PCMSK		PCMSK1
//#define SPI_S_DO		PORTA0
//#define SPI_S_DO_DDR	DDRA
//#define SPI_S_DO_DIR	DDRA0

// SPI Master Pins
#define SPI_M_DO_REG	PORTA
#define SPI_M_DO		PORTA7
#define SPI_M_PIN_REG	PINB
#define SPI_M_CLK		PORTA3
#define SS_T_ABOVE		PINB6
#define SS_T_RIGHT		PINB5
#define SPI_M_DDR		DDRB
#define SPI_M_CLK_DIR	DDB7
#define SPI_T_A_DIR		DDB6
#define SPI_T_R_DIR		DDB5
#define SPI_M_DO_DDR	DDRA
#define SPI_M_DO_DIR	DDA7
#define SPI_M_PORT		PORTB
#define SPI_M_INT_PORT	PCIE1
#define SPI_T_A_PCINT	PCINT14
#define SPI_T_R_PCINT	PCINT13
//#define SPI_S_DI		PORTA0
//#define SPI_S_DI_DDR	DDRA
//#define SPI_S_DI_DIR	DDRA0

#endif


// keep track of current program state
typedef enum {
	PowerOn,
	StartHandshake,
	EndHandshake,
	SpiSlave,
	SpiMasterHandshake,
	SpiMaster,
	TwoWireTransmission
//	...
} ProgramState;

// modified in ISRs
volatile static ProgramState cur_state	= PowerOn;
volatile static uint8_t hs_started		= 0;
volatile static uint8_t hs_ended		= 0;

volatile static uint8_t spi_s_data_in	= 0;
volatile static uint8_t s_data_in_pos	= 8;

volatile static uint8_t spi_m_data_out	= 0;
volatile static uint8_t m_data_out_pos	= 8;

#ifdef SPI_S_DO
volatile static uint8_t spi_s_data_out	= 0;
volatile static uint8_t s_data_out_pos	= 8;
#endif

volatile static uint8_t prev_pin_b		= 0;
volatile static uint8_t prev_pin_d		= 0;
volatile static uint8_t trig_f_below	= 0;
volatile static uint8_t trig_f_left		= 0;
volatile static uint8_t rx_completed	= 0;
volatile static uint8_t tx_completed	= 0;
volatile static uint8_t i2c_addr		= 0;

volatile static uint8_t irc_count		= 0;

static const uint8_t m_clk_ms			= 2;

static void initSPISlave(void);
static void initSPIMaster(void);
static void showAddress(void);
static void initIO(void);
static void startupSequence(void);

static void initHandshake(void);

static void serviceHandshakeStart(void);
static void serviceHandshakeEnd(void);
static void serviceSpiSlaveTransmission(uint8_t changedPins);
static void serviceMasterHandshake(uint8_t changedPins);

static void waitForCompletedHandshake(void);
static void sendVector(uint8_t newBlockDirection);

//void setup_i2c();
//int loop_i2c();

/**
 *	Initializes pins and registers for handshake protocol
 */
void initHandshake(void) {
	
	cur_state = StartHandshake;

	// SPI signal directions
	SPI_S_DDR	 &= ~_BV(SPI_S_CLK_DIR);	// set slave clock as input
	SPI_S_DI_DDR &= ~_BV(SPI_S_DI_DIR);		// set slave DI as input
	
	// set slave selects temporarily as outputs to "announce" new block presence
	SPI_S_DDR	 |= _BV(SPI_F_B_DIR);
	SPI_S_DDR	 |= _BV(SPI_F_L_DIR);
	
	// start slave selects low
	SPI_S_PORT	 &= ~_BV(SS_F_BELOW);
	SPI_S_PORT	 &= ~_BV(SS_F_LEFT);
	
	// enable pin change interrupts (PCI)
	GIMSK		 |= _BV(SPI_S_INT_PORT);	// SPI slave interrupt port
	GIMSK		 |= _BV(SPI_CLK_INT_PRT);	// SPI slave clock interrupt port
	SPI_PCMSK	 |= _BV(SPI_S_CLK_PCINT);	// SPI slave clock
	
	sei();									// enable interrupts
}

/**
 *	Initializes pins and registers for software SPI-slave implementation
 */
void initSPISlave(void) {
	
	cur_state = SpiSlave;
	
	// SPI signal directions
	SPI_S_DDR	 &= ~_BV(SPI_S_CLK_DIR);	// set slave clock as input
	SPI_S_DI_DDR &= ~_BV(SPI_S_DI_DIR);		// set slave DI as input
	SPI_S_DDR	 &= ~_BV(SPI_F_B_DIR);		// set slave selects as inputs
	SPI_S_DDR	 &= ~_BV(SPI_F_L_DIR);
	
	// SPI pull-up resistors
	SPI_S_PORT |= _BV(SS_F_BELOW);			// slave select from below
	SPI_S_PORT |= _BV(SS_F_LEFT);			// slave select from left
	
	// previous port values associated with pull-ups
	prev_pin_b |= _BV(SS_F_BELOW);			// initialized to high
	prev_pin_b |= _BV(SS_F_LEFT);			// "slave select" pulls low
	
	// enable pin change interrupts (PCI)
	GIMSK	  |= _BV(SPI_S_INT_PORT);		// SPI slave interrupt port
	GIMSK	  |= _BV(SPI_CLK_INT_PRT);		// SPI slave clock interrupt port
	SPI_PCMSK |= _BV(SPI_S_CLK_PCINT);		// SPI slave clock
	SPI_PCMSK |= _BV(SPI_F_B_PCINT);		// slave select from below
	SPI_PCMSK |= _BV(SPI_F_L_PCINT);		// slave select from left
	
	#ifdef SPI_S_DO
	SPI_S_DO_DDR |=  _BV(SPI_S_DO_DIR);		// set slave DO as output
	spi_s_data_out = 6;						// initial value
	#endif
	
	//	sei();									// enable interrupts
}

void initSPIMaster(void) {
	
	// disable interrupts for setup
	//	cli();
	
	cur_state = SpiMasterHandshake;
	
	// SPI master signal directions
	SPI_M_DO_DDR |= _BV(SPI_M_CLK_DIR);		// set master clock as output
	SPI_M_DO_DDR |= _BV(SPI_M_DO_DIR);		// set master DO as output
	
	// set slave-selects temporarily as inputs to "listen"
	// for new block presence
	SPI_M_DDR	 &= ~_BV(SPI_T_A_DIR);
	SPI_M_DDR	 &= ~_BV(SPI_T_R_DIR);
	
	// enable pin change interrupts (PCI)
	GIMSK		 |= _BV(SPI_M_INT_PORT);	// SPI interrupt port
	SPI_PCMSK	 |= _BV(SPI_T_A_PCINT);		// SPI slave select to-right intrpt
	SPI_PCMSK	 |= _BV(SPI_T_R_PCINT);		// SPI slave select to-above intrpt
	
	// re-enable interrupts
	//	sei();
}

void serviceHandshakeStart(void) {
	if (prev_pin_b & _BV(SPI_S_CLK)) {
		// HIGH to LOW transition - change state
		
		/*
		 if (hs_started) {
			cur_state = EndHandshake;
			
			// set slave selects as inputs
			SPI_S_DDR	&= ~_BV(SPI_F_B_DIR);
			SPI_S_DDR	&= ~_BV(SPI_F_L_DIR);
			
			// SPI pull-up resistors
			SPI_S_PORT	|= _BV(SS_F_BELOW);			// slave select from below
			SPI_S_PORT	|= _BV(SS_F_LEFT);			// slave select from left
			
			// previous port values associated with pull-ups
			prev_pin_b	|= _BV(SS_F_BELOW);			// initialized to high
			prev_pin_b	|= _BV(SS_F_LEFT);			// "slave select" pulls low
		 }
		 */
		
	} else {
		// LOW to HIGH transition - sample
		
		// if data-in is high, handshake has started
		if (!!(SPI_S_DI_REG & _BV(SPI_S_DI))) {
			hs_started = 1;
		} else {
			// if data-in is low, handshake is completing
			if (hs_started) {
				cur_state = EndHandshake;
				
				// set slave selects as inputs
				SPI_S_DDR	&= ~_BV(SPI_F_B_DIR);
				SPI_S_DDR	&= ~_BV(SPI_F_L_DIR);
				
				// SPI pull-up resistors
				SPI_S_PORT	|= _BV(SS_F_BELOW);			// slave select from below
				SPI_S_PORT	|= _BV(SS_F_LEFT);			// slave select from left
				
				// previous port values associated with pull-ups
				prev_pin_b	|= _BV(SS_F_BELOW);			// initialized to high
				prev_pin_b	|= _BV(SS_F_LEFT);			// "slave select" pulls low
			}
		}
	}
}

void serviceHandshakeEnd(void) {
	if (prev_pin_b & _BV(SPI_S_CLK)) {
		// HIGH to LOW transition - change state
		
		if (hs_ended) {
			initSPISlave();
		}
	} else {
		// LOW to HIGH transition - sample
		
		// if data-in is high, handshake has ended
		if (!!(SPI_S_DI_REG & _BV(SPI_S_DI))) {
			hs_ended = 1;
		}
	}
}

void serviceSpiSlaveTransmission(uint8_t changedPins) {
	
	if (changedPins & _BV(SS_F_BELOW)) {
		
		// trigger from below
		if (prev_pin_b & _BV(SS_F_BELOW)) {
			// transmission started, remove SS_F_LEFT interrupt
			trig_f_below = 1;
			SPI_PCMSK &= ~_BV(SPI_F_L_PCINT);
			
			// put MSB on slave data out if implemented
#ifdef SPI_S_DO
			if (s_data_out_pos--) {
				PORTA = (PORTA & ~_BV(SPI_S_DO)) | ((spi_s_data_out >> s_data_out_pos) & _BV(SPI_S_DO));
			}
#endif
			
		} else {
			// end of receive
			rx_completed = 1;
		}
	} else if (changedPins & _BV(SS_F_LEFT)) {
		
		// trigger from left
		if (prev_pin_b & _BV(SS_F_LEFT)) {
			// transmission started, remove SS_F_BELOW interrupt
			trig_f_left = 1;
			SPI_PCMSK &= ~_BV(SPI_F_B_PCINT);
			
			// put MSB on slave data out if implemented
#ifdef SPI_S_DO
			if (s_data_out_pos--) {
				PORTA = (PORTA & ~_BV(SPI_S_DO)) | ((spi_s_data_out >> s_data_out_pos) & _BV(SPI_S_DO));
			}
#endif
			
		} else {
			// end of receive
			rx_completed = 1;
		}
	} else if (changedPins & _BV(SPI_S_CLK)) {
		
		// SPI mode 0: CPOL = 0, CPHA = 0
		if (prev_pin_b & _BV(SPI_S_CLK)) {
			
			// HIGH to LOW - update (if implemented)
#ifdef SPI_S_DO
			if (s_data_out_pos--) {
				PORTA = (PORTA & ~_BV(SPI_S_DO)) | ((spi_s_data_out >> s_data_out_pos) & _BV(SPI_S_DO));
			}
#endif
			
		} else {
			// LOW to HIGH - sample
			if (s_data_in_pos--) {
				spi_s_data_in |= (!!(SPI_S_DI_REG & _BV(SPI_S_DI)) << s_data_in_pos);
			}
		}
	}
}

void serviceMasterHandshake(uint8_t changedPins) {
	
	uint8_t from_above = 0;
	uint8_t from_right = 0;
	
	if (changedPins & _BV(SS_T_ABOVE)) {
		if (prev_pin_b & _BV(SS_T_ABOVE)) {
			// HIGH to LOW - end handshake
			
		} else {
			// LOW to HIGH - start handshake
			
			from_above = 1;
		}
	} else if (changedPins & _BV(SS_T_RIGHT)) {
		if (prev_pin_b & _BV(SS_T_RIGHT)) {
			// HIGH to LOW - end handshake
			
		} else {
			// LOW to HIGH - start handshake
			
			from_right = 1;
		}
		
	}
	
	// start handshake
	if (from_above || from_right) {
		
		SPI_M_DO_REG |= _BV(SPI_M_DO);
		SPI_M_DO_REG |= _BV(SPI_M_CLK);
		_delay_ms(m_clk_ms);
		SPI_M_DO_REG &= ~_BV(SPI_M_CLK);
		SPI_M_DO_REG &= ~_BV(SPI_M_DO);
		_delay_ms(m_clk_ms);
		
		SPI_M_DO_REG |= _BV(SPI_M_CLK);
		_delay_ms(m_clk_ms);
		SPI_M_DO_REG &= ~_BV(SPI_M_CLK);
		_delay_ms(m_clk_ms);
		
		SPI_M_DO_REG |= _BV(SPI_M_DO);
		SPI_M_DO_REG |= _BV(SPI_M_CLK);
		
		// set corresponding slave select as output
		uint8_t slave = _BV((from_above) ? (SPI_T_A_DIR) : (SPI_T_R_DIR));
		SPI_M_DDR	 |= slave;
		
		// pull HIGH to prepare for tx
		SPI_M_PORT	 |= slave;
		_delay_ms(m_clk_ms);
		
		SPI_M_DO_REG  &= ~_BV(SPI_M_CLK);
		SPI_M_DO_REG &= ~_BV(SPI_M_DO);
		_delay_ms(m_clk_ms);
		
		sendVector(slave);
	}
}

void sendVector(uint8_t newBlockDirection) {
	
	//	cur_state = SpiMaster;
	
	
	TOGGLE_STATUS;
	_delay_ms(m_clk_ms);
	TOGGLE_STATUS;
	_delay_ms(m_clk_ms);
	TOGGLE_STATUS;
	_delay_ms(m_clk_ms);
	TOGGLE_STATUS;
	_delay_ms(m_clk_ms);
	
	
	// pull slave select LOW to signal tx start
	SPI_M_PORT &= ~newBlockDirection;
	
	// put bits on data out line
	while (m_data_out_pos--) {
		SPI_M_DO_REG = (SPI_M_DO_REG & ~_BV(SPI_M_DO)) | (((i2c_addr >> m_data_out_pos) & 0b00000001) << SPI_M_DO);
		
		// pulse clock
		SPI_M_DO_REG |= _BV(SPI_M_CLK);
		_delay_ms(m_clk_ms);
		SPI_M_DO_REG &= ~_BV(SPI_M_CLK);
		_delay_ms(m_clk_ms);
	}
	
	// reset position
	m_data_out_pos = 8;
	
	// pull HIGH to signal end of tx
	SPI_M_PORT |= newBlockDirection;
}

/**
 *  Interrupt Service Routine for Pin Change in PCIE (PORTB).
 */
ISR(PCINT_vect) {
	// isolate changed pins
	uint8_t changed = SPI_S_PIN_REG ^ prev_pin_b;
	
	switch (cur_state) {
		// handshake initiated
		case StartHandshake:
			if (changed & _BV(SPI_S_CLK)) {
				serviceHandshakeStart();
			}
			break;
			
		// handshake completing
		case EndHandshake:
			if (changed & _BV(SPI_S_CLK)) {
				serviceHandshakeEnd();
			}
			break;
			
		// soft SPI slave select triggers
		case SpiSlave:
			serviceSpiSlaveTransmission(changed);
			break;
			
		// starting SPI Master handshake
		case SpiMasterHandshake:
			serviceMasterHandshake(changed);
			break;
			
		default:
			break;
	}
	
	// set i2c address if vector byte received
	if (rx_completed) {
		
		// reset positions
#ifdef SPI_S_DO
		s_data_out_pos = 8;
#endif
		
		s_data_in_pos = 8;
		
		// assign address from transmitted byte (vector)
		// position structure: bits [2:0] are x-coord, [6:3] are y-coord
		// set x-coord [2:0], increment if triggered from the left
		i2c_addr |= (spi_s_data_in & 0b00000111) + (trig_f_left);
		
		// set y-coord [6:3], increment if triggered from below
		i2c_addr |= (spi_s_data_in & 0b01111000) + (trig_f_below << 3);
		
		showAddress();
		setup_i2c(i2c_addr);
		
		initSPIMaster();
		
		// disable pin change interrupts (PCI)
//		PCMSK &= ~_BV(PCINT2);			// clk pin
//		PCMSK &= ~_BV(PCINT6);			// slave select from below
//		PCMSK &= ~_BV(PCINT4);			// slave select from left
//		GIMSK &= ~_BV(PCIE);			// PORTB
//		return;
	}
	
	// update history
	prev_pin_b = SPI_S_PIN_REG;
}

void showAddress(void) {
	//	TOGGLE_ERROR;

	#ifdef MCU_2313
	PORTD &= 0b11110000;
	PORTD |= (i2c_addr & 0b00000011);
	PORTD |= ((i2c_addr & (0b00000011 << 3)) >> 1);
	//	spi_s_data_in = 0;
	//	i2c_addr = 0;
	//	rx_completed = 0;
	#endif
	#ifdef MCU_461
	PORTA &= 0b11001001;
	PORTA |= ((i2c_addr << 1) & 0b00000110);
	PORTA |= ((i2c_addr << 1) & 0b00110000);
	//	spi_s_data_in = 0;
	//	i2c_addr = 0;
	//	rx_completed = 0;
	#endif
}

void initIO(void) {
	// set output pins
	#ifdef MCU_2313
	DDRA |= _BV(PD0);
	DDRA |= _BV(PD1);
	DDRA |= _BV(PD2);
	DDRA |= _BV(PD3);
	DDRA |= _BV(STATUS_LED);
	DDRA |= _BV(ERROR_LED);
	#endif
	#ifdef MCU_461
	DDRA |= _BV(PA1);
	DDRA |= _BV(PA2);
	DDRA |= _BV(PA4);
	DDRA |= _BV(PA5);
	DDRA |= _BV(STATUS_LED);
	DDRA |= _BV(ERROR_LED);
	#endif
}

void startupSequence(void) {
	#ifdef MCU_2313
	for(int i = 0; i < 4; ++i){
		_delay_ms(25);
		PORTD |= _BV(PD0 + i);
	}
	for(int i = 0; i < 4; ++i){
		_delay_ms(25);
		PORTD &= ~_BV(PD0 + i);
	}
	#endif
	#ifdef MCU_461
	PORTA |= _BV(PA1);
	_delay_ms(25);
	PORTA |= _BV(PA2);
	_delay_ms(25);
	PORTA |= _BV(PA4);
	_delay_ms(25);
	PORTA |= _BV(PA5);
	_delay_ms(25);
	PORTA &= ~_BV(PA1);
	_delay_ms(25);
	PORTA &= ~_BV(PA2);
	_delay_ms(25);
	PORTA &= ~_BV(PA4);
	_delay_ms(25);
	PORTA &= ~_BV(PA5);
	_delay_ms(25);
	#endif
}

void waitForCompletedHandshake(void) {
	uint8_t left = 1;
	
	// bring SS_F_LEFT or SS_F_BELOW to HIGH
	SPI_S_PORT |= _BV((left) ? (SS_F_LEFT) : (SS_F_BELOW));
	
	// master processor may be busy
	_delay_ms(25);
	
	// spin until handshake has been recognized
	while (cur_state == StartHandshake && !hs_started) {

		// disable clock pin change interrupt
		SPI_PCMSK &= ~_BV(SPI_S_CLK_PCINT);
		
		// bring SS_F_LEFT or SS_F_BELOW back down LOW
		SPI_S_PORT &= ~_BV((left) ? (SS_F_LEFT) : (SS_F_BELOW));
		
		// give more time to finish
		_delay_ms(25);
		
		// re-eneable clock pin change interrupt
		SPI_PCMSK |= _BV(SPI_S_CLK_PCINT);
		
		// toggle to other input select
		left = !left;
		
		// bring SS_F_LEFT or SS_F_BELOW to HIGH
		SPI_S_PORT |= _BV((left) ? (SS_F_LEFT) : (SS_F_BELOW));
		
		// master processor may be busy
		_delay_ms(25);
		
		TOGGLE_ERROR;
	}
}

void WDT_off(void) //disable watchdog timer may be 461 specific
{
	//_WDR(); //atmel docs
	/* Clear WDRF in MCUSR */
	MCUSR = 0x00;
	/* Write logical one to WDCE and WDE */
	WDTCR |= (1<<WDCE) | (1<<WDE);
	/* Turn off WDT */
	WDTCR = 0x00;
}

int main(void) {
	
	WDT_off(); 
	initIO();
//	initSPISlave();
	startupSequence();

	initHandshake();
	waitForCompletedHandshake();

	PORTA &= 0b11000000;
	
	while (loop_i2c()) {
		TOGGLE_STATUS;
	}
	_delay_ms(20);
	return 0; // never reached
}

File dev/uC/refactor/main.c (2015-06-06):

/**
 *	main.c
 *	A Block of Code
 *	PSU Capstone with Erebus Labs
 *
 *	Spring 2015
 *	v1.1
 */

#include "abc_daisy.h"		// daisy chain locationing
#include "i2c_slave.h"		// global bus identification and communication
#include "func_select.h"	// function selection input

#define INPUT_BLOCK		0
#define POTENTIOMETER	1
#define TESTING_BLOCK	0

// hard-coded test values for prototyping

#if POTENTIOMETER
#else
typedef enum {
	None,
	A_Var,
	Colon,
	Three,
	Print
} BlockFunc;

static const BlockFunc function = 8;
#endif


typedef enum {
	ValueTokens,
	OperatorTokens,
	ControlTokens,
	StatementTokens
} TokenCategories;

static const TokenCategories category = ControlTokens;

/**
	Read Commands from the global bus. Used as bit masks to add tasks to the 
	work queue, serviced in main loop.
 */
typedef enum {
	ReadDataCommand,
	SendVerticalCommand,
	SendHorizontalCommand,
	StatusLedOnCommand,
	StatusLedBlinkCommand,
	StatusLedOffCommand,
	ErrorLedOnCommand,
	ErrorLedBlinkCommand,
	ErrorLedOffCommand,
	Reset,
	AuxiliaryRead,
	
	ReadCommandCount	// Unused, always last
} ReadCommands;

static volatile uint16_t workQueue	= 0;
static volatile uint8_t	tOVCount	= 0;
static volatile uint8_t	tCountFlag	= 0;
static volatile uint8_t statusLED	= 0;
static volatile uint8_t errorLED	= 0;
static volatile uint8_t firstRead	= 1;

static void initIO(void);
#if TESTING_BLOCK
static void startupSequence(void);
#endif
static uint8_t GlobalBusCommand(uint8_t command);
static uint8_t ABCReadData(void);
static void serviceWorkqueue(void);
static inline void initTimer(void);
static inline void enableTimer(void);
static inline void disableTimer(void);

#if INPUT_BLOCK
static uint8_t ABCAuxiliary(void);
#endif

int main(void) {
	// initialization
	initIO();
//	startupSequence();
//	startupSequence();
	
	workQueue |= _BV(StatusLedBlinkCommand);
	serviceWorkqueue();
	
	// enable interrupts
	sei();

	
#if TESTING_BLOCK
	uint8_t addr = 42;
#else
	// spin until position received from connected block (or main processor)
	uint8_t addr = waitForVector();
#endif
	
	// limitations of address space says we can't have addresses
	// with MSB set (addr > 127)
	if (addr & 0b10000000) {
		workQueue |= _BV(ErrorLedBlinkCommand);
		serviceWorkqueue();
	} else {
		workQueue |= _BV(StatusLedOnCommand);
		
		// assign function pointer to use custom data-collector function
		GetData_ptr GlobalFunc_ptr = GlobalBusCommand;
		
		// assign received vector to i2c initialization
		setup_i2c(addr, GlobalFunc_ptr);
	}
	

//	STATUS_PORT &= ~_BV(STATUS_LED);
	
	// continuously poll i2c for commands
	while (loop_i2c()) {
		serviceWorkqueue();
		
#if TESTING_BLOCK
#else
		updateChain();
#endif
		
#if POTENTIOMETER
		ADCSRA |= _BV(ADSC);
#endif
		
		// timer led blink?
	}
	return 0; // never reached
}

void initIO(void) {
	
	// disable WDT as necessary after reset
	MCUSR = 0;
	WDTCR |= _BV(WDE) | _BV(WDCE);
	WDTCR  = 0;

#if POTENTIOMETER
	// start adc
	setup_adc();
#endif
	
	// setup timer
	initTimer();
	
	// set output pins
	DDRA |= _BV(STATUS_LED);
	DDRA |= _BV(ERROR_LED);
}

/**
 *	Timer counts to 0.5 second by using a prescaler and overflow,
 *	(8,000,000Hz/128 prescaler/250 overflows/125 times).
 */
void initTimer(void) {
	
	TCCR1B  |= _BV(CS13);				// presaler to 64
	TIFR	|= _BV(TOV1);				// set overflow interrupt
	TCNT1	 = 0;						// initialize counter to zero
}

void enableTimer(void) {
	
	TIMSK	|= _BV(TOIE1);				// set interrupt enable flag
}

void disableTimer(void) {
	if (statusLED | errorLED) {
		return;
	}
	TIMSK	&= ~_BV(TOIE1);				// clear interrupt enable flag
}

ISR(TIMER1_OVF_vect) {
	++tOVCount;
	if (tOVCount >= 64) {
		if (statusLED) {
			TOGGLE_STATUS();
		}
		tOVCount = 0;
		++tCountFlag;
		if (tCountFlag >= 2) {
			if (errorLED) {
				TOGGLE_ERROR();
				tCountFlag = 0;
			}
		}
	}
}

void startupSequence(void) {
	TOGGLE_STATUS();
	_delay_ms(100);
	TOGGLE_ERROR();
	_delay_ms(100);
	TOGGLE_STATUS();
	_delay_ms(100);
	TOGGLE_ERROR();
	_delay_ms(100);
}

static uint8_t GlobalBusCommand(uint8_t command) {
	if ((command < ReadCommandCount) && (command < 16)) {
		workQueue |= _BV(command);
	}
	
	// provide input value back to lexer
#if INPUT_BLOCK
	if (command == AuxiliaryRead) {
		return ABCAuxiliary();
	}
#endif
	
	// supply standard block data back to lexer
	return ABCReadData();
}

#if INPUT_BLOCK
static uint8_t ABCAuxiliary(void) {
	return (adjacentBlocks() | read_adc());
}
#endif

static uint8_t ABCReadData(void) {
#if INPUT_BLOCK
	return (adjacentBlocks() | (category << 4) | 0b00001111);
#elif POTENTIOMETER
	return (adjacentBlocks() | (category << 4) | read_adc());
#else
	return (adjacentBlocks() | (category << 4) | function);
#endif
}

static void serviceWorkqueue(void) {
	// Read
	if (workQueue & _BV(ReadDataCommand)) {
		workQueue &= ~_BV(ReadDataCommand);
		
		// light LED on first lexer read
		if (firstRead) {
			STATUS_PORT |= _BV(STATUS_LED);
			firstRead = 0;
		}
	}
	
	// Send Vertical
	if (workQueue & _BV(SendVerticalCommand)) {
		sendDaisyChainVertical();
		workQueue &= ~_BV(SendVerticalCommand);
	}
	
	// Send Horizontal
	if (workQueue & _BV(SendHorizontalCommand)) {
		STATUS_PORT |= _BV(STATUS_LED);
		sendDaisyChainHorizontal();
		workQueue &= ~_BV(SendHorizontalCommand);
	}
	
	// Status On
	if (workQueue & _BV(StatusLedOnCommand)) {
		statusLED = 0;
		disableTimer();
		STATUS_PORT |= _BV(STATUS_LED);
		workQueue &= ~_BV(StatusLedOnCommand);
	}
	
	// Status Blink
	if (workQueue & _BV(StatusLedBlinkCommand)) {
		statusLED = 1;
		enableTimer();
		workQueue &= ~_BV(StatusLedBlinkCommand);
	}
	
	// Status Off
	if (workQueue & _BV(StatusLedOffCommand)) {
		statusLED = 0;
		disableTimer();
		STATUS_PORT &= ~_BV(STATUS_LED);
		workQueue &= ~_BV(StatusLedOffCommand);
	}
	
	// Error On
	if (workQueue & _BV(ErrorLedOnCommand)) {
		errorLED = 0;
		disableTimer();
		ERROR_PORT |= _BV(ERROR_LED);
		workQueue &= ~_BV(ErrorLedOnCommand);
	}
	
	// Error Blink
	if (workQueue & _BV(ErrorLedBlinkCommand)) {
		errorLED = 1;
		enableTimer();
		workQueue &= ~_BV(ErrorLedBlinkCommand);
	}
	
	// Error Off
	if (workQueue & _BV(ErrorLedOffCommand)) {
		errorLED = 0;
		disableTimer();
		ERROR_PORT &= ~_BV(ERROR_LED);
		workQueue &= ~_BV(ErrorLedOffCommand);
	}
	
	// Reset MCU
	if (workQueue & _BV(Reset)) {
		// do any other work as necessary...
		workQueue &= ~_BV(Reset);
		WDTCR |= _BV(WDE);
	}
	
	// Auxiliary Read
	if (workQueue & _BV(AuxiliaryRead)) {
		// do any other work as necessary...
		workQueue &= ~_BV(AuxiliaryRead);
	}
}

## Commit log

2014-04-23 Add output classes for lcd backlight control and buzzer
    Create template class for error filtering
    [buzzer.py, error.py, filter.py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]
2014-12-29 Initial implementation of emulator
    Implemented:
    * Expressions
    * Operators
    * Variables
    TODO:
    * Blocks
    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
2014-12-31 Implement blocks and control flow
    Add proper support for optional terminators (eg `;` vs. `\n`), and
    block-scope specifiers `{}`. Statement lists return the last
    expression.
    Add if and if..then statements.
    Add while, do..while and repeat loops.
2015-02-19 Connector illustration and short write up for details discussed during 15FEB15 weekly meeting.
2015-02-23 Boards ready for first run
    [20pin - Bottom Copper.gbr, 20pin - Drill Data - [Through Hole] (Unplated).drl, 20pin - Drill Data - [Through Hole].drl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]
2015-03-06 Working software spi for 2313
2015-03-27 Extended daisychain code with more uC pin definitions
2015-04-08 First pass for 461 layout using the drawing for edge mounting the DB9 connectors. Schematic is missing the reset push button and associated resistor (not in my current library). Extra pin header foot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
    [Edge_Con_461.brd, Edge_Con_461.sch]
2015-04-10 Layout in progress, one footprint needs to be added to 461_Edge Connect prior to cut.
    [Edge_Con_461.brd, Edge_Con_461.sch]
2015-04-10 Edge Connect Layout Complete V1.0, 3 Jumper Function Select, 2 LED spaces available, Push Button Reset.
    [Edge_Con_461.brd, Edge_Con_461.sch]
2015-04-10 Combined BBB daisy and i2c code
2015-04-11 Moved Pull-up resistor to be pull up resistor on Edge Connect 461 board.
    [Edge_Con_461.brd, Edge_Con_461.sch]
2015-04-16 i2c testing
2015-04-25 Pull daisy chain to separate files, implement #73 handshake
2015-04-25 updated slave addressing
    #defines in main.c for i2c_address ,block function,x,y
2015-04-26 v1.1 Edge Connect Prototype Board Changes: Widened power and ground traces. Added power LED indicator. Increased all via diameters for easier plating.
    [Edge_Con_461.brd, Edge_Con_461.sch]
2015-05-03 Working daisy chain! Will clean up, confirm breadboard functionality, and integrate on proto-blocks
2015-05-03 Integrated #73 handshake with i2c framework #76, will try proto-blocks soon.
2015-05-06 SMD Breakout In progress upload.
    [Edge_Con_Frame.sch, SMD_Breakout.brd, SMD_Breakout.sch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]
2015-05-09 Begin output coding
    Create filter class
2015-05-13 SMD Breakout with layout complete ( all pins to the frame board with global reset). Board progress issue updated with pinouts and layout guide for design review.
    [SMD_Breakout.brd, SMD_Breakout.sch]
2015-05-13 Uploading SMD breakout v1.1 (.1inch headers).
    [SMD_Breakout_1.brd, SMD_Breakout_1.sch, SMD_Breakout_2.brd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]
2015-05-15 Created data sheet directory inside documents. Added 461 datasheet and db9 through hole tech drawings. Added DB9 to programmer board.
    [programmer.brd, programmer.sch]
2015-05-16 adc testing
    A guess at making the adc work
2015-05-16 New full sized boards, schematic-PDF, circuit-pdf, images for wiki etc.
    [BlockBoard - Bottom Copper (Paste).gbr, BlockBoard - Bottom Copper (Resist).gbr, BlockBoard - Bottom Copper.gbl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]
2015-05-17 led control
    status and error leds now are controllable on i2c #87
    [abc_daisy.c, abc_daisy.h, adc_standalone.c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]
2015-05-18 clean up of board
    [BlockBoard2 - Bottom Copper (Paste).gbr, BlockBoard2 - Bottom Copper (Resist).gbr, BlockBoard2 - Bottom Copper.gbr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]
2015-05-20 made some more edits to board @dfrister --nice catch -- use BlockBoard folder
    [BlockBoard - Bottom Copper (Paste).gbr, BlockBoard - Bottom Copper (Resist).gbr, BlockBoard - Bottom Copper.gbl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]
2015-05-20 50 Run Order information and BOM
    [Circuit_Board_BOM.xls]
2015-05-22 Updated programmer board to match BB2 Pinouts.
    [programmer.brd, programmer.sch]
2015-05-22 Created Test Plan folder with basic connectivity test plans inside.
    [Hardware-1.ods, Hardware-2.ods]
2015-05-22 work for the wheel
    periodic ADC reads getting returned in the combined byte
2015-05-23 Modularized daisychain, i2c, and adc code and integrated. Confirmed working on 4 proto-blocks
2015-05-24 Added Hardware 3 (programmer board), and modified wording and spacing on hardware 1 and 2. Exported each to pdf for ease of reading.
    [Hardware-1.ods, Hardware-2.ods, Hardware-3.ods]
2015-05-24 Removed duplicate gerber files from Old boards (BB v2.1 files). Fixed spelling on directory.
    [BlockBoard - Bottom Copper (Paste).gbr, BlockBoard - Bottom Copper (Resist).gbr, BlockBoard - Bottom Copper.gbl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]
2015-05-24 Consolidated BlockBoard and Blockboard2 into a single file. Currently .sch and .pcb files are v2.1 and gerber files are v2.2. Awaiting push to update .sch and .pcb to v.2.2.
    [BlockBoard2 - Bottom Copper (Paste).gbr, BlockBoard2 - Bottom Copper (Resist).gbr, BlockBoard2 - Bottom Copper.gbr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]
2015-05-29 Adding test plan template and software tests 1/2 drafts.
    [Software_1.ods, Software_2.ods, Template.ods]
2015-05-29 testing wheel
    modified BBB code to observe a single block's adc value
2015-05-31 cape is running alternates included and comming
    [BBBCape.brd, BBBCape.sch, BBBCapeWithBat.brd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]
2015-05-31 a selector wheel
    0-F on a wheel, t_adc_range.py returns the listed values
2015-05-31 Updated adc test
2015-05-31 61mm Inside diameter drawing for BB2 blocks. Has 1mm offset in connector location to account for difference in male/female total length. Tested with 1 cut so far, block matches hardware. Top panel ha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
2015-06-01 all wheels draft
    four category wheels to match to abc_lexer.py
2015-06-02 Pulled code out of ISRs, started timer work.
2015-06-02 Chain with 8 blocks, but one at a time?
2015-06-03 Seems to be working except for adjacency, should be quick fix (why did I just jinx it...)
    [abc_daisy.c, main.c]
2015-06-03 Create classes for run/display buttons
2015-06-03 Confirmed working on 16 boards, added i2c bounds checking. #88 #100
2015-06-03 Update of enclosure drawing after adding LED holes and adjustments to pot mounting spacing.
2015-06-05 correcting mistakes on wheel
    fixed rotation of minus and divide on operator wheel
2015-06-06 fixed cape design, no vias on two layer, no mod wires needed
    [RevisedCape.brd, RevisedCape.sch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]

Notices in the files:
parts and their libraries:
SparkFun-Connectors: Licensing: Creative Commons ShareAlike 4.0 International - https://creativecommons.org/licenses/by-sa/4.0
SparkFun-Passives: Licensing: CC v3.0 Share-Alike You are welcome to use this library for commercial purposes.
